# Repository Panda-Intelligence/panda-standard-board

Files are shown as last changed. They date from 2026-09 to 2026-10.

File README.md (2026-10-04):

# Panda Standard Board

Open hardware design sources and engineering documentation for the **Panda Standard Board**, maintained by Panda Intelligence.

## Active Split-C1 prototype and mainland IC continuation

The active continuation is the populated **Core-C1 96 x 68 mm / 4-layer** plus
**Display-C1 45 x 36 mm / 2-layer** design already split and routed on main.
Start with [Split-C1 handoff](hardware/thin18-compact/SPLIT-C1-HANDOFF.md) and the
[PG/PSEL functional migration](hardware/thin18-compact/SPLIT-C1-POWER-INTEGRITY.md).
Do not replace it with Thin7/portrait-R2 experimental CAD merely because an
experiment has a newer timestamp. Thin7 remains a separate, incomplete 7-mm
mechanical target and is not claimed by the Split-C1 bench prototype.

Generate checked prototype data explicitly:

```sh
python3 hardware/thin18-compact/release_split_c1.py --target split-c1
```

Bare-board CAM/DFM, accepted PCBA supply and physical EVT are separate gates.
The new supervisor is a mainland part, but its exact assembly code/receipt is
not yet confirmed. No production qualification or actual purchase is implied.

## Historical published Thin18 baseline

The earlier published integrated-board engineering baseline was:

- **Board:** Thin18 domestic EVT
- **PCB checkpoint:** `routing142`
- **PCB SHA-256:** `ccc19c5402f633638ed72e7c94a92375684037a1f9c04f63072dc58f86c16071`
- **KiCad validation:** 0 DRC violations, 0 unconnected items, 0 schematic-parity errors; ERC 0
- **Status:** engineering / EVT — **not a manufacturing release**

The baseline includes the current right-side microSD access geometry. Manufacturing, assembly, SI/PI, RF, thermal, tolerance-stack and physical EVT qualification remain separate release gates.

## Repository layout

```text
hardware/
  thin18/
    routing142/        Current KiCad engineering baseline and machine-readable verification evidence
docs/
  design/              Electrical architecture, interfaces, power tree, constraints and design rules
  verification/        ERC/layout/fabrication-readiness engineering reviews
  mechanical/          Board/mechanical interface review notes
LICENSES/
```

## Opening the active two-board design

The design was validated with **KiCad 10.0.5**. Open the complete project under:

```text
hardware/thin18-compact/core-c1-96x68-split/eda/core/PANDA-STD-CORE-EVT/PANDA-THIN16/
hardware/thin18-compact/display-c1-45x36-production-bom/
```

Project-local symbol and footprint libraries are included where the design depends on them.

## Product visualization

Explore the [interactive Thin18 routing142 assembly model](hardware/thin18/routing142/visualization/Panda-thin18-routing142-exploded.html) or watch the [exploded-view video on YouTube](https://youtu.be/T_Nb8tvqas8).

The model is an engineering visualization for design communication. Mechanical fit and manufacturing readiness require separate validation.

## Verification boundary

A clean KiCad DRC/ERC result means the design database is internally consistent. It does **not** establish production qualification, regulatory compliance, component derating, RF performance, thermal margin, assembly yield or mechanical fit of real production parts.

Use tagged manufacturing releases, when available, for fabrication rather than assuming the newest engineering checkpoint is production-ready.

## Licensing

Hardware design sources: **CERN-OHL-S-2.0**.

Documentation: **CC BY-SA 4.0**, unless otherwise noted.

Third-party component models, symbols, footprints, manufacturer names and trademarks retain their respective rights and licensing terms.

## Split-C1 executable control follow-up

[Portable bench-control core](firmware/split_c1/README.md) implements tested
XL9535/SGM41513/SGM37601 sequencing and a read-only QMI8658A identity probe.
Host tests and native pin/address binding checks run in the explicit Split-C1
export pipeline. This is not product-firmware integration or physical EVT.
The [hardware-finish ECO](hardware/thin18-compact/SPLIT-C1-HARDWARE-FINISH.md) adds default-off charge authorization and a native GPIO2 shutdown path.
Read the updated control binding before using any older firmware. Physical EVT and accepted assembly supply remain separate gates.

## Current fabrication entry

The combined review package contains a generated `START-HERE.md`; use its
separate Core/Display Gerber paths and source hashes. The
[fabrication handoff](hardware/thin18-compact/JLC-PROTOTYPE-HANDOFF.md) now matches
the native four-layer35um Core copper construction and ENIG/green-mask selection.
C301 now has checked1.9mm round PTHs instead of short slots; the actual stackup
and assembly process still need CAM acceptance.
Native DRC/DFM success is not automatic fabrication/PCBA order approval.

## Split-C1 SMT process selection

The native [assembly-process auditor](hardware/thin18-compact/audit_split_c1_assembly_process.py)
and its tests now run before fabrication export. Core contains13 drilled vias
intersecting SMT copper lands; its order must explicitly include epoxy filling
and copper capping for the generated list. This is distinct from soldermask
tenting/plugging and must not fill component lead holes or slots. The generated
prototype package includes ASSEMBLY-PROCESS.md and per-board VIA-IN-PAD.csv,
bound to the saved PCB and checked against Excellon drill hits. Small WLCSP and
connector lands retain ENIG and need assembler stencil/process confirmation.
No source copper is changed by this audit; supplier acceptance is still required.

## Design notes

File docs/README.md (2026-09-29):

# Documentation index

## Design

- `schematic-spec.md` — board-level electrical design specification
- `power-tree.md` — power architecture and domain behavior
- `interfaces-and-connectors.md` — external and internal interfaces
- `gpio-budget.md` / `i2c-address-map.md` — digital-resource allocation
- `layout-constraints.md` — PCB layout constraints
- `key-calculations.md` / `power-datasheet-calculations.md` — engineering calculations
- `test-points.md` — EVT/debug access strategy
- `symbol-footprint-rules.md` / `symbol-footprint-checklist.md` — EDA library rules

## Verification

Engineering reviews and machine-check boundaries. These documents do not constitute manufacturing release.

## Mechanical

Board-to-enclosure and connector-access review notes.

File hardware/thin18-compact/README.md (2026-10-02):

# Thin18 Compact EVT

## Current product requirement — Thin7 (2026-10-02)

The user requires about **7 mm whole-device thickness**. The previous 21 mm
side-pack study is superseded. See [Thin7 redesign](thin7/THIN7-REDESIGN.md)
and the dimensioned contract. The two routed Split-C1 boards below remain
electrical references; they do **not** satisfy the new mechanical requirement.
Thin7 contains two empty mechanical outline templates, not routed PCBs.
`release_split_c1.py` now rejects the incompatible native CAD before creating
new factory packages. Core relayout, high-part ECOs and battery qualification
are still required.

## Current native electrical reference — Split-C1 (2026-10-02)

The current PCB authorities are core-c1-96x68-split and
display-c1-45x36-production-bom. The Core is 96 x 68 mm / four copper layers;
Display is 45 x 36 mm / two layers. Both boards are 0.8 mm thick and pass
native KiCad DRC/open/parity/ERC = 0/0/0/0.

Run `python3 hardware/thin18-compact/release_split_c1.py` to generate local
production/core-c1-96x68 and production/display-c1-45x36 packages, with
production/split-c1-release.json as their combined hash-checked record.
Generated packages are ignored; the committed authorities are native CAD,
required libraries, replay scripts, purchasing evidence and audit summaries. Every populated BOM ref has Manufacturer and exact MPN.
Current all-domestic audit:155/155 populated system-BOM refs,0 foreign/unknown.
Core has116 SMT placements plus hand-solder C301 and offboard TH301;Display37.
Last foreign refs now use WAVE SD3078/C916255,KAMCAP SE-5R5-D105VYH3C/C2894294
and JSM NX3008NBK,215-JSM/C53113911. Symbols,primary/derived lands and copper
are replayed from guarded source ECOs. R303/R304 are removed.

Exact SMT library coverage:Core110/116,Display37/37. Six Core refs
(U902,U905,U402-U405) still require exact JLC ID/consignment acceptance.
C301 exact current H3C catalog/drawing verified;quantity unverified. D202 observation0;no reserved/accepted supply.
audit_split_c1_domestic.py --require-complete passes identity coverage;
PCBA supply/order readiness remains false.

See SPLIT-C1-DOMESTICIZATION.md and JLC-PROTOTYPE-HANDOFF.md for current
decisions. RTC >=24h isolated backup is a pending prototype validation,
with a2uA total-node engineering target and measured start>=3.15V/end>=2.3V.
Firmware port is required;Q04-Q14 remainNOT_RUN because no board exists.
The historical two-board side-pack study was112x75x21mm (20.5mm budget)
and is rejected for the Thin7 product. Thin7 targets112x75x7.0mm with a
62x51x3.1mm complete-pack maximum requirement. Exact pack/supplier dimensions
and the new PCB layout are not qualified; no physical fit is claimed.
X4 Pro1100mAh/5.95mm remains a reference. Manufacturing release remains false.
Older C0/C2/C4D notes below are historical and do not override Split-C1.

Thin18 Compact is an architecture fork of the validated `thin18/routing142` baseline.

## Goal

Reduce the main PCB below the JLC 100 × 100 mm coupon boundary while making the product materially shorter, without changing the electrical feature set.

C0 target:

- PCB: **70 × 64 mm** placement-feasibility candidate
- hard coupon boundary: every PCB side < 100 mm
- layers: 4
- thickness: 0.8 mm
- finish target: ENIG
- production solder mask target: green
- display architecture: raw 4.26-inch SSD1677 panel through 24-pin / 0.5-mm FPC
- display candidate family: Good Display GDEY0426T82; front-light/touch derivatives require separate stack-up and pin/FPC qualification
- screen, battery and PCB are separate mechanical objects; the PCB no longer follows the panel length

## C0 fold strategy

The routing142 placement already has two dense functional regions:

- y < 31 mm: power, battery/gauge/RTC, audio, microSD, switches
- y > 100 mm: USB-C, ESP32, display power/FPC, protection

Only five footprints occupy the 30–100 mm middle band, two of which are mounting holes. C0 folds the upper region down by 64 mm, keeps the lower region, relocates mounting holes, reduces the board outline to 70 × 64 mm, and intentionally removes all legacy tracks/vias/zones.

This candidate is **placement-only and NOT routed**. routing142 remains the authority for the old form factor.

## Gates before routing

1. no footprint/edge impossibility after connector-specific edge allowances;
2. no unintended footprint overlap;
3. schematic population and pin/net parity unchanged;
4. ERC remains zero;
5. battery/display/enclosure Z-stack is frozen;
6. exact display FPC pinout and front-light/touch variant are frozen;
7. USB-C, microSD, side switches, display FPC and antenna cable exits are mechanically frozen.

Do not fabricate the C0 board.
精确供料跟进：SPLIT-C1-SUPPLY-REQUEST.md、split-c1-supply-plan.json。verify_split_c1_supply.py核对本次8个位号的精确身份、实际回执／数量和C301独立后装路线；不把公开库存或采购准备当作完整PCBA接收。

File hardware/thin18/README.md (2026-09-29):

# Thin18

`routing142` is the currently published engineering baseline.

It is a complete isolated KiCad project snapshot used for reproducible review. Its authority PCB hash is:

`ccc19c5402f633638ed72e7c94a92375684037a1f9c04f63072dc58f86c16071`

The snapshot is **not** a manufacturing release. Do not infer physical qualification from DRC/ERC results.

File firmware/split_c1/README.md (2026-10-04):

# Split-C1 portable bench-control core

This is executable C++17 control logic for the already split Core-C1/Display-C1
board. It is **not** a complete Panda OS board driver or a flashed/tested ESP32
firmware image. The actual ESP-IDF bus adapter, product integration, scheduler,
USB permission events and physical qualification remain open. No current,
voltage, timing or leakage measurement has been performed by the host tests.

## Implemented behavior

`BoardControl::begin()` first drives native GPIO2 LOW, then quiesces the XL9535 outputs, keeping P14 and P15 input-only, then
checks the SGM41513 part-ID class at **7-bit address 0x1A**. It disables charge and
OTG, sets nominal IINDPM100mA, sets ICHG0, enables the40s charger watchdog and charge
safety timer, selects6.5V input OVP, and disables high-voltage current-pulse control.
It preserves unrelated register bits. A historical watchdog flag is retained in
diagnostics during explicit startup; new watchdog/fault events cause a latched
fault. No API enables battery charging, OTG, RTC charging or higher USB voltage.

The GPIO masks are derived and checked against the actual schematic and PCB:
Port0 directions `D0`, Port1 directions `3F`; quiescent latches `00` and `00`. P05 is active-high CHG_REQUEST and stays LOW. P15 is unused; HWEN is no longer an expander output.
Output latches are verified before enabling their output directions. U906's
push-pull PG output drives P14, never the MCU reset input. Switching SD/touch/EPD/
audio rails on is deliberately outside this initial control core; they stay off.

Frontlight startup is staged: HWEN1/PWM0, an engineering10ms settling interval,
then program/readback DC mode, current,18V OVP/internal compensation/2.7V UVLO and
1MHz/PFM. PWM goes high last, after all readbacks and another PG/GPIO check.
Accepted nominal shared current is6.0..14.5mA in0.1mA steps (integer60..145), or0
to turn off. This is NOT independent warm/cool control, hardware PWM dimming,
continuous dimming below6mA or a measured guarantee that each LED stays below15mA.
No nonvolatile MTP access is made. Source changes revoke a previous light request.

`poll()` monitors GPIO latches/directions/polarity, PG, charger policy, historical
and current fault reads, input-detection events, and active frontlight registers. A reset, readback
mismatch, lost PG, missed service deadline or bus failure latches an error and
attempts shutdown. A caller must explicitly restart with `begin()`; no automatic
relighting or watchdog-reset continuation is performed. A new input-detection
flag revokes a prior500mA permission even if the reset current code is unchanged.

The QMI8658A sanity probe reads WHO_AM_I0x05 at **0x6A**, because U503 SA0 is high.
It performs no reset or CTRL9 write and does not disable the internal pull-up on
reserved pin10. It does not implement sampling, FIFO, motion interrupts or
calibration. WHO_AM_I is a QST family sanity check, not a provenance certificate.

## Integration contract

Implement `RegisterBus` using bounded single-register I2C transfers,7-bit
addresses, clock-stretch/error handling and a monotonic millisecond counter.
Use the native pins **SCL GPIO14 / SDA GPIO15** and a shared bus no faster than
100kHz because the existing SD3078 contract requires that rate at3.3V. The bus
adapter must enforce the requested10ms per-transfer timeout. Every control call
and every other device's transaction must be serialized by the board owner.
There must be no second writer to these XL9535/charger/frontlight registers.

Call `poll()` at least once per1000ms, faster for the required fault response.
The10ms settle,100ms startup deadline and1000ms service deadline are conservative
engineering choices, not manufacturer timing guarantees. Calls detect elapsed
time including transfer execution. Unsigned subtraction handles clock wrap;
service must not be absent for an entire32-bit timer period. Tests run with
injected wrap, slow callbacks and expired deadlines.

Example integration structure (adapter/scheduler still needs implementation):

```cpp
panda::split_c1::BoardControl control(bus);
auto result = control.begin();
// Only an independently qualified USB/source event may grant500mA:
if (result == panda::split_c1::Result::Ok && source_has_500ma_permission) {
    result = control.set_source(panda::split_c1::SourceAllowance::Qualified500mA);
}
// set_frontlight(145) returns Pending; subsequent scheduled poll() completes it.
// On any error inspect diagnostics; do NOT automatically re-run begin().
```

Suspend/detach requests put the charger input in HIZ after deasserting the light.
That may cut system power on a batteryless board. Software100/500mA settings and
HIZ are not proof of USB enumeration, inrush, suspend-current or reset compliance.
The pre-AON PSEL divider remains a nominal reset selection, not a hard current cap.

## Hardware-finish compatibility and boundaries

Implement the two additional RegisterBus callbacks with **native GPIO2 only**:
`set_hardware_permit(bool)` and `read_hardware_permit(bool&)`. They must never
call I2C. Set the LOW output latch before enabling output direction; disable
GPIO hold and unintended pulls. Readback samples the MCU pad before R931, not
the downstream TP19 analog voltage. Older adapters intentionally cannot compile
without implementing the direct path.

The hardware now pulls nCE to pre-AON REGN, with two series MOS permissions.
P05 request and direct permit both defaultLOW; the bench controller never enables
P05. This fixes the old default-low nCE topology. Actual startup/ramp, temperature,
partial-power and charging behavior still need prototype measurement.

On I2C loss, native GPIO2 is driven LOW before attempted bus cleanup, so the
inhibit does not depend on a responsive expander. The host model now demonstrates
that path and separately tests simultaneous GPIO+I2C failure as UNKNOWN. A stuck
HIGH GPIO is not reported as confirmed shutdown. Diagnostics distinguish direct
inhibit readback from shutdown-register confirmation. None are current measurements.

A CPU frozen with GPIO2 retainedHIGH is not independently detected by this design:
use TP19 FORCE-LOW access or power removal. There is no external autonomous
watchdog. See ../../hardware/thin18-compact/SPLIT-C1-HARDWARE-FINISH.md.

## Reproduce tests and native binding checks

```sh
python3 hardware/thin18-compact/test_split_c1_control.py
python3 hardware/thin18-compact/verify_split_c1_control.py
python3 hardware/thin18-compact/release_split_c1.py --target split-c1
```

The runner compiles with warnings-as-errors and AddressSanitizer/UBSan, executes
mock transactions (no physical device), and emits a source-hash-bound report.
The checker exports a fresh native netlist, checks actual PCB pads, derives GPIO
masks, checks exact MPNs and rejects wrong-address/direction/strap variants.
`verify_split_c1_control.py --require-target-integration` intentionally exits2:
passing a host test does not complete product firmware integration.

## Primary references

SGMICRO SGM41513 family, April2025 Rev.C.1: printed pp5,23,30,32,37-46.
https://www.sg-micro.com/rect/assets/58a4fe4d-da1d-49a3-b312-5664211d9016/SGM41513_SGM41513A_SGM41513D.pdf

SGMICRO SGM37601, June2026 Rev.A.2: printed pp27-30; see product page for the
current original PDF. Exact populated variant is SGM37601YTRL20G/TR.
https://www.sg-micro.com/product/SGM37601

XINLUDA XL9535/XL9555 Rev2.3: printed pp12-14,19. Original manufacturer document;
mirror used where the manufacturer's PDF endpoint was unavailable.
https://xinluda.com/en/content/viewpdf/aid-578.html
https://wiki.lilygo.cc/datasheet/XL9535.pdf

QST QMI8658A, document13-52-25 RevA: pp11,29,83. Manufacturer document mirror.
https://files.waveshare.com/upload/5/5f/QMI8658A_Datasheet_Rev_A.pdf

See `SPLIT-C1-RTC-FIRMWARE.md` for the separate SD3078 bus/retention contract.

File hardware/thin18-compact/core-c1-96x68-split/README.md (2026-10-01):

# Core-C1 split main board

96 × 68 mm, four copper layers. Native DRC/open/parity/ERC: 0/0/0/0.
J601 is the bottom-side DF40 socket at (61,62) mm, rotation 0°.
The display adapter is removed from this PCB; Display-C1 is a separate candidate.
Active production data is ../production/core-c1-96x68/.
The inherited C4D reports are historical provenance; verification/ and the split
release record contain the current checks. j601-routing.json is search history;
core-c1-routing-closure.json freezes the final, cleaned copper.
manufacturing_release=false; physical EVT and enclosure/battery Z-stack remain open.

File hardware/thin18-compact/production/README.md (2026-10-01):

# Generated Split-C1 fabrication packages

Run `python3 hardware/thin18-compact/release_split_c1.py` from a full-history clone with KiCad 10.0.5 installed.
Outputs are generated locally under core-c1-96x68/, display-c1-45x36/ and split-c1-release.json.
Native CAD, replay inputs, purchasing evidence and validation summaries are versioned; Gerbers, ZIPs, netlists and copied per-package reports are generated and ignored.
Each generated manufacturing package includes BOM/CPL, source hashes, engineering evidence and SHA256SUMS. manufacturing_release remains false until physical qualification is complete.

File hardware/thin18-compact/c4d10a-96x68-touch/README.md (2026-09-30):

# Thin18 Compact C4D-10A — exact touch FPC

J803 uses the exact FH34SRJ-6S-0.5SH(50) / C224194 six-pin footprint. U601 P16/P17 are allocated to TOUCH_INT/TOUCH_RST and two mainland Fenghua pull-ups are added.

Fresh checks: ERC=0, DRC=0, parity=0, open=409 (expected because final routing has not started).

Front-light CAD remains gated and is not included in this stage. Physical qualification remains open.

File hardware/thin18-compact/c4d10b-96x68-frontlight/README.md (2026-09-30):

# Thin18 Compact C4D-10B — mainland dual-string front light

SGM37601YTRL20G/TR drives the FT01C warm/cool strings through exact J804 FPC mapping. The design uses boot-low EN/PWM, 14.5mA nominal current, 18V OVP and 1MHz switching.

Fresh checks: ERC=0, DRC=0, parity=0, open=436 (expected because final routing has not started).

Physical current, thermal, EMI, acoustic and mechanical qualification remain open. Not a manufacturing release.

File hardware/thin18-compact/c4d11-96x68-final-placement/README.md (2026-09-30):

# Thin18 Compact C4D-11 — final placement checkpoint

All 189 footprints are locked on the 96 × 68 mm compact board. No reference, pose, net or footprint geometry changed from C4D-10B.

Fresh checks: ERC=0, DRC=0, parity=0, open=436. The checkpoint is intentionally unrouted and is the input to controlled DSN/SES routing.

Physical battery/FPC/enclosure qualification remains open. Not a manufacturing release.

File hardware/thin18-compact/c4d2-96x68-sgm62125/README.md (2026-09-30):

# Thin18 Compact C4D-2 — SGM62125 AON buck-boost

U902 replaces the populated TPS63802 stage. Legacy U401/R401/R402/R403 remain only as off-board/DNP schematic history. L401 and C401/C402/C403 are reused pending magnetic/DC-bias qualification. Native checks are recorded in c4d2-report.json. Not a manufacturing release.

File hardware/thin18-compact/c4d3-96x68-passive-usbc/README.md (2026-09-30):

# Thin18 Compact C4D-3 — passive USB-C sink

The legacy Type-C controller/LDO/comparator/buffer status chain is removed from the product netlist and PCB. R206/R207 become 5.1k Rd from CC1/CC2 to GND. USB D+/D-, VBUS, ESD and tuning remain intact. Charging status comes from SGM41513. U601 P16/P17 and ESP32 IO2 are explicitly no-connected in this D3 candidate; C4D4 will reclaim P16/P17 for the touch connector. Not a manufacturing release.

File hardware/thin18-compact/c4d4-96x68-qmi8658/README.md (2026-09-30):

# Thin18 Compact C4D-4 — QMI8658A

U503 identity is corrected from LSM6DSO32XTR to QST QMI8658A / C3021082. The existing LGA-14 pin/net contract already matches QMI8658A; no topology change is introduced. Firmware and physical IMU qualification remain open.

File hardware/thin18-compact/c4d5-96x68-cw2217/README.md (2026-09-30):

# Thin18 Compact C4D-5 — CW2217BAAD fuel gauge

BQ27427 is retired from the assembled compact candidate. CW2217BAAD / C5203993 is added with a mainland FOJAN 10mΩ 1W high-side shunt and dedicated VDD/VCELL filters. Native ERC/DRC/parity are clean; board remains intentionally unrouted. Physical gauge accuracy and profile qualification remain open.

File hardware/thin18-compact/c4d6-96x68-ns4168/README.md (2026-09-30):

# Thin18 Compact C4D-6 — NS4168 audio

MAX98357A and its SD/GAIN configuration network are retired. NS4168 / C910588 is added as the mainland I2S mono Class-D amplifier. Fresh native ERC/DRC/parity are clean; board remains intentionally unrouted. Audio/thermal/EMI qualification remains open.

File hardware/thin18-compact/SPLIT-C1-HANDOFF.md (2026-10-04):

# Split-C1 current hardware handoff

## Authoritative continuation

Worktree: `/Users/isaac/workspace/AI/panda-standard-board-main-ic`.
Authoritative branch: `main`. Hardware closure is merged through PR #16
(`ebacff2`), and C301 drilling/fabrication closure through PR #17 (`d77a33c`).
Start new work from current remote main, not an old unmerged experiment.
The user wants the already routed two-board main-branch design finished for
prototype fabrication. Do NOT restart Thin7/portrait-R2 or expand unrelated
firmware. Other worktrees and the original packaging/ directory are untouched.

Native authorities under `hardware/thin18-compact/`:

```
core-c1-96x68-split/eda/core/PANDA-STD-CORE-EVT/PANDA-THIN16/
display-c1-45x36-production-bom/
```

Core96x68mm/4 layers, Display45x36mm/2 layers, both0.8mm. Keep the main-branch
ESP32-S3-WROOM-1U-N16R8 and HCTL60-pin interconnect. Split-C1 does not claim the
separate uncompleted7mm enclosure target.

## Hardware-finish checkpoint

Read `SPLIT-C1-HARDWARE-FINISH.md` and `split-c1-hardware-finish.json`.
The two known static hardware issues are now implemented in schematic and PCB:
REGN-derived default-OFF nCE plus two series MOS permissions, and a native
GPIO2/R931 frontlight/charge inhibit that does not pass through I2C. TP19 is a
manual FORCE-LOW access point. New exact parts Q907/Q908/R930-R933 reuse reviewed
mainland identities and catalog codes. No existing component position, board
outline, rule or Display native design is changed.

PG/PSEL changes from `afd63c6` remain intact. Hardware finish builds on the
`3f350ed` baseline. The isolated candidate and fresh immutable-history rebuild
passed native DRC/open/parity/ERC0/0/0/0 with identical canonical CAD before
adoption. The source-hash checked adoption record and frozen copper delta are
`split-c1-hardware-finish-adoption.json` and `split-c1-hardware-finish-layout.json`.
Use the current generated full validation below as the source of truth.

Expected population:162 mainland system refs (Core125,Display37), with
Core123SMT plus C301 manual/TH301 offboard and Display37SMT.17 board-level
IC/module positions remain; Q907/Q908 are additional discrete MOSFETs.
Seven unmapped/unaccepted SMT refs remain:U402-U405,U902,U905,U906. New finish
parts do not add unresolved SKUs. No quote, order or assembly receipt is fabricated.

## Reproduce the prototype package

```
python3 hardware/thin18-compact/release_split_c1.py --target split-c1
python3 hardware/thin18-compact/verify_split_c1_supply.py --negative-controls
```

The pipeline checks current/rebuilt native CAD, both electrical ECO contracts,
original-maker MOS/supervisor lands,21 invalid hardware-contract cases,60-pin
mapping, host-controller compatibility, exact BOM/CPL, mechanical XY, native
rules, separate PTH/NPTH drills and ZIP CRC/hash evidence. The generated output:
`production/Panda-Split-C1-JLC-Prototype.zip`.
Read `production/jlc-prototype-orderpack/prototype-status.json` for actual
bare-board DFM versus supply status. Stale ZIPs from before hardware finish must
not be submitted. Generated outputs and transient trials stay ignored.

## Important compatibility and physical boundaries

P05 is now active-high CHG_REQUEST (defaultLOW), not old active-low BQ_CE.
P15 is NC/input, P14 remains PG/input, P16 remains PWM. GPIO2 is the independent
permit and must initialize LOW with hold disabled. The portable controller
received only the necessary binding/polarity update and direct GPIO callbacks;
old adapters intentionally cannot compile without implementing those callbacks.
No ESP firmware was flashed or claimed physically qualified.

GPIO2 LOW directly removes frontlight EN and charger permission. This does not
make the circuit an autonomous external watchdog. CPU/GPIO stuckHIGH still
requires TP19 clamped to GND or power removed. A simultaneous failure of I2C and
the native GPIO path must remain UNKNOWN in software, not a fabricated OFF.

Before battery charging, prototype tests must measure REGN/nCE startup,
source-change/reset/Hi-Z states, hot/cold margins, limits and NTC behavior. USB,
SI/PI/RF, thermal/magnetics, RTC retention, actual panel/battery/enclosure and
assembly/supplier acceptance remain physical qualification, not native CAD
connectivity. `manufacturing_release=false`; do not confuse this with the ability
to produce checked bare-board prototype Gerber/drill data.

## Main merge and fabrication entry audit

PR #16 merged the three hardware/control checkpoints into main at `ebacff2`.
The manufacturing entry is now generated from per-board manifests. See
`JLC-PROTOTYPE-HANDOFF.md` and `split-c1-fabrication-contract.json`; do not
reuse old manually maintained counts or the old inner0.5oz order text.
Core native copper construction is nominal35um on all four copper layers.
The exporter corrects only Gerber-job/file metadata (revision, nominal size,
finish/color and unsupported impedance declaration). It leaves native CAD,
drawing/aperture commands and drill coordinates unchanged and verifies them.

C301's obsolete short slots are now replaced with1.9mm round plated holes and
2.3mm lands at the same20mm pitch. All existing tracks/vias and other footprints
remain unchanged. See SPLIT-C1-CAP-DRILL.md and its independent verifier; native
current and immutable-baseline replay must remain0/0/0/0. Actual CAM/assembly
acceptance remains distinct from the completed geometry correction. Reports now distinguish native_rule_dfm_passed
from cam_accepted/automatic_fabrication_order_ready. No approval is invented.

`production/jlc-prototype-orderpack/START-HERE.md` is generated, not copied
from historical prose. `verify_split_c1_fabrication.py` rechecks layer functions,
plated/nonplated drills, per-board source identities and every package checksum.
The power verification hashes the semantic netlist rather than its changing
export timestamp; power-pin/variant validation has not been relaxed.

## SMT via-process closure — 2026-10-04

PR #17 was pushed, freshly validated and merged by explicit user request. This
process follow-up starts from the merged main, without native PCB/schematic,
footprint, layer, rule or firmware edits.

Fresh native shape screening finds269 Core through vias,13 of whose drill circles
intersect exposed SMT copper lands (including near-edge intersections); Display
has36 vias and0 such intersections. Core **requires Epoxy Filled & Capped** for
the listed sites, not mere soldermask tenting/plugging. C301 lead holes, USB slots,
component PTH and NPTH are not via-fill targets. Full via treatment may cover
Core's269-via inventory only after CAM agrees the scope.

The new native auditor compares actual filled copper polygons to drill circles,
not bounding boxes or the annular copper diameter. It rejects unsupported pad
voids/blind vias, records nominal geometry and the1um polygon tolerance, and
separately lists0.22/0.23mm WLCSP and small rectangular SMT lands for ENIG/stencil
review. It does not certify solder paste apertures, fabricated tolerances or yield.

`audit_split_c1_assembly_process.py` plus31 synthetic tests are required by the
existing release command. `split-c1-assembly-process.json` records source hashes,
via UUIDs and the measured list. The generated packet includes
`ASSEMBLY-PROCESS.md`, `assembly-process.json` and per-board `VIA-IN-PAD.csv`.
The final fabrication verifier matches the entire via inventory against actual
PTH Excellon hits and checks the copied maps and requirements. Do not silently
select ordinary open vias for Core when submitting the Gerbers.

All162 exact mainland identities and the seven supplier-acceptance gaps remain
unchanged. Actual fill/cap quote, CAM acceptance, stencil approval, assembly and
physical EVT are not closed by generating this record.

SMT-pad identifiers in process reports use canonical copper-shape hashes, not
KiCad runtime-generated UUIDs for legacy pads without stored IDs. Consecutive
fresh native loads must produce byte-identical process reports. No pad or via
is edited to normalize the report. Via UUIDs remain the stored native IDs.

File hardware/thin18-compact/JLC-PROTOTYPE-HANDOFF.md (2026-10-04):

> **2026-10-04 SMT 過孔工藝補充：Core 有13顆孔與SMT銅焊盤相交，須明確指定
> Epoxy Filled & Capped，至少覆蓋本包逐板VIA-IN-PAD.csv。一般蓋油／塞油不得替代；
> C301引腳孔、USB槽及其他元件PTH／NPTH不能填堵。詳見自動生成的ASSEMBLY-PROCESS.md。
> 這是製程要求，不是已取得CAM／貼片接收。

# Split-C1 工程打樣交接

目前主線是已完成拆板的 Core-C1＋Display-C1。Thin7／portrait-R2 是另一個未完成的機構方案，不能替代本次台架原型的來源。

## 唯一製造入口

在完整 Git 歷史的工作目錄執行：

```sh
python3 hardware/thin18-compact/release_split_c1.py --target split-c1
```

產出 `production/Panda-Split-C1-JLC-Prototype.zip`。總包內的 **START-HERE.md** 由這次已核對的 PCB、BOM、Gerber 與製程契約自動生成；位號數、缺料位號、來源雜湊及分板檔名均以它為準。這份文件不再疊加已失效的歷史說明。

裸板分別上傳：

```text
Core-C1/Core-C1-Gerber-Drill.zip
Display-C1/Display-C1-Gerber-Drill.zip
```

不要把完整總包當成單板 Gerber，也不要加入舊整合板或 Thin7 空板框。

## 板廠參數

| 項目 | Core-C1 | Display-C1 |
|---|---|---|
| 名義成品尺寸 | 96 × 68 mm | 45 × 36 mm |
| 銅層順序 | F.Cu／In1.Cu／In2.Cu／B.Cu | F.Cu／B.Cu |
| 名義板厚 | 0.8 mm | 0.8 mm |
| 從上到下銅厚 | 35／35／35／35 µm | 35／35 µm |
| 表面／阻焊 | ENIG／綠油 | ENIG／綠油 |
| 板型 | 單板、銑外形 | 單板、銑外形 |

**Core 內銅約 1 oz，不是旧表中的 0.5 oz。** 此項保持原生 CAD 的銅厚，不能直接接受板廠預設較薄內銅。原廠公開能力列出內銅 0.5／1／2 oz，0.5 oz 是預設；實際層疊、0.8 mm 公差與訂單選項仍需 CAM 確認。

製造匯出會保留原始 KiCad job 作核對，再修正交付 `.gbrjob` 的來源版本、名義尺寸、ENIG 與綠油。原來無對應阻抗配方的 `ImpedanceControlled` 聲明不再出現在交付 job。這不是取消電氣／阻抗要求，也不是宣告阻抗測試通過；禁止擅自改線寬或堆疊。銅箔、阻焊圖形、外形與鑽孔座標均不因這項元資料處理而改變。

## 必須取得的 CAM 確認

Core C301 現在使用 **1.9 mm 鍍通圓孔／2.3 mm 圓焊盤**、20 mm 腳距，已消除原本短橢圓槽的加工例外。每個孔的位置、孔徑與極性都由原生 CAD 和鑽孔匯出核對；不改成 NPTH，不回用舊槽孔。公差計算與首板插入／手焊條件見 `SPLIT-C1-CAP-DRILL.md`。

Core 包含 0.20 mm 小孔；USB 外殼槽和 C301 圓孔在 PTH 檔。PTH、NPTH 兩份檔案都保留。Display 的 NPTH 檔可以是零孔，不應因此猜測檔案遺失。兩板不要縮放、整體鏡像或對調內層。

正式 PCBA 還需要封裝供料、WLCSP／細間距、過孔處理、鋼網、工藝邊及底面旋轉確認。沒有批准的組合拼板；單板 CPL 不能直接當作拼板 CPL。Assembly-Bottom.svg 是觀察圖，不是額外鏡像座標的指令。

## 裝配與後裝

`BOM_JLCPCB.csv` 只對應同板 `CPL_JLCPCB.csv` 的 SMT 位號。完整系統 BOM 另包含後裝 C301 與板外 TH301。TP19 是裸銅測試點，不是漏貼元件。

C301 精確料號是 KAMCAP SE-5R5-D105VYH3C／C2894294；正端接 pad1 RTC_VBACKUP，負端接 pad2 GND。獨立供料，PCBA 回板後手焊，不混入 SMT 回流；引腳修剪、毛刺及 1.5 mm 板間隙按硬體交接要求核對。TH301 固定於電池並接 J302；浮地 BTL 喇叭 J502 兩端不可接地。

Core J601 與 Display J1 使用同廠配套 HCTL 60-pin 連接器。插接方向、pin1、35/36 電源及底面旋轉按生成圖確認；不混用旧 Hirose 件。Q907／Q908／Display Q1 的 JSM MOS 是 **1G／2D／3S**，不可套用別家同外形的腳序。

七個既有 SMT 位號 U402–U405、U902、U905、U906 仍需精確映射或客供接收。參見生成包的 sourcing、consignment 與 supply-plan 記錄。公開庫存、已有 C 碼或全國產身份都不代表料已預留／被裝配廠接收；不得不貼或相似料號替代。

## 首板上電與放行邊界

先按 `SPLIT-C1-HARDWARE-FINISH.md` 接地 TP19，撤銷前光／充電許可，再做限流上電、電源與極性檢查。P05 已是主動高 CHG_REQUEST，P15 不再控制前光，GPIO2 為直接硬體許可；舊韌體不相容。

零原生 DRC／未連接／一致性／ERC，以及不可變基線重建一致，是設計資料檢查；不是 CAM、貼片供料或實板驗證。USB／充電／NTC／溫升／RF／面板／RTC 以及電池機構仍按首板計畫測試。沒有外部自動看門狗、沒有宣稱已通過實板測試。

`ready_for_cam_review=true`；`cam_accepted=false`、`automatic_fabrication_order_ready=false`、`assembly_order_ready=false`、`manufacturing_release=false` 直到各自條件取得證據。生成入口會清楚顯示這些不同狀態。

## 參考與可追溯性

製程能力原廠來源（2026-10-04 核對）：https://jlcpcb.com/capabilities/pcb-capabilities 。Gerber job 用於傳遞製造特性：https://www.ucamco.com/en/gerber 。

實際契約為 `split-c1-fabrication-contract.json`；各板 `fabrication.json`／`FABRICATION.md` 包含來源與槽孔／圖層核對。`SHA256SUMS` 覆蓋總包，最後的 `verify_split_c1_fabrication.py` 重新比對分板與總包。生成檔案留在 production，不把大型 ZIP 混進 CAD 原始碼。

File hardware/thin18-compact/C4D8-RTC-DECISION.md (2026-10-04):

> Current manufacturing ECO: C301 keeps the exact H3C part and20mm pitch but now
> uses1.9mm round PTHs/2.3mm lands. Older slot dimensions below are superseded by
> SPLIT-C1-CAP-DRILL.md and the fresh native/manufacturing checks.

# Split-C1 国产 RTC 与 24 小时备援设计
2026-10-02。当前只有 Core-C1、Display-C1 两板设计，没有真实样板。U302、C301 已实施国产原型 ECO；24 小时断开 USB／主电池后仍保持有效时间的要求不变。整机阅读续航是另一项指标。

| 位号 | 当前精确选择 | 设计改变 |
|---|---|---|
| U302 | WAVE SD3078 / C916255 | 8脚208mil宽体SOP；引脚／符号／旁路／PCB走线全部重做 |
| C301 | KAMCAP SE-5R5-D105VYH3C / C2894294 | 1F、5.5V、水平通孔可充电超级电容；明确20mm现行改型，SMT之后手工焊接 |
| R303、R304 | 已移除 | 撤销未使用EVI和备援短接支路；不存在10k备援负载 |

[SD3078原厂Rev4.4](https://www.whwave.com.cn/filedownload/3045413)，SHA256 a11cb8cfb0cca2e2f44d137f7d1cff6a0ba4d2e7c7211c9058fa967b95c9231c。厂家为深圳市兴威帆电子技术有限公司。原厂1SCL、2F32K、3VDD、4NC、5VBAT、6GND、7INT、8SDA。F32K/NC不连接，INT保持共享开漏EXP_INT。VDD2.7..5.5V、VBAT2.3..3.6V；3.3V总线使用100kHz、7位地址0x32。备援0.8µA只是25°C典型值，未发布最大值；MSL3。原厂最大安装高1.9mm。焊盘2.0×0.7mm、1.27mm脚距、两行中心距7.3mm为依据尺寸推导的工程焊盘，不是厂家推荐焊盘。

[电容原厂2020年6月规格](https://atta.szlcsc.com/upload/public/pdf/source/20210914/37A5D1176C23A52D8BA2A343DB47BCB6.pdf)，SHA256 494434d2d504d277f3fe46b967d16e752efe29c1a6e4976cda5cfd0a65c74c40。KAMCAP为锦州凯美能源有限公司。现行精确H3C/C2894294已明确选入CAD；旧H/C118887及VYV3C立式不代用。容量0/+30%，1F按4.4→2.75V放电测量，不构成本设计3.15→2.3V容量保证。p4尺寸ΦD18.7±0.5、L5.3±0.5、整体H6.0±0.5mm，包络直径19.2／高6.5mm；脚距20±0.5mm，扁脚宽1.0±0.1、厚0.2±0.05mm。工程焊盘2.4×2.0mm／镀通槽1.8×1.4mm，20mm间距；扁脚宽沿槽短轴，脚厚及脚距偏差沿长轴，公差余量仍需实物检验。图纸有正负符号、未编PCB脚号：负极标记端接pad2 GND，另一正端接PCB“+”／pad1。

C301在(59.4,43.5)，U302在(73,27.5)。C302保留100nF VDD旁路，移到RTC附近。旧EVI/备援铜和悬空线撤销，I²C避开新电容孔；冻结铜图及源哈希见split-c1-rtc-layout.json。当前／基线重建的DRC、未连接、原理图一致性与ERC必须全部0。没有放宽铜间距或孔间距规则。

电容在SMT完成后独立后装，不回流。原厂260°C／≤5秒的p7条件以1.6mm PCB为依据；Core为0.8mm，必须使用经验证的手焊温度／时间／支撑，不把原条件宣称为本板合格工艺。本体离PCB暂留0.2mm，Core背面引脚剪到≤0.5mm并查毛刺、绝缘及1.5mm板间隙。前侧最大6.5mm整体包络使厚度预算达到20.5mm，壳体空间框取112×75×21mm；未冻结可制造外壳。

本节点是可充电超级电容，固件每次主电上电必须按原厂写保护顺序设置18H=0x82（充电允许、2kΩ）；禁止装一次性原电池。原型预充暂按6小时，但断电测试前必须实测VBAT≥3.15V，不能仅按时间推定充满。原厂内部3.3V充电电路没有给出本设计条件的最小终端电压或电容漏电上限，因此该起点是验收条件，尚非保证。

t = C有效 × (V起点−V终点) / I总。目标总节点电流≤2µA，含RTC、自放电、污染及其他漏电；终点2.3V。H3C虽为0/+30%容量，仍保留0.8低电压容量工程折减，因为原厂测量窗口不覆盖RTC窗口；再乘0.7老化预算得室温0.56F／66.11h，−25°C乘0.5得0.28F／33.06h。4µA冷角仅16.53h不能满足24h。这些系数、2µA和估算均非实测或寿命保证；起点、电流、低压容量或批准条件不满足须改图。电容−25..70°C，不能借RTC范围扩大系统范围。

驱动迁移契约见SPLIT-C1-RTC-FIRMWARE.md。仓库没有可集成的产品固件项目，文档不代表驱动已移植或测试。Q14仍须在样板后验证≥24h有效时间、起终电压、节点电流、RTCF/OSF/BLF及批准常温／冷／热／寿命条件；主电池、USB、调试器及信号不得反向供电。Q04–Q14全部NOT_RUN。

C916255公开观察4674件未预留；[H3C/C2894294精确目录](https://item.szlcsc.com/3128601.html)已核对厂家／MPN／盒装，未取得可核实的当前库存数量。公开JLC响应返回其他型号，已排除，不能推定立创库存为0。实际批次／数量／后装接收仍待闭环；六个SMT映射及PCBA接收仍未完成。

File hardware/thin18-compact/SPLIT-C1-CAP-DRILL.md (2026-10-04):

# C301 round plated-hole manufacturing ECO

## Reason and exact change

The previous C301 1.8x1.4mm plated oval slots had a length/width ratio below the
fabricator's published2:1 guidance. Merely obtaining KiCad0DRC did not resolve
that manufacturing issue. Enlarged-slot trials interfered with existing inner
routing and were not adopted.

The accepted geometry instead uses **two1.9mm nominal finished round PTHs with
2.3mm round copper lands**, preserving C301's position(59.4,43.5),20mm pin pitch,
positive pad1RTC_VBACKUP and negative pad2GND. The nominal annular ring is0.20mm.
The exact KAMCAP SE-5R5-D105VYH3C/C2894294 remains unchanged. These are reviewed
engineering lands, not a claim that the manufacturer recommends this PCB pattern.

All track/via objects and every other footprint remain unchanged. The body
courtyard,cap polarity mark,board outlines,layer stack and design rules stay.
Only C301 embedded/library lands,drills,description and refilled copper zones
change. `build_core_c1_split.py` applies `_split_c1_cap_drill_eco.py` after the
prior electrical ECOs,so immutable-baseline replay remains reproducible.

## Insertion-envelope screen

KAMCAP2020.6 specification p4 gives pitch20+/-0.5mm,lead width1.0+/-0.1mm and
thickness0.20+/-0.05mm. The JLCPCB capability page gives through-hole lower
size tolerance-0.08mm and hole-position tolerance+/-0.075mm. Using these as
explicit fabrication assumptions,and centering the capacitor between the two
actual hole centers:

- Lead circumscribed radius: hypot(1.1/2,0.25/2).
- Conservative per-lead center offset: hypot(0.5/2+0.075,0.075).
- Minimum assumed finished-hole radius: (1.9-0.08)/2=0.91mm.
- Calculated radial margin is positive; `verify_split_c1_cap_drill.py` records
  the exact result and rejects an undersized nominal hole or reduced annular ring.

This screen is not an insertion test or solder-joint qualification. Actual lot
geometry,finished-hole/plating tolerance,lead coplanarity,solder fill and body
support must be checked at first assembly. The part is still manually installed
after SMT; trim and insulate rear leads as specified by the existing handoff.
No external force or permanent lead bending is assumed by the calculation.

## Export and verification

The native checker verifies circular shape,1.9mm drill,2.3mm land,20mm pitch,
pose,MPN,polarity and rejects obsolete slot geometry. The exported Excellon audit
requires1.9mm ROUND PTH hits at(49.4,43.5) and(69.4,43.5),not G85 slots.
Remaining Core USB slots are retained. Current and reconstructed native boards
must still pass DRC/open/parity/ERC0/0/0/0 before package generation.

## Primary references

KAMCAP exact model specification2020.6,p4 dimensioned drawing and tolerances:
https://atta.szlcsc.com/upload/public/pdf/source/20210914/37A5D1176C23A52D8BA2A343DB47BCB6.pdf

Fabricator capability,checked2026-10-04:plated-slot2:1 guidance,hole-size and
position tolerances,and multilayer1oz annular-ring recommendation0.20mm:
https://jlcpcb.com/capabilities/pcb-capabilities

No CAM acceptance,actual supply,physical EVT or manufacturing release is implied.

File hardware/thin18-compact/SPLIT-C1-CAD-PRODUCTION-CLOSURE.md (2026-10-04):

> **Current hardware-finish checkpoint (2026-10-04):** use the freshly regenerated
> Split-C1 package, not an older ZIP. Default-off charger authorization and direct
> GPIO2 shutdown are implemented. Population is now **162 mainland system refs**
> (Core125/123SMT + C301/TH301; Display37/37SMT). New Q907/Q908/R930-R933 reuse
> reviewed exact catalog identities; the same7 older SMT supply gaps remain.
> Read [hardware finish](SPLIT-C1-HARDWARE-FINISH.md) for TP19 FORCE-LOW access and
> incompatible old firmware. Earlier156-ref and missing-hardware-gate descriptions
> below are historical; real source-bound generated audits override old counts.

# Split-C1 CAD and Manufacturing-Data Closure

> Current Split-C1 power-integrity ECO: the saved main-derived board now adds
> U906 SGM809B-TXN3LG/TR, reuses R201/R204 for REGN-derived PSEL and moves C204
> to supervisor bypass. Expected current BOM: 156 mainland refs (Core119,
> Display37), Core117 SMT + 2 manual/offboard, Display37 SMT. Seven SMT refs
> remain unmapped (U902,U905,U402-U405,U906). Older observations below retain
> their dates; use [the current power contract](SPLIT-C1-POWER-INTEGRITY.md),
> regenerated audits and the handoff for the current source. No actual stock,
> assembly acceptance or physical EVT result is asserted.

Date: 2026-10-01
Baseline: 60de713, branch hw/thin18-compact-evt.
Final architecture: Core-C1 + Display-C1. C4D-12..20 intermediate snapshots remain in Git history.

| Board | Nominal dimensions | Copper layers | DRC | Open | Parity | ERC | BOM refs | SMT CPL refs |
|---|---|---:|---:|---:|---:|---:|---:|---:|
| Core-C1 | 96 × 68 mm | 4 | 0 | 0 | 0 | 0 | 118 | 117 |
| Display-C1 | 45 × 36 mm | 2 | 0 | 0 | 0 | 0 | 37 | 37 |

Fresh native KiCad 10.0.5 checks include all severities and schematic parity.
No routing-rule reductions, new DRC exclusions, or signal no-connect substitutions were used.
All populated BOM entries have Manufacturer and exact MPN. BOM/CPL refs reconcile.

## Native authorities and generated artifacts

- Core candidate: core-c1-96x68-split/
- Display candidate: display-c1-45x36-production-bom/
- Generated Core package: production/core-c1-96x68/
- Generated Display package: production/display-c1-45x36/
- Generated combined record: production/split-c1-release.json
- Interface contract: split-c1-interface.json
- Reviewed copper replay: core-c1-routing-closure.json

Both packages contain generic BOM/CPL, Gerbers, separate PTH/NPTH drills,
CRC-checked Gerber ZIP, JLC BOM/CPL, assembly-sourcing CSV, native check reports,
production manifest, board release-candidate record and SHA256SUMS.
Blank LCSC IDs remain explicit MPN/consigned-part sourcing tasks:
Core has6 SMT refs requiring exact mapping/consignment,plus2 manual items
(C301 on-board hand-solder and TH301 offboard);Display has0 missing IDs.
Current155-ref domestic identity audit is complete;actual PCBA supply/acceptance
is not. See SPLIT-C1-PROCUREMENT-QUESTIONS.md and split-c1-smt-consignment.json.

## Electrical and mechanical interface

Core J601 is HCTL HC-PBB40C-60DS-0.4V-1.5-02, B.Cu, 0°, center (61,62) mm.
Display J1 is HCTL HC-PBB40C-60DP-0.4V-02, B.Cu, 0°, center (23,4) mm.
The socket orientation was corrected from the exploratory 180° placement.

All 60 pins are verified against both PCB pads and schematic netlists:
6 signals, 2 EPD logic supply pins, 23 GND pins, and 29 explicit reserved NC pins.
All adapter refs C801-C813, D801-D803, U801-U803, R801-R814, J802, L801,
Q801 and TP801-TP806 are absent from the Core PCB.

With opposite B.Cu mounting faces, the Display-to-Core transform is:
x_core = x_display + 38; y_core = 66 - y_display; z_core = -1.5 - z_display.
The display board projects to x=38..83, y=30..66 mm inside the Core outline.
All pin columns and odd/even rows align under this transform.
Socket and plug solder-land row centers differ by 0.185 mm by design;
solder lands on separate boards are not contact-position datums.
Hirose specifies this receptacle/plug mating family and 1.5-mm mated board gap.

Authoritative connector sources:
- https://www.hirose.com/en/product/p/CL0684-4004-6-58
- https://www.hirose.com/en/product/p/CL0684-4003-3-51
- https://www.hirose.com/en/product/series/DF40

## Rebuild and export

Run this from the repository root using Python 3.10+ and KiCad 10.0.5:

```sh
python3 hardware/thin18-compact/release_split_c1.py --target split-c1
```

The command rebuilds both candidates into temporary directories, compares native
CAD and procurement properties, runs the 60-pin interface and mechanical audit,
exports both boards, checks BOM/CPL, validates ZIPs and freezes SHA256SUMS.
It also binds physical qualification to both current PCB identities.
Only native source/config/library files, scripts, purchasing evidence and concise
audit summaries are committed. Gerbers, ZIPs, XML netlists and duplicated package
reports remain generated outputs; they are covered by the local package hashes.

KiCad is discovered on PATH with the macOS application fallback. Set KICAD_CLI
and KICAD_PYTHON for other installations; KICAD_PYTHON must import wx and pcbnew.
The immutable replay source is Git commit
60de7135de31d4e49fd8351565e4e34d60a4af96. Use a full-history clone. If the source
commit is absent after a shallow or squash-only checkout, retrieve the original
PR history first:

```sh
git fetch origin refs/pull/7/head
```

The helper selects native CAD/library inputs from that commit and excludes old
verification reports, route-search outputs and intermediate snapshots.
Existing candidates are preserved by default. Builders refuse to overwrite them.
Use a fresh --output directory to reproduce either candidate.
Core builds replay the reviewed copper closure and require native 0/0/0/0.
A fresh Core replay and fresh Display rebuild both passed 0/0/0/0;
the replayed Core copper digest matches the frozen routing.

export_production.py supports separate PCB/schematic paths and detects the
actual copper-layer count. It blocks exports on CAD failures, incomplete
Manufacturer/MPN, dimension mismatch, missing drill files, or ZIP corruption.
For individual steps, run validate_split_c1.py, then audit_split_c1_mechanical.py,
export_production.py and export_jlc.py for each board, then freeze_split_c1_release.py
to verify all hashes and write both board records and the combined record.
The geometry-search tools are optional engineering tools; the frozen closure
rebuild requires only the standard Python library and installed KiCad.

## Gates deliberately still open

manufacturing_release=false.

The actual enclosure/component Z-stack and physical connector mating are not
verified. The existing rear-battery envelope overlaps the display XY projection;
the full battery rectangle intersects the mating connector region and must
sit outside the interboard gap. A parameterized rear-layer proposal and native
XY audit are now recorded in SPLIT-C1-MECHANICAL-SOURCING.md. Battery dimensions,
swelling, supports and service clearance remain unverified. J201 midmount body,
shell stakes and solder require a Z-clearance check at the Display edge.
Panel/FPC insertion, retention and actual fit remain physical gates.

USB-C compliance, USB2 SI, charging/NTC, ship mode, deep sleep, front-light current
accuracy, OVP/open-string behavior, capacitor DC bias, hot diode leakage, magnetics
temperature/EMI/acoustics, RF, thermal and soak require real boards and instruments.
CAD-clean manufacturing data does not mark these physical tests as passed.

Foreign parts blocked by electrical or mating contracts remain retained as
specified in the handoff. Further localization belongs in a qualified sourcing ECO.

## PR artifact policy

The PR previously contained 1,199 files and 825,769 added lines, including ten
C4D-12..20 candidate trees (two C4D-14 trees), copied historical reports and
three generated production packages. These trees and generated copies have
been removed from the current tree without rewriting Git history. The current
Core and Display native CAD and their required libraries remain reviewable.
No KiCad native design, custom rule or required source library is discarded.
The historical C4D-20 manifest with machine-specific absolute paths is archived;
the current exporter rejects candidates outside the checkout before writing
outputs and records repository-relative artifact paths.

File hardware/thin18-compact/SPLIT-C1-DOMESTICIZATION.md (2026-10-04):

> **Current hardware-finish checkpoint (2026-10-04):** use the freshly regenerated
> Split-C1 package, not an older ZIP. Default-off charger authorization and direct
> GPIO2 shutdown are implemented. Population is now **162 mainland system refs**
> (Core125/123SMT + C301/TH301; Display37/37SMT). New Q907/Q908/R930-R933 reuse
> reviewed exact catalog identities; the same7 older SMT supply gaps remain.
> Read [hardware finish](SPLIT-C1-HARDWARE-FINISH.md) for TP19 FORCE-LOW access and
> incompatible old firmware. Earlier156-ref and missing-hardware-gate descriptions
> below are historical; real source-bound generated audits override old counts.

# Split-C1 全量国产化设计记录

> Current Split-C1 power-integrity ECO: the saved main-derived board now adds
> U906 SGM809B-TXN3LG/TR, reuses R201/R204 for REGN-derived PSEL and moves C204
> to supervisor bypass. Expected current BOM: 156 mainland refs (Core119,
> Display37), Core117 SMT + 2 manual/offboard, Display37 SMT. Seven SMT refs
> remain unmapped (U902,U905,U402-U405,U906). Older observations below retain
> their dates; use [the current power contract](SPLIT-C1-POWER-INTEGRITY.md),
> regenerated audits and the handoff for the current source. No actual stock,
> assembly acceptance or physical EVT result is asserted.

2026-10-02。当前只有Core-C1／Display-C1两块PCB设计，没有实物样板。所有已装配BOM位号使用中国大陆厂家身份；这项身份审计与电气、固件、实际供料及EVT分别验证。

**155个已装配系统位号全部为大陆厂家，0进口、0未知。** Core118个（116SMT、板上手焊C301、板外TH301），Display37SMT。R303、R304已移除；DNP不计入。当前实施94个位号、39组受控替换，另有C516本地输出旁路。完整身份／原厂来源和ECO见split-c1-domestic-policy.json、split-c1-domestic-eco.json、split-c1-domestic-audit.json。

## 已实施国产ECO
| 板 | 位号 | 当前厂家／精确MPN | 精确C码 |
|---|---|---|---|
| Core-C1 | R201 | FH (Fenghua Advanced) / RS-03K5601FT | C99891 |
| Core-C1 | R204 | FH (Fenghua Advanced) / RS-03K1201FT | C118396 |
| Core-C1 | R510, R511, R512, R513, R523, R524, R525, R526, R527, R528, R600 | FH (Fenghua Advanced) / RC-02K1002FT | C140215 |
| Core-C1 | R501, R502, R507, R604, R605, R606, R607, R608, R609, R610, R611, R612 | FH (Fenghua Advanced) / RC-02K1003FT | C140219 |
| Core-C1 | R508, R509, R514, R515, R516 | FH (Fenghua Advanced) / RS-05000FT | C132364 |
| Core-C1 | R517, R518, R519, R520, R521, R522 | FH (Fenghua Advanced) / RS-03000FT | C136582 |
| Core-C1 | R529, R530 | FH (Fenghua Advanced) / RC-02K22R0FT | C324769 |
| Core-C1 | R613, R614 | FH (Fenghua Advanced) / RC-02K2201FT | C140192 |
| Core-C1 | R615 | FH (Fenghua Advanced) / RS-03K5231FT | C140082 |
| Core-C1 | R616 | FH (Fenghua Advanced) / RS-03K3012FT | C321843 |
| Display-C1 | C4, C5, C6, C7, C8, C9 | FH (Fenghua Advanced) / 0805B475K250NT | C37818 |
| Display-C1 | C10 | FH (Fenghua Advanced) / 0805B105K250NT | C89190 |
| Display-C1 | C11, C12, C13 | FH (Fenghua Advanced) / 0603B104K250NT | C694249 |
| Display-C1 | R1, R2, R3, R4, R5 | FH (Fenghua Advanced) / RC-02K22R0FT | C324769 |
| Display-C1 | R6 | FH (Fenghua Advanced) / RC-02K1000FT | C140217 |
| Display-C1 | R7, R8, R9, R10, R11, R12 | FH (Fenghua Advanced) / RC-02K1003FT | C140219 |
| Display-C1 | R13 | FH (Fenghua Advanced) / RS-03L2R20FT | C322118 |
| Display-C1 | R14 | FH (Fenghua Advanced) / RC-02K1002FT | C140215 |
| Core-C1 | U402, U403, U404, U405 | SGMICRO / SGM2578SDYG/TR | 未确认 |
| Display-C1 | D1, D2, D3 | JSCJ / MBR0530 | C77336 |
| Core-C1 | J601 | HCTL / HC-PBB40C-60DS-0.4V-1.5-02 | C19089250 |
| Display-C1 | J1 | HCTL / HC-PBB40C-60DP-0.4V-02 | C19089235 |
| Core-C1 | TH301 | Nanjing Shiheng Elec / MF52D-103F3435-100 | C394023 |
| Core-C1 | J302 | HCTL / HC-1.0-3PWT | C2845362 |
| Core-C1 | J502 | HCTL / HC-1.0-2PWT | C2845361 |
| Core-C1 | L401 | Sunlord / MWSA0402S-R47MT | C6331050 |
| Core-C1 | L402 | Sunlord / MWSA0402S-1R0MT | C408332 |
| Display-C1 | L1 | Sunlord / SWPA3012S470MT | C83420 |
| Core-C1 | J803, J804 | XKB Connection / X05A10H06G | C528032 |
| Core-C1 | J201 | MUP / U20405-01 | C20624794 |
| Core-C1 | SW201, SW202 | XKB Connection / TS-1186E-B-B | C2885153 |
| Core-C1 | D202 | SGMICRO / SGM05HU1ALXUGY2G/TR | C55274065 |
| Display-C1 | J2 | XKB Connection / X05A10L24G | C2880917 |
| Core-C1 | D201 | LRC / LRC8804FDT1G | C2856698 |
| Core-C1 | J301 | HCTL / HC-HY-2AWT | C2845705 |
| Core-C1 | J501 | XUNPU / TF-122-CCP9 | C41347844 |
| Display-C1 | Q1 | JSMSEMI / NX3008NBK,215-JSM | C53113911 |
| Core-C1 | U302 | WAVE / SD3078 | C916255 |
| Core-C1 | C301 | KAMCAP / SE-5R5-D105VYH3C | C2894294 |

## 与原器件存在差异的资格项

- U402–U405：选用 SGM2578SDYG/TR，主动高电平、QOD、2A；独立 WLCSP 封装采用原厂 0.5mm 球距、0.22mm 圆焊盘、最大 0.93mm 本体和 0.493mm 高度，符号引脚 A1=OUT、A2=IN、B1=GND、B2=ON。Jan.2026 Rev.A.2 第9页明确 ON 高/低均有 RCB，但首页仍有“when disabled”概述冲突；装配前需原厂确认该具体 SD 版本的 enabled-state RCB，首板测开启/关闭反灌、爬升及外设时序。典型参数不能代替最坏值资格。
- 增加 C516：FH 0603B105K250NT / C59302，1uF、25V、X7R、±10%、0603，直接接 U403 的 3V3_TOUCH_SW 输出和 GND。底面中心(37.9,15.9)位于 Display 投影之外；供电接现有输出过孔，地回流新增 0.4/0.2mm 过孔(36.25,19.225)。已有 SD 和音频输出电容保留；Display 输出负载电容位于匹配子板，线缆/断开子板工况必须测。
- 0Ω电阻：FH 原厂跨接电阻规范 I12.0 对 F 等级 0603/0805 的额定电流分别为 3A/4A（70°C），最大阻值10mΩ；2A时上界40mW。高温降额、充放电峰值及焊接温升仍测，不能按旧厂家的0Ω电阻阻值等级推断。
- Display R13：风华 RS-03L2R20FT 为2.2Ω±1%、100mW，TCR250ppm/°C高于旧料100ppm/°C。60°C温差的附加变化约1.5%/33mΩ；需重核 RESE 电流限制最坏角。
- Display C4–C9：4.7uF/25V/0805 的 X5R 改为 X7R，厂家最大高度1.45mm；C11–C13 最大高度0.9mm。有效直流偏压容量、EPD纹波/刷新、热循环及装配高度待验证。
- Display D1–D3：JSCJ MBR0530 的原厂推荐焊盘0.94×0.91mm、中心距3.3mm，pin1为阴极；独立封装已应用。0.5A时 VF 最大0.55V，旧 onsemi 为0.43V；最大反漏也不同。EPD升压效率、纹波、调节范围及温升待测。
- J601/J1：整对更换 HCTL DS1.5/DP，60针0.4mm间距、名义1.5mm配合高。逐一核对原厂图中 DS 0.2×0.7mm、行中心±1.54mm；DP 0.23×0.66mm、行中心±1.355mm及四支撑焊盘。当前几何相符，保留网线和60针映射，移除不适用的 Hirose 3D 模型。额定0.3A/触点、最大接触电阻90mΩ、30次插拔；两件均须用准确HCTL型号，不混用Hirose。实际插接、pin1及接触/支撑资格未通过。
- TH301：时恒 MF52D-103F3435-100 / C394023，R25=10kΩ±1%、B25/85=3435K±1%；完成品−20..105°C、100mm AWG30导线、环氧头最大4mm、静止空气 τ≤7s、δ≥2mW/°C。旧 Semitec 为600mm AWG26线、3±0.5mm头。新R-T表给0°C=27.513kΩ、45°C=4.923kΩ；同R25/B不代表全曲线相同。保持温控保护，J302接线、绝缘、包体间隙、热贴合及低/高温充电阈值按新曲线验证。TH301仅板外手工件，不进入机器CPL。
- J302/J502：HCTL HC-1.0 PWT 原厂第18页，信号焊盘0.7×1.75mm、支撑1.0×2.55mm，行中心相距3.70mm；独立封装已应用。J302 的 NTC 支路过孔和地线已受控调整，温控不旁路。两件按3.2mm保守高度预算，需匹配 HC-1.0-3Y/2Y 壳和端子；旧 JST 线束不沿用。J502 为浮地 BTL 喇叭输出，两端均不得接地；2.5W/4Ω算例为0.791Arms/1.118Apeak，1A连接器额定值仍需核对连续音频温升条件。
- J803/J804：XKB X05A10H06G 原厂 A2（2026-01-15，ECN-P-2026011502）第2页，6针双触点、0.5mm间距、0.3mm FPC、0.5A/50V。信号焊盘0.3×0.8mm、支撑0.4×0.8mm，支撑中心x=±2.3mm，两行相距2.5mm；原厂钢网建议0.25×0.65mm、厚0.1mm须另与装配厂确认，不能将普通焊盘大小当成已批准钢网。原厂pin1在左，PCB整件旋转180°并向−Y移动2.5mm，保持全部原信号焊盘世界坐标与网名；入口改向−Y。H804孔移至(3,33)，保留1.6mm孔径和原3.2mm直径安装包络；SDA绕开J804支撑焊盘。闭合高最大1.1mm、开启锁扣名义1.55mm；FT01C排线折弯、安装柱、锁扣工具空间与实际A2供料版本未冻结，不能据CAD检查宣布插接合格。
- L401：Sunlord MWSA0402S-R47MT / C6331050，0.47uH±20%，DCR14mΩ最大；2025-05-29原厂表的 Isat Max/Typ 为7.6/9.5A，Irms Max/Typ 为6.65/7.5A。保留原表标题，不当作保证下限；饱和与温升判据需确认。原厂焊盘1.5×2.5mm、中心距3.7mm、本体最大4.75×4.45×2.0mm已应用。SGM62125算例（Vin1.9V、Vout3.3V、2A输出、效率80%、2MHz、Lmin0.376uH）得到5.23A峰值及1.2倍6.28A筛选目标；效率/频率是假设，不能代替低温、限流及热最坏角验证。
- L402：本轮明确从 B01 改为 MWSA0402S-1R0MT/C408332。1uH±20%、DCR27mΩ最大、Isat Max/Typ 5.6/7A、Irms Max/Typ 5.4/6A；保留原表标题，不推定保证下限。原厂焊盘与 B01 相同。5.5V、D=0.5、Lmin0.8uH、1.38MHz、3A平均算例为3.623A峰值/3.022Arms；历史13.5V算例含20%峰值筛选为5.435A，13.5V不是允许的USB输入。反向升压在首板 bring-up 中必须保持关闭，固件尚未实现该约束；OCP/饱和/热及既有0.2mm铜图仍未验证。完整算例和限制见 split-c1-candidate-review.json。
- Display L1：Sunlord SWPA3012S470MT，47uH±20%、DCR1.885Ω最大，原厂 Isat Max/Typ 0.27/0.35A、Irms Max/Typ 0.35/0.40A（表头不是保证下限）。原厂焊盘0.8×2.7mm、中心距2.3mm、高度最大1.2mm；较旧料增高0.2mm，已登记机械输入。EPD升压峰值、RESE最坏角、纹波、效率及热测试仍需资格确认；精确C码C83420已确认；实际供料/装配接收未确认。
- Display U1–U3 的 MPN/铜图未更换，本来已是中微爱芯 AIP74LVC2G17GC363.TR；将错误的 TI SN74AUP2G17 数据手册链接改为原厂 B032EN/A5。LVC 的静态/关断泄漏和输入非轨电压额外耗电应按原厂最坏值预算，不能引用 AUP 低功耗规格。

- J201：MUP U20405-01/C20624794，原厂Rev4无定位柱顶装16针。0.4mm间距、0.25×0.80mm独立焊盘、y=-6.55mm行；壳脚铜盘1.2×2.0/2.1mm、槽0.6×1.4/1.5mm。完整重接USB/CC/VBUS/GND，保留16针逻辑；删除中沉槽、旧GCT模型及三条J201历史例外，恢复直板边。两板0.2mm板边标准DFM为零。5A为VBUS触点总额定，0.2mm板上支路仍需3A载流审查；新增数据过孔需USB全速验证。官方安装高3.26mm与图3.20mm不同，暂按3.46mm保守预算，尚无5.95mm整机证明。原厂1200/盘、24mm带宽/12mm步距、192mm头尾；实际供料与装配接收待确认。

- SW201/SW202：XKB TS-1186E-B-B/C2885153，A1（2025-06-06）无定位柱侧按160gf、行程0.20mm、50mA/12VDC。板上高度为侧视图1.50±0.10mm；目录H3.55是顶视图含按钮方向深度，不能当作Z高度。原厂两焊盘0.6×1.6mm、内距4.3mm/外距5.5mm、中心x=±2.45mm，pin1左/pin2右；整件原PCB位置与−90°旋转保持。原四焊盘铜线移除，按键/地线重新接通，C504仅移0.25mm以留Courtyard。无定位柱变体不钻孔。外壳按钮开口、作用力、超行程、寿命和实际供料仍待确认。

- D202：聖邦微 SGM05HU1ALXUGY2G/TR，原廠August2024 Rev.A；5.5V單向保護，pin1陰極接VBUS、pin2陽極接GND。採用原廠0.25×0.50mm焊盤、0.65mm中心距與独立K/A符號，移除TI模型；原走線端點仍在新焊盤內。現有USB2/5V sink/no PD基線保持，不開放9/12V輸入。漏電最大1uA@5V高於舊料100nA；100pF典型/130pF最大僅適用VBUS。12.1V最大鉗位@43A8/20us與SGM41513關閉轉換器時22V绝对最大值不能替代整板ESD、分壓支路與運行中充電器瞬態驗證。資料p5通用bidirectional文字與p1單向圖衝突，按p1明確極性實施。精確C碼C55274065已確認，公開庫存0；供料接收未確認，原C48260已撤销。

以上均为工程候选资格，不是制造或 EVT 放行。受控新引脚、焊盘和 C516 已纳入当前/重建 CAD 检查；原有 DRC 规则与例外未放宽。

## 最后3个进口位号已完成设计替换
| 板／位号 | 国产精确选择 | 已完成 |
|---|---|---|
| Core U302 | WAVE SD3078 / C916255 | 1SCL/2F32K/3VDD/4NC/5VBAT/6GND/7INT/8SDA新符号、208milSOP8工程焊盘及重布线 |
| Core C301 | KAMCAP SE-5R5-D105VYH3C / C2894294 | 1F水平通孔；现行20mm封装明确改型，整体最大高6.5mm，独立SMT后手焊 |
| Display Q1 | JSMSEMI NX3008NBK,215-JSM / C53113911 | 1G/2D/3S、原厂0.8×0.6mm焊盘、源漏网络及局部重布线 |

U302/C301详见C4D8-RTC-DECISION.md与SPLIT-C1-RTC-FIRMWARE.md。原型要求RTC断电有效时间≥24h；总节点≤2µA、实测起点≥3.15V、终点≥2.3V是待验证工程目标。条件估算室温66.11h／−25°C老化角33.06h，不是保证值；RTC最大电流／电容漏电缺少限值。一次性电池不允许装到充电节点。驱动未集成，实板Q04–Q14全部NOT_RUN。

Q1原厂V1.0 p1功能图明确1G/2D/3S，p5提供推荐焊盘；实际样件极性／GDR／RESE／效率／温升在样板后验证。30V，Rds最大0.6Ω@2.5V/200mA、Qg最大0.87nC@4.5V/15V/1A，仅构成原型选型筛选；测试条件不同不能直接用参考MOS的Qg数值证明动态合格。

## 供料仍有6个SMT映射缺口
Core精确C码110/116，Display37/37。U902、U905、U402–U405共6个SMT仍无确认的精确C码／客供接收；逐位号CAD封装和网表已整理为split-c1-smt-consignment.json。不能用相似型号补码、不能不贴，未检索到不代表停产。

SD3078公开4674／Q1公开2306未预留；C301现行H3C/C2894294目录身份已确认，库存数量未核实；D202/C55274065库存观察0。全部物料实际库存、批次／MSL、头尾／损耗及PCBA接收仍待闭环；没有报价、采购、预留、供方消息或订单。assembly_request_ready／assembly_order_ready=false。

裸板Gerber／钻孔可以作为当前两板工程审核资料。DFM、DRC与全国产身份通过不代表整机或PCBA下单条件全部满足。电池完整最大输入54×36×5.5mm、外壳112×75×21mm仍是工程预算；未选完整国产电池包／冻结外壳。

## 复现
python3 hardware/thin18-compact/release_split_c1.py --target split-c1
python3 hardware/thin18-compact/audit_split_c1_domestic.py --require-complete

第二条现在应通过155/155身份审计，但不会批准实际供料或EVT。当前与不可变基线重建的两板DRC/open/parity/ERC必须全0；60针逻辑／插接变换不变；焊盘和负向控制拒绝错误引脚、槽孔或SKU。生产文件绑定源哈希及ZIP CRC；生成ZIP、PDF、PNG、生产CSV和临时脚本不提交git。

本次供料跟进见SPLIT-C1-SUPPLY-REQUEST.md：SGM2578SD授权世强精确库存3940未预留；六个SMT缺码／客供回执仍未关闭。C301不寄JLCPCB客供仓，独立供料后装；官网H3C脚距20mm不能直接代替已设计旧H型19±0.5mm。

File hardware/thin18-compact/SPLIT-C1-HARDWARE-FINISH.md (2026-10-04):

# Split-C1 hardware finish — prototype source

This is the user's selected routed Split-C1, NOT Thin7/portrait-R2. Core remains
96 x 68 mm / four copper layers; Display remains 45 x 36 mm / two layers; both
are 0.8 mm. The ESP32-S3-WROOM-1U-N16R8 and HCTL 60-pin mating pair are unchanged.

## Electrical corrections

The former direct XL9535-to-charger BQ_CE connection is replaced by a default-off
hardware authorization circuit. R607 still pulls the expander request low; its
net is now CHG_REQUEST. R932 adds a 10k pulldown alongside the original100k.

```
SGM41513_REGN -- R930100k -- CHG_nCE -- Q907.D
                                       Q907.S -- Q908.D
CHG_REQUEST --------------------------- Q907.G   Q908.S -- GND
FL_HWEN ---------------------------------------- Q908.G
```

Q907/Q908 are the exact existing JSM NX3008NBK,215-JSM/C53113911: pin1=G,
pin2=D,pin3=S. They switch only the low-current nCE logic node, NOT the battery
or system power path. The pullup uses the charger's REGN supply, available
before downstream AON startup. No5V node is connected to an ESP/XL GPIO.

| Expander P05 request | Direct permit | nCE sink authorized | Frontlight EN |
|---|---|---|---|
| Low or high impedance | Low or high impedance | No | Low |
| Low | High | No | High |
| High | Low | No | Low |
| High | High | Yes | High |

An authorized sink is not by itself charging: charge configuration, battery,
NTC, source and other charger conditions still apply. Likewise EN high does not
permit LED operation until PWM and verified frontlight registers are correct.

GPIO2/module pad38 now drives HW_ARM_GPIO through R9311.2k to FL_HWEN. This
bypasses I2C and the expander. R93310k parallels the existing R601100k pulldown.
XL9535 P15/pad18 is explicitly unused/input; P16 still controls PWM. No octal
PSRAM or strapping pin is repurposed. Pulling native GPIO2 low disables driver
EN and the second charger-authorizing MOS even when I2C is unresponsive.

TP19, B.Cu at(58,17)mm, is copper-only FORCE-LOW test access, excluded from
BOM/CPL. Ground it to inhibit frontlight and charging; do not inject voltage.
R931 limits opposing GPIO current to approximately3.03mA at3.6V with its1%
low-resistance corner. The pad can be used by the bring-up fixture before any
unqualified application firmware is run.

## Parts and placement

Six additional populated parts:Q907,Q908,R930,R931,R932,R933. All use exact
already-reviewed mainland manufacturer/MPN/catalog identities. No new unmapped
SKU is introduced. Expected system population is162 refs (Core125,Display37),
including CoreC301/TH301 manual-or-offboard. Core123SMT;Display37SMT. The17
board-level IC/module refs remain unchanged; the two new devices are discrete
MOSFETs. Seven older SMT positions still require exact supply/assembly acceptance:
U402-U405,U902,U905,U906. A catalog code is not a reservation or supplier receipt.

Only existing U501/U601/U901 pin connections and R601/R607 descriptions change;
existing component positions are untouched. All Display native files and Core
outline, layers and design rules remain unchanged. New copper is restricted to
the reviewed enable/REGN/ground paths; the former dead charger escape is removed.
The exact route delta and new poses are frozen in split-c1-hardware-finish-layout.json.

## Validation and fabrication

Run from repository root:

```
python3 hardware/thin18-compact/release_split_c1.py --target split-c1
```

The command verifies current AND reconstructed native CAD, the independent
pin/variant/land checks,60-pin interconnect, BOM/CPL identities, mechanical XY
screen and both bare-board DFM checks. Use its current generated source-bound
reports, not a hidden routing trial or an old ZIP. The output is
production/Panda-Split-C1-JLC-Prototype.zip, with individual Core/Display Gerber
and separate plated/non-plated drill files, assembly views and BOM/CPL.

## Explicit physical and firmware boundaries

This closes the two identified static hardware defects: autonomous default-low
nCE wiring and an exclusively-I2C frontlight shutdown path. It is not a claim of
physical electrical qualification. Test REGN/nCE during batteryless and battery
startup, GPIO low/high/Hi-Z, partial-power, reset and bus-loss before qualified
battery charging. Datasheet leakage/threshold calculations are screening values
at stated conditions, not universal temperature/ramp guarantees. In particular,
JSM gate leakage is specified up to10uA, which is why the stronger10k pulldowns
were added rather than relying solely on100k. Verify enable HIGH/LOW margins
and physical current at the actual AON/temperature corners.

The direct GPIO is NOT an autonomous watchdog. CPU/GPIO retained-high failure
still needs TP19 grounded or power removed. The prototype includes that manual
shutdown route; it does not silently claim self-detection of arbitrary CPU faults.

Old firmware is incompatible with this board: P05 is now active-high request,
not active-low nCE; P15 must stay input; native GPIO2 defaults LOW. The minimal
host-controller binding was updated to require direct GPIO callbacks and to
keep CHG_REQUEST LOW. No target firmware was flashed or physically qualified.

Physical USB/current/charging/NTC, magnetics/thermal, RTC retention, panel/RF,
battery/enclosure and real supplier/assembly acceptance remain prototype tests.
manufacturing_release=false and assembly_order_ready=false are intentionally
retained. Bare-board CAM review does not require pretending these tests ran.

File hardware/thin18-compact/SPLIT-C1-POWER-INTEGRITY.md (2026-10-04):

# Split-C1 — PG / PSEL functional migration

## Scope and acceptance boundary

ECO `SPLIT-C1-POWER-INTEGRITY-01` continues the **main-branch Split-C1** at
`6906a246b1658386278c13912e77bfe833c1d8ea`. Core remains 96 x 68 mm / 4 layers;
Display remains 45 x 36 mm / 2 layers. Both remain 0.8 mm. The connector pair,
60-pin mapping, board outlines, layer stack and design-rule configuration are
unchanged. Thin7 and portrait-R2 are not the source of this PCB.

The original populated BOM had 155 mainland-manufacturer refs, but that identity
result did not establish a complete electrical migration. This ECO adds one
mainland IC and fixes two circuit-level omissions. The resulting expected BOM
is **156 refs: Core119 / Display37**; there are **17 populated board-level IC
refs: Core14 / Display3**. Native checks and deterministic replay must pass again.
Manufacturing release, actual PCBA acceptance and physical EVT remain false.

## U906 restores a real supply-status source

The prior `PG_3V3_MAIN` connected only XL9535 U601.17 and TP16. The selected
SGM62125 regulator has no PG output. U906 is now **SGM809B-TXN3LG/TR**, monitoring
`3V3_AON`: pin1=GND, pin2=active-low push-pull nRESET/PG_3V3_MAIN, pin3=3V3_AON.
Its original-maker SOT-23 TX00031.001 lands are 0.76 x 0.76 mm, 1.90 mm paired
pitch and 2.29 mm opposing-row pitch. The new body is at (17,18.75), F.Cu.
No existing connector, host module, power IC or RF/USB component moved.

This is **informational power status**, not an MCU hard-reset circuit. The
3.08 V nominal threshold has a 2.966..3.181 V full-temperature range; it cannot
prove a reset before every MCU 3.0 V minimum. Recovery delay is 120..400 ms at
full temperature. Behavior below the supervisor's specified supply range, supply
ramps, noise rejection and board-level timing need physical verification.
Firmware must leave XL9535 P14 configured as an input; driving it creates
contention with the push-pull supervisor. Do not use charger nPG as 3.3 V PG.

Original-maker basis: SGM803B/SGM809B/SGM810B, October2024 Rev.A.2, pp2-4,8,10:
https://www.sg-micro.com/rect/assets/50d03578-1421-4ff6-a32f-020bee34d824/SGM803B_SGM809B_SGM810B.pdf

## PSEL no longer depends on downstream AON startup

U901 is the **non-A/non-D SGM41513YTQF24G/TR**. The original PSEL connection to
3V3_AON did not establish the high input level before batteryless source
detection. The manufacturer power-up sequence starts internal REGN before
source-type detection and then enables the converter.

The exact existing domestic resistors are reused:

```text
SGM41513_REGN -- R204 1.2k / 1% --+-- U901.2 PSEL
                                |
                              R201
                             5.6k / 1%
                                |
                               GND
```

R204 remains FH RS-03K1201FT / C118396; R201 remains FH RS-03K5601FT / C99891.
These are now explicit divider components, not an analog ILIM network. The
machine-readable pin and part contract is `split-c1-power-integrity.json`.
The old BQ_ILIM and BQ_ILIM_RC net names are absent.

Using the conservative 4.45..5.4 V REGN envelope, resistor 1% extremes and a
+/-1 uA leakage sensitivity, PSEL calculates to **3.650693..4.463635 V**, versus
VIH0.9 V and the 6 V absolute limit. Divider load is at most approximately
0.802 mA in this screen. The manufacturer's leakage table is measured at 1.8 V:
using +/-1 uA at the divider's higher voltage is an **assumption**, not an
additional guaranteed specification. Startup ramps, loading and all corners
must be measured; absolute maximum is not a substitute for qualification.

High PSEL selects a **nominal 500 mA reset input-current setting**. This is not
an independent hardware current ceiling: host register writes can override it.
Read back IINDPM after startup, watchdog/reset and source changes. Keep OTG
disabled and do not increase current without a qualified source/pack/copper
policy. USB enumeration, pre-enumeration and suspend compliance remain separate
open gates; a 500 mA setting alone does not prove USB compliance.

Original-maker basis: SGM41513/SGM41513A/SGM41513D, April2025 Rev.C.1, pp3,5,11,20-21:
https://www.sg-micro.com/rect/assets/58a4fe4d-da1d-49a3-b312-5664211d9016/SGM41513_SGM41513A_SGM41513D.pdf

## C204 and routing are controlled changes

C204 retains its exact FH0603B334K500NT/C188679, 330 nF/50 V X7R identity. It is
repurposed as the supervisor bypass, pin1=3V3_AON/pin2=GND, at (16.5,16),180deg.
It is no longer an obsolete charger RC component and is not a PSEL delay.

Only the two old AON-to-PSEL branch tracks and former BQ_ILIM_RC copper are
removed. Existing BQ_ILIM copper is renamed PSEL where reused. Seventeen new
segments and four vias complete the connections; new traces use F.Cu/B.Cu.
The rest of the pre-existing copper, including USB/RF/SD and the Display PCB,
is unchanged. Main-branch existing internal-layer signals are not reinterpreted
as a Thin7 ground-plane contract. `split-c1-power-integrity-adoption.json`
records source hashes and the exact adoption; layout replay is additive and
rejects an unexpected predecessor. No clearance or DRC exclusion is relaxed.

## Verification and next gates

Run from the repository root:

```sh
python3 hardware/thin18-compact/release_split_c1.py --target split-c1
python3 hardware/thin18-compact/verify_split_c1_supply.py --negative-controls
```

The native current and rebuilt boards must both pass DRC/open/parity/ERC
0/0/0/0. Separate semantic checks reject a downstream-AON PSEL connection,
reversed supervisor pins, wrong threshold/output/charger variants, missing
bypass, old ILIM nets or unauthorized PG loads. Twenty-two unit tests exercise
circuit and target-isolation cases; synthetic fixtures are never saved as
supplier receipts or measured EVT results.

**Seven SMT refs / four exact groups now need catalog mapping or accepted
consignment:** U902, U905, U402-U405 and new U906. U906's exact code, received
inventory, lot, packing and assembler acceptance are unknown; no lookalike code
is assigned. Procurement still requires the full system BOM, not only these
seven refs. The supplier receipt verifier also follows D202 and post-SMT C301.

Before a functional prototype is declared complete: verify PG recovery/falling
edges and P14 input-only behavior; test no-battery/empty-battery/normal-battery
cold starts with AON, REGN, PSEL and input-current capture; exercise USB/reset/
watchdog limits; integrate the actual charger/regulator/gauge/RTC/frontlight
firmware contracts. Existing physical, thermal, battery and enclosure gates
remain open. No board-level identity audit certifies the Flash/PSRAM die inside
the ESP module or controllers inside externally supplied screen/touch modules.

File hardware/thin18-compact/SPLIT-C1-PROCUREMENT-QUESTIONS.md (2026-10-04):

> **Current hardware-finish checkpoint (2026-10-04):** use the freshly regenerated
> Split-C1 package, not an older ZIP. Default-off charger authorization and direct
> GPIO2 shutdown are implemented. Population is now **162 mainland system refs**
> (Core125/123SMT + C301/TH301; Display37/37SMT). New Q907/Q908/R930-R933 reuse
> reviewed exact catalog identities; the same7 older SMT supply gaps remain.
> Read [hardware finish](SPLIT-C1-HARDWARE-FINISH.md) for TP19 FORCE-LOW access and
> incompatible old firmware. Earlier156-ref and missing-hardware-gate descriptions
> below are historical; real source-bound generated audits override old counts.

# Split-C1 精确供料待确认清单

> Current Split-C1 power-integrity ECO: the saved main-derived board now adds
> U906 SGM809B-TXN3LG/TR, reuses R201/R204 for REGN-derived PSEL and moves C204
> to supervisor bypass. Expected current BOM: 156 mainland refs (Core119,
> Display37), Core117 SMT + 2 manual/offboard, Display37 SMT. Seven SMT refs
> remain unmapped (U902,U905,U402-U405,U906). Older observations below retain
> their dates; use [the current power contract](SPLIT-C1-POWER-INTEGRITY.md),
> regenerated audits and the handoff for the current source. No actual stock,
> assembly acceptance or physical EVT result is asserted.

2026-10-02。一套=Core-C1+Display-C1两板，批量N未给定。此文件未发送给供方；没有回执、采购、预留或装配接收。

| 位号 | 数量/套 | 精确身份 | 仍缺什么 |
|---|---:|---|---|
| Core U902 | 1 | SGMICRO SGM62125AXG/TR，A版WLCSP-15 | 精确C码／客供接收、库存、批次／MSL和料带头尾；不得用非A版或别的封装 |
| Core U905 | 1 | SGMICRO SGM37601YTRL20G/TR，TQFN-20 | 精确20脚C码／客供接收、交期和包装；24脚型号不能代用 |
| Core U402–U405 | 4 | SGMICRO SGM2578SDYG/TR，WLCSP0.9×0.9 | 世强精确SD商品页显示3940颗、约3–4工作日、未预留；精确C码／嘉立创接收仍缺。请确认RevA.2 p9的ON高／低RCB与首页disabled概述冲突；AAD/C5151451仅关闭态RCB不能代用 |
| Core U302 | 1 | WAVE SD3078 / C916255 | 精确SOP8宽208mil版本，Rev4.4／批次、MSL3、料带及实际可用量；公开4674未预留 |
| Core C301 | 1 | KAMCAP SE-5R5-D105VYH3C / C2894294 | 精确现行20mm水平封装CAD已实施，盒装目录身份确认；当前库存数量无法核实，实际批次／数量及独立后装接收待确认，不寄SMT仓；需漏电上限／RTC低压容量、负极标记及0.8mm板手焊工艺 |
| Display Q1 | 1 | JSMSEMI NX3008NBK,215-JSM / C53113911 | 公开2306未预留；确认实际批次与1G/2D/3S，按已修改符号／焊盘装配；首板验证样件极性、GDR/RESE及温升 |
| Core D202 | 1 | SGMICRO SGM05HU1ALXUGY2G/TR / C55274065 | 精确身份已确认但公开库存0；可用库存／交期、7inch/8mm tape/2mm pitch及手料头尾；1阴极VBUS、2阳极GND |
| Core L402 | 1 | Sunlord MWSA0402S-1R0MT / C408332 | 显式MT改型，非B01别名；公开19754未预留，3000/reel，实际批次／损耗和装配接收 |
| Core J501 | 1 | XUNPU TF-122-CCP9 / C41347844 | 公开36未预留，1000/reel；RevA/实际批次及CD、定位柱；卡口／行程尺寸3D图 |

本次8个位号的精确渠道、MSL／料带和未发送申请资料见SPLIT-C1-SUPPLY-REQUEST.md及split-c1-supply-plan.json。六个无C码SMT位号的逐位号封装和引脚网络见split-c1-smt-consignment.json。N套需求U902=N、U905=N、SGM2578SD=4N，损耗／头尾另计。先让装配厂接收精确MPN/封装并分配C码，随后创建Parts Manager记录；不得给空白／未接受料号发货。收货后核对My Parts可用量并绑定准确6个位号。不能用目录相似名称补码，也不能默默不贴。

所有其他精确映射见split-c1-sourcing-evidence.json。目录身份验证与实际库存／订单接收分别记录；没有查询到不代表停产。全国产身份审计通过仍不代表SMT供料已齐。

RTC24h以完整节点≤2µA、预充实测≥3.15V、末端≥2.3V为原型预算目标；厂家RTC最大电流及电容漏电上限缺失。请求常温／批准冷／热／老化参数，不能把0.8µA典型值作为最坏值保证。JLCPCB公开客供条款排除超级电容；C301采用独立采购、PCBA回板后客户／独立后装工位手焊、实际正端装到PCB+、引脚剪到Core背面≤0.5mm；1F电容不经过回流。18H=82H启用本节点充电，禁止一次性电池。

主电池完整最大输入54×36×5.5mm、名义1100mAh／最小900mAh；电芯、PCM器件、HCTL HC-HY-2Y／HC-HY-T、AWG26线束均需精确大陆厂家身份和完整极性／最大图。连续1.5A／峰值3A三秒是采购筛选目标，既有0.2mm铜支路未完成该电流等级资格。独立时恒TH301不与未知包内NTC并联。

外壳112×75×21mm为两板空间预算，所需厚度20.5mm，不是冻结尺寸。主电池区Core[1,11,37,65]，Display投影[38,30,83,66]；H804不能穿入电池。C301最大直径19.2／整体高6.5mm需实体、引脚、FPC／工具、接口／喇叭／天线／支撑建模；见SPLIT-C1-PACK-INPUTS.md。

卡口TF-122-CCP9入口朝Core+X，原厂压入／锁定／弹出1.30／2.30／5.00mm，各±0.30mm；壳体须有凹入访问／取卡路径。全部实板EVT仍NOT_RUN。当前6个SMT映射、零库存供料、实际PCBA接收与壳体／整包冻结仍未完成。

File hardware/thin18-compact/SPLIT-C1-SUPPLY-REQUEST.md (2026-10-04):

> **Current hardware-finish checkpoint (2026-10-04):** use the freshly regenerated
> Split-C1 package, not an older ZIP. Default-off charger authorization and direct
> GPIO2 shutdown are implemented. Population is now **162 mainland system refs**
> (Core125/123SMT + C301/TH301; Display37/37SMT). New Q907/Q908/R930-R933 reuse
> reviewed exact catalog identities; the same7 older SMT supply gaps remain.
> Read [hardware finish](SPLIT-C1-HARDWARE-FINISH.md) for TP19 FORCE-LOW access and
> incompatible old firmware. Earlier156-ref and missing-hardware-gate descriptions
> below are historical; real source-bound generated audits override old counts.

# Split-C1 精确采购／客供申请资料

> Current Split-C1 power-integrity ECO: the saved main-derived board now adds
> U906 SGM809B-TXN3LG/TR, reuses R201/R204 for REGN-derived PSEL and moves C204
> to supervisor bypass. Expected current BOM: 156 mainland refs (Core119,
> Display37), Core117 SMT + 2 manual/offboard, Display37 SMT. Seven SMT refs
> remain unmapped (U902,U905,U402-U405,U906). Older observations below retain
> their dates; use [the current power contract](SPLIT-C1-POWER-INTEGRITY.md),
> regenerated audits and the handoff for the current source. No actual stock,
> assembly acceptance or physical EVT result is asserted.

2026-10-02。未发送、未申请、未采购、未预留、未发货。单套包括Core-C1+Display-C1；本次缺口在Core，批量N仍未指定。此文件可用于人工审核后填入供方／嘉立创表单；公开渠道不是接收回执。

| 位号 | 精确订货型号 | C码 | 数量／套 | 当前可核实渠道 |
|---|---|---|---:|---|
| U902 | SGMICRO SGM62125AXG/TR | 待分配 | 1 | 圣邦官网列Active和授权代理；公开JLC stock/buy查询均无精确结果，交期／实际供料待报价 |
| U905 | SGMICRO SGM37601YTRL20G/TR | 待分配 | 1 | 圣邦官网20脚型号Active；公开JLC stock/buy查询均无精确结果，交期／实际供料待报价 |
| U402–U405 | SGMICRO SGM2578SDYG/TR | 待分配 | 4 | [世强精确商品](https://www.sekorm.com/product/578179499.html)显示世强仓3940颗、品牌仓0、约3–4工作日；支持1颗起订，未预留 |
| D202 | SGMICRO SGM05HU1ALXUGY2G/TR | C55274065 | 1 | JLC精确buy目录库存0；预订／圣邦授权渠道交期和实际入库待确认 |
| C301 | KAMCAP SE-5R5-D105VYH3C | C2894294 | 1 | [现行精确目录](https://item.szlcsc.com/3128601.html)及原厂20mm图纸已核对并实施CAD改型；库存数量未能核实，独立供料／PCBA后装 |

授权代理身份以[圣邦官方名单](https://www.sg-micro.com/authorized-distributors)为依据。世强商品页当日快照已核对精确SD型号、0.9×0.9-4B-D和3000／卷；搜索摘要的4000不是当前商品页3940。公开查询和网页哈希记录在split-c1-jlc-catalog-observation.json、split-c1-supply-plan.json；未能查到不表示停产或整条渠道无货。世强公开搜索接口的正对照也没有结果，未把该接口的空结果用于库存结论。

| 位号 | 原厂包装／MSL | 料带宽W／穴距P1 | pin1料带象限 | 嘉立创仍需确认 |
|---|---|---|---|---|
| U902 | 3000／7英寸卷，MSL1 | 8／4mm | Q1 | WLCSP15／0.4mm pitch、实际切带／头尾、损耗、批次 |
| U905 | 4000／13英寸卷，MSL2 | 12／8mm | Q2 | TQFN3.5×3.5-20L+EP、实际封装、密封／干燥／开封期限和切带 |
| U402–U405 | 3000／7英寸卷，MSL1 | 8／4mm | Q1 | WLCSP0.9×0.9-4B-D／0.5mm pitch、0.22mm圆焊盘、切带／头尾／损耗 |
| D202 | 10000／7英寸卷，MSL1 | 8／2mm | Q1 | UTDFN1×0.6-2BL、精确料源池、实际入库量及极性 |

以上是原厂完整卷规格；原厂整卷数量不是打样采购MOQ，料带Q1／Q2不是PCB旋转角。逐位号封装及网络见split-c1-smt-consignment.json。U902 EN与ADDR接VSYS_RAW，启动3.4V／地址0x76，固件再设3.3V；不能照ADDR低的3.0V启动写法。U905只接LED1／LED2；不能拿24脚YTWY24G/TR补货。D202 pad1阴极VBUS、pad2阳极GND。

## IC客供接收资料
1. 先提交三个缺码的精确MPN／厂家／封装、原厂手册及CAD封装；要求嘉立创返回精确C码、工程接收编号、工艺／载板条件。未批准前不寄料；回执新C码必须同步原理图、PCB、BOM和采购登记，重新生成并校验。
2. D202可请求C55274065精确预订交期，或对同码明确接受授权渠道客供。不得把公开库存与客供／Global Sourcing库存相加；同料号使用接收规则允许的库存池。
3. 向供方确认带标记的精确料号、封装、批次／日期、原厂包装、MSL密封／开封状态、MOQ／小批量切带、交期。向装配厂确认每组N／N／4N／N的贴装需求以及独立损耗、最低上机量、料带头尾；不自行填固定损耗数。
4. U402–U405另请圣邦确认RevA.2 p9 ON高／低RCB与首页disabled概述的差异，保存明确型号与条件的文字回执。库存渠道不能关闭该工程疑点；AAD/C5151451不代用。
5. 到货后以实际仓库／My Parts可用数量、接收编号及lot为依据，按精确BOM绑定。订单截图／公开库存／报价不能充当实际入库或全单接收。

| 两板套数示例 | U902 | U905 | U402–U405合计 | D202 | 独立后装C301 |
|---:|---:|---:|---:|---:|---:|
| 1 | 1 | 1 | 4 | 1 | 1 |
| 5 | 5 | 5 | 20 | 5 | 5 |
| 10 | 10 | 10 | 40 | 10 | 10 |

此表仅贴装数示例，批量未选定；不含工厂损耗／最低上机量、头尾或后装备件。收货模板在split-c1-supply-plan.json的receipt_template；所有真实回执字段保持空。

## C301独立供料与后装
[JLCPCB2026-09-09客供条款第4项](https://jlcpcb.com/help/article/consignment-part-terms-conditions)排除超级电容。国内服务是否有例外未核实，默认不寄入SMT客供仓；交回SMT完成的PCBA后，由客户／独立后装工位焊接。C301仍在完整系统BOM中，未被删去，不进入SMT BOM/CPL。

当前已明确改为SE-5R5-D105VYH3C/C2894294，并按[2020年6月原厂p4尺寸图](https://atta.szlcsc.com/upload/public/pdf/source/20210914/37A5D1176C23A52D8BA2A343DB47BCB6.pdf)重建20mm封装。1F0/+30%、5.5V、20±0.5mm脚距、扁脚最大宽1.1／厚0.25mm、本体最大直径19.2／整体高6.5mm；负极标记对应PCB pad2 GND。旧H/C118887及VYV3C垂直型不可代用。采购仍需核对现行批次、尺寸一致性和实际数量，不能把目录C码当成有货或嘉立创接收。

独立接收须记录实物精确H3C标签／批次、可用数量、尺寸和负端标记；漏电上限、3.15→2.3V容量和寿命仍须原厂确认／首板测量。p7手焊260°C≤5秒以1.6mm板为依据，Core0.8mm的温度／时间／支撑需工艺验证，不回流；本体离板暂留0.2mm，负端pad2 GND、正端pad1+。后脚剪到Core背面下≤0.5mm并检查1.5mm板间隙。焊后≥24h RTC保持由Q14实测，当前NOT_RUN。

## 供料核对命令
在仓库根目录运行python3 hardware/thin18-compact/verify_split_c1_supply.py --sets 5，5只表示示例批量。加--require-requested-supply会在实际回执／精确C码缺失时退出1；不加则报告等待项，允许继续裸板原型打样准备。该核对只覆盖本次8个位号，不能代替其余供料、完整PCBA订单接收或实板EVT。

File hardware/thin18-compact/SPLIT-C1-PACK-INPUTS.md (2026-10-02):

# Thin7 active pack requirement (2026-10-02)

Current complete-pack maximum requirement is 62 x 51 x 3.1 mm, plus 0.5 mm swelling
space, 1100 mAh nominal target / 900 mAh minimum target. These are unqualified
design inputs; no exact pack is selected. See thin7/THIN7-REDESIGN.md.
The 5.5 mm pack / 21 mm case study below is historical and superseded.

# Split-C1 电池包与外壳采购输入（未发给供应商）

当前阶段只有两板 PCB 设计，没有实板；这是规格输入，不是已选定或获准采购的电池包。

| 项目 | 原型设计输入 |
| --- | --- |
| 电池包完整最大尺寸 | L54 × W36 × T5.5 mm，包含 PCM、包边、极耳和出线 |
| Core 坐标放置区 | x=1..37，y=11..65 mm；与 Display 投影 x=38..83 相隔 1 mm |
| 主电池容量 | 1100 mAh 名义目标，900 mAh 最小目标；续航需测，24h 要求仅指 RTC |
| 化学体系 | 1S 锂聚合物，3.7 V 名义 / 4.2 V 充电，带保护 |
| 保护后输出目标 | 连续 ≥1.5 A；峰值 ≥3 A / 3 s，须按批准温度与电压条件确认 |
| 原型充电上限 | 暂定 0.45 A；0..20°C 暂定 0.27 A；0..45°C 外禁止充电，最终以包厂和 TH301 曲线为准 |
| 电源线束 | 国产 HCTL HC-HY-2Y / HC-HY-T 配 J301 HC-HY-2AWT；AWG26，100..120 mm 初步路由 |
| 极性与 NTC | J301 pin1 BAT+ / pin2 GND；外置 TH301 接 J302，不并联未知包内 NTC |
| 国产身份 | 电芯、PCM 已装配器件、壳、端子均须精确厂家 / MPN；未选定 PCM 或整包 MPN |
| 外壳空间预算 | 112 × 75 × 21 mm；当前Z预算所需20.5mm，Core96×68×0.8／Display45×36×0.8，1.5mm板间隙 |

Z预算：Core B=0；电池顶面=-1.8mm，5.5mm整包及0.7mm膨胀预算使底面=-8.0mm，后壁0.8mm至-8.8mm。前侧Core0.8+C301原厂整体最大6.5+装配0.2+屏间隙0.5+屏厚2.2+前壁0.8=11.0mm，制造预算0.7mm，总厚20.5mm，空间框取21mm。现行C301 H3C最大直径19.2mm，20mm脚距，Core F后装手焊，背面脚≤0.5mm需实物检验；不得穿入Display或支撑。这是工程空间预算，尚非整机或可制造外壳。

这些数值是工程预算，尚非供应商最大尺寸签核。电池区下移至 y11..65，避开背面 J503 原生本体包络（y4.975..9.025）；实际插接天线线缆仍需建模。H804 位于电池 XY 内，不能放未经审查的穿入电池包安装柱；背面器件/紧固件必须在 1.5 mm 预算内。屏幕 FPC、锁扣工具、USB 和卡槽通道、天线、喇叭、支撑及热条件仍需完整 CAD 验证。现有 0.2 mm 电源支路及过孔不能因连接器额定 3 A 就宣称整条路径通过 3 A。

EEMB [LP503450-PCM-NTC-LD/ 原厂编制规格](https://macrogroup.ru/upload/iblock/80a/i2bksi77p3ephpa70n95kv0izxtrs2jg/LP503450.pdf)（2017-11-13）给出整包最大 52×34.5×5.3 mm，可用于尺寸筛选；但其 PCM 仅 1 A 连续 / 2 A 三秒，使用进口 JST-ADHR-03V-H 和 45±5 mm 导线，NTC 曲线及 PCM 器件身份不明，未选用。需更新供应商完整图纸及精确国产包身份，不能直接采购这个旧版本。

[OpenSCAD 空间模型](SPLIT-C1-ENCLOSURE-STUDY.scad)显示两 PCB、侧置电池、膨胀区、屏厚预算和外壳空间框；没有真实壳体开孔或已验证实体模型。参考 XTEINK X4 Pro 的 5.95 mm 厚度不适用于当前堆叠，未声称达到。当前 EVT 仍为 NOT_RUN。

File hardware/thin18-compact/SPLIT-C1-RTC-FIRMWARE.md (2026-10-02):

# SD3078 原型固件接口契约
2026-10-02。此文件是原理图迁移契约；本仓库没有产品固件工程，驱动集成／运行测试尚未执行。依据SD3078 Rev4.4；禁止继续使用RV3028寄存器或清零时间作为普通启动行为。

| 项目 | 要求 |
|---|---|
| 总线 | 7位0x32，3.3V时100kHz；共享总线不得以400kHz访问RTC |
| 时间 | 00H..06H BCD；写入全部7字节，不能独立改某一字节；小时bit7=1选24小时，读取屏蔽模式位 |
| 写保护 | 先读改写10H bit7 WRTC1=1，再0FH bit7/bit2 WRTC3/WRTC2=1；操作后先清0FH bit7/bit2，再清10H bit7 |
| 备援充电 | 每次主电上电，解锁后写18H=82H并读回；ENCH=1，Charge[1:0]=10选2kΩ。仅本版1F可充电电容；不允许原电池 |
| 备援耗电 | 保持BATIIC=0，FOBAT=0；禁止无需求的备援I²C、32k输出和频率／倒计时中断；F32K无连接 |
| 中断 | INT接共享EXP_INT，保持开漏；读出并处理各芯片的中断源，不能按单器件专用推挽线使用 |
| 初始状态 | 清标志前保存RTCF/OSF/BLF及时间快照，BCD/日期及时间有效性都检查；时间无效明确通知上层 |
| 警报 | 07H..0DH报警数据、0EH匹配允许，10H中断源选择；保留保护位并按原厂清中断语义操作 |
| 电源恢复 | 不因普通主电复位覆盖RTC时间；首次／停振才校时。重新设置充电并读回，失败记录错误 |
| 冷热／断电 | 不在VBAT模式读总线当作验证；恢复主电后读时间／标志并与独立时基比较 |

所有寄存器写入均需读回关键设置。状态位有特定清除语义，不能用随意的整字节常数覆盖0FH；用原厂掩码及本地驱动测试证明不会丢失状态／锁死写权限。共享INT如何唤醒整机需要结合断开主电后的电源架构验证；本版FOBAT=0仅保障走时，不承诺断电后RTC报警唤醒主系统。

首板Q14：受控预充并实测VBAT≥3.15V；移除USB／主电池／调试供电，排除SCL/SDA/INT反灌；记录温度、源状态、备援节点总电流≤2µA目标、时长≥24h和末端≥2.3V；恢复后有效时间连续、无新停振／电量告警。仪表负载与电压取样漏电纳入预算。批准常温／冷／热／寿命条件分别记录，不能用常温结果代替全部条件。全部结果目前NOT_RUN。

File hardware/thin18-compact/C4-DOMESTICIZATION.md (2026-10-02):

# Thin18 Compact — C4 comprehensive domesticization

Date: 2026-09-29 (historical C4 study)

Current authority: [SPLIT-C1-DOMESTICIZATION.md](SPLIT-C1-DOMESTICIZATION.md). The new requirement permits no retained foreign-component exception; 8 refs remain blocked. This C4 study does not override current Split-C1 CAD or its audited BOM.

Goal: replace every realistically replaceable foreign-origin component with a mainland-China manufacturer part, while reducing chip count where a domestic architecture is safer/cheaper than one-for-one substitution.

## Rules

1. Mainland manufacturer only counts as domestic. A foreign brand merely stocked by LCSC does not.
2. Safety-critical charger, battery path, USB, ESD and connectors never become production-approved from price/name similarity.
3. "SELECTED" means documentary electrical + package compatibility is sufficient to enter the engineering CAD candidate. Physical EVT remains separate.
4. Major subsystem replacements are redesigns, not "compatible substitutes".
5. routing142 remains reference-only. Compact C4 is allowed to change schematic, firmware and placement before final routing.

## C4 target architecture

### Keep domestic incumbents

- ESP32-S3-WROOM-1U-N16R8 — Espressif
- GDEQ0426T82-FT01C — Good Display
- FT6336U — FocalTech
- U206 74LVC1G17XC5G/TR — SGMICRO

### C4-PWR

Selected documentary baseline for schematic redesign:

- SGMICRO `SGM41513YTQF24G/TR` / LCSC C5153778
  - 1S synchronous switching charger;
  - NVDC system power path;
  - I2C address 0x1A;
  - exact non-D variant uses VAC/PSEL/nPG and does **not** expose D+/D-;
  - PSEL high provides a conservative 500mA default input-current policy;
  - TS/NTC + JEITA charging behavior;
  - battery-side typical current about 8.5 µA with BATFET enabled;
  - ship leakage about 2.5 µA.
- Cellwise `CW2215BAAC` / JLC C7502681
  - current-sensing fuel gauge;
  - approximately 5 µA active / 0.5 µA shutdown;
  - I2C, NTC and bidirectional current reporting.
- SGMICRO `SGM62125AXG/TR`
  - 4-switch buck-boost;
  - approximately 2.25 µA quiescent current;
  - I2C-programmable output;
  - ADDR=high starts at 3.4 V; compact firmware will lower the AON rail to 3.3 V after startup.

This combination targets removal of:

- BQ25628E;
- BQ27427;
- TPS63802.

Typical core power-management current comparison, before board-level leakage:

- incumbent trio: about 21.5 µA;
- C4 selected trio: about 15.75 µA.

The orderable generic AXP2101/C3036461 is no longer the C4 baseline because its publicly listed charger is linear (100 mA–1 A). It remains a research alternative only; compact thermal loss at high charge current is not acceptable to assume away.

The previously considered SGM62118 remains electrically valid, but SGM62125 is preferred because its typical quiescent current is much lower.

**Historical load-switch assessment superseded:** the disabled-state-only rejection
below the old C4 contract is no longer the current candidate. Split-C1 now uses
SGM2578SDYG/TR with the January 2026 Rev.A.2 datasheet p9 specifying RCB for ON
high/low, a 0.5mm-pitch footprint and local U403 output C516. The datasheet's
front-page wording still conflicts with p9; exact-version manufacturer confirmation,
reverse-current EVT, leakage/timing and supply acceptance remain mandatory.
This engineering change does not establish full-time RCB physical qualification.

### C4-USB

For the product baseline "USB2 device + 5V sink/charge only":

- remove TUSB320 attach/current-policy dependency;
- CC1 = 5.1k Rd to GND;
- CC2 = 5.1k Rd to GND;
- native ESP32-S3 USB D+/D-;
- domestic low-capacitance ESD;
- conservative charger input-current policy.

Target removal after compliance review:

- TUSB320LI
- TPS70933
- SN74AUP2G07 used only for CC-state translation
- TPS3700 VBUS-status chain where PMIC VBUS/IRQ can replace it

No PD/PPS negotiation is part of this baseline.

### C4-GPIO

**Selected engineering substitution:**

- TCA9535PWR → XINLUDA XL9535 / C561273

TSSOP-24 pin assignment is identical to the incumbent TCA9535 PW package. Register/default/interrupt semantics remain subject to firmware regression, but the substitution is eligible for same-net CAD application.

### C4-IMU

- LSM6DSO32XTR → QST QMI8658A / C3021082
- mainland 6-axis IMU, LGA-14, 1.71–3.6V, I2C/I3C/SPI
- requires footprint/pin remap and firmware driver port
- ±16g ceiling means any actual dependency on ±32g must be removed or the substitution rejected

### C4-RTC

Current domestic redesign candidate:

- RV-3028-C7 → GATEMODE BM8563EMA + domestic 32.768kHz crystal

Tradeoff accepted for study:
- much lower BOM/supply complexity;
- not an accuracy/current equivalent;
- firmware + crystal + backup-current qualification required.

SD3900 Rev2.4 is now documented as an integrated-crystal/backup-pin mainland redesign candidate, with higher backup current and different pin/register map. No equivalent is qualified; see C4D8-RTC-DECISION.md.

### C4-AUDIO

Preferred low-cost architecture:

- MAX98357A → Nsiway NS4168 / C910588
- direct I2S mono Class-D, 3–5.5V
- package changes TQFN16 → ESOP8

For a future microphone/voice SKU:
- Everest ES8311 / C962342 codec
- Nsiway NS4150B / C189961 analog Class-D PA

The voice architecture is not required for the base reader.

### C4-FRONTLIGHT

C4D-10B replaces the foreign LM36922H reference with a mainland engineering candidate:

- SGMICRO `SGM37601YTRL20G/TR`;
- TQFN-3.5×3.5-20L, official land pattern transcribed into the project library;
- I2C address `0x36` with A0 low;
- LED1/LED2 drive the FT01C warm/cool strings;
- U601 P15/P16 provide hardware enable and PWM;
- J804 uses the exact FH34SRJ-6S-0.5SH(50) / C224194 land pattern.

The reset defaults are unsafe for this panel if light is enabled immediately: SGM37601 resets to 20 mA and 36 V OVP, while the panel limit is 15 mA/string. C4D-10B therefore keeps `FL_HWEN` and `FL_PWM` low until firmware writes:

- `REG0x01 = 0x56` — 14.5 mA nominal;
- `REG0x02 = 0xA1` — internal compensation, 18 V OVP, 2.7 V UVLO;
- `REG0x03 = 0x2B` — PFM enabled, 1 MHz switching.

Selected support parts:

- Sunlord `SWPA252012S100MT` / C37428, 10 µH;
- CJ `B5819W SL` / C8598, 40 V / 1 A Schottky;
- Fenghua input/VIN/VDC/output capacitors and boot pull-downs.

The first-order low-input/high-output estimate gives about 0.301 A peak inductor current, with approximately 2.92× saturation and 2.06× rated-current margin.

Fresh C4D-10B native checks: ERC 0, DRC 0, schematic parity 0; 436 unconnected items remain because final compact routing has not started.

Production RFQ/stock confirmation, current accuracy, open-string behavior, DC-bias capacitance, thermal, EMI, acoustic noise, shutdown leakage and FPC mechanical qualification remain open. This is not manufacturing release.

### C4-LOGIC / EPD

Candidates:
- AIP74LVC2G17 / Wuxi I-core or lingxingic LVC2G17 for EPD Schmitt buffers after Ioff/threshold review
- mainland 2G07 candidate after open-drain + partial-power proof
- UMW AO3400A only if EPD switch-node VDS/overshoot permits 30V; otherwise choose higher-VDS mainland MOSFET
- Yangjie/CJ Schottky family
- Sunlord 47uH power inductor
- Fenghua 50V MLCC

### C4-MECHANICAL COMPONENTS

Do **not** force a domestic connector purely to reach a percentage target.

Still blocked on exact geometry evidence:
- J802 24-pin EPD FPC
- J803/J804 6-pin touch/front-light FPC
- USB-C mid-mount receptacle
- microSD socket
- DF58 battery connector
- JST SH connectors
- side switches

These remain foreign until an exact mainland drawing/mating/height/footprint-qualified replacement is found.

## Expected result

C4 aims to make the **active silicon and general passives overwhelmingly mainland-origin**. The remaining foreign content should be concentrated in mechanically constrained connectors/switches only where forcing a substitute would create higher reliability or tooling cost.

Physical qualification remains mandatory before manufacturing release.

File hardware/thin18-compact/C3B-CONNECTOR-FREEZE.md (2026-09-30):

> **Superseded front-light driver note:** the LM36922H content below is retained as C3 historical reference. C4D-10B now implements SGMICRO SGM37601YTRL20G/TR with the exact J804/support network.

# Thin18 Compact — C3B connector freeze

Date: 2026-09-29

Status: exact connector **candidate** freeze; not manufacturing release.

## Official FT01C tail functions

The latest Good Display GDEQ0426T82-FT01C drawing/specification is the authority for panel-side function order.

### Touch FPC

Panel-side six-pin order:

1. GND
2. VDD3.3V
3. RST
4. INT
5. SDA
6. SCL

Board net mapping:

1. GND
2. 3V3_TOUCH
3. TOUCH_RST
4. TOUCH_INT
5. I2C_SDA
6. I2C_SCL

### Front-light FPC

Panel-side six-pin order:

1. LED W-
2. LED W+
3. NC
4. NC
5. LED C-
6. LED C+

This remains the authoritative electrical ordering even where third-party boards number their connector pads differently due to flex orientation.

## J803 / J804 exact connector candidate

Candidate for both six-pin tails:

- Hirose `FH34SRJ-6S-0.5SH(50)`
- 6 positions
- 0.5 mm pitch
- back-flip ZIF
- top **and** bottom contacts
- supports 0.30 mm flex in the independent mechanical reference

A dual-contact connector reduces the risk of choosing the wrong contact-side variant while the exact flex-fold orientation is still being frozen.

This is not yet a production-approved connector. Before C3B schematic/PCB integration it still needs a direct manufacturer-land-pattern check and an overlay against the Good Display drawing.

## Driver electrical reference

C3 retains `LM36922HYFFR / LCSC C213572` as the dual-string I2C front-light electrical reference.

Required reference application parts from TI:

- L1: 10 µH class;
- CIN: >=2.2 µF effective;
- COUT: >=1 µF effective at the boost voltage;
- external Schottky between SW and VOUT;
- ASEL=GND -> I2C 0x36;
- PWM may be held at a defined static level when brightness is controlled exclusively over I2C;
- HWEN is controlled by `U601.P15 = FL_HWEN` so true hardware shutdown remains available.

Exact inductor/Schottky/capacitor MPNs remain a C3B sourcing task.

## Touch control policy

`U601.P15` is consumed by front-light HWEN.

For the baseline compact EVT:
- FT6336U reset is produced by controlled `3V3_TOUCH` sequencing plus a dedicated reset-conditioning network;
- touch events may be polled on I2C while awake;
- `TOUCH_INT` is carried to the connector and test access but is not a deep-sleep wake source.

If polling fails the power/latency target, add a small I2C GPIO expander in C3B rather than reusing ESP32-S3 N16R8 GPIO35/36/37, which are reserved by Octal PSRAM.

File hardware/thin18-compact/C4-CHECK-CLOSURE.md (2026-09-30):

# Thin18 Compact — C4 check closure

Date: 2026-09-29

## Scope closed

The following checks have been completed for the current compact domesticization study:

- all 203 native schematic references have an explicit domesticization disposition;
- all 97 unique passive groups / 137 passive references have been screened;
- exact mainland procurement metadata has been applied to 20 capacitor references;
- U601 has been changed in CAD from TCA9535PWR to XINLUDA XL9535 / C561273;
- mechanical/interconnect mainland drop-in screening is complete for USB-C, microSD, battery/JST/FPC connectors, side switches and external NTC;
- firmware dependency audit is complete for QMI8658, power/charger/gauge, USB-C simplification, audio, RTC and XL9535;
- C4 power architecture documentary review is complete;
- native KiCad DRC / schematic parity / ERC checks were rerun on the active C4C candidate;
- fail-closed negative controls were executed, not merely listed.

## Active CAD candidate

`c4c-96x68-domestic-passives`

Fresh native results:

- DRC violations: 0
- schematic parity: 0
- ERC violations: 0
- unconnected items: 447 — expected because compact routing has intentionally not started
- native references: 203
- pin/net tuples: 601

Topology is identical to C4A; the C4C delta is procurement metadata for selected same-footprint passives.

## Applied mainland selections

Already applied in CAD:

- U601: XINLUDA XL9535 / C561273
- 11 × 100 nF 0402: Fenghua 0402B104K250NT / C56392
- 9 × 1 µF 0603: Fenghua 0603B105K250NT / C59302
- existing domestic parts such as ESP32-S3-WROOM-1U-N16R8 and SGMICRO U206 remain retained

## Selected for C4 schematic redesign

Power baseline:

- charger / NVDC: SGMICRO SGM41513YTQF24G/TR / C5153778
- fuel gauge: Cellwise CW2215BAAC / JLC C7502681
- 3V3 AON buck-boost: SGMICRO SGM62125AXG/TR
- USB-C: passive 5.1 kΩ Rd sink, native ESP32-S3 USB, charger/PMIC VBUS status

Typical current of those three active power ICs is approximately 15.75 µA before board leakage, versus approximately 21.5 µA for the incumbent BQ25628 + BQ27427 + TPS63802 trio.

Other redesign candidates:

- QST QMI8658A / C3021082
- Nsiway NS4168 / C910588
- GATEMODE BM8563EMA / C269878
- mainland low-cap ESD candidate after exact clamp/capacitance/pin proof

## Explicitly rejected / blocked

- AXP2101 as the baseline charger: currently orderable generic part uses a linear charger; thermal loss at high compact-device charge current is not accepted.
- SGM2578S/SD as direct TPS22916 replacement: published reverse-current protection does not prove enabled-state full-time RCB.
- AIP74LVC2G17 direct value-only ECO: attempted CAD change caused parity/ERC failures; a correct domestic symbol must be created before reconsideration.
- forced mainland mechanical connector substitutions: no exact drop-in evidence was found.
- precision/pulse/current/DC-bias passives without exact evidence: remain blocked, not downgraded.

## Negative controls

Executed and passed:

1. selected schematic MPN mutation rejected;
2. missing reference status rejected;
3. physical PASS without raw measurements rejected;
4. unsafe load-switch selection rejected;
5. manufacturing release gate rejected.

## What is not complete

This document closes the **documentary and current-CAD checking phase**, not product release.

Still required:

- implement the C4 power/USB/IMU/audio redesign in schematic and PCB;
- C4D-10A/J803 touch and C4D-10B/J804 + SGM37601 front-light CAD are now integrated; physical FPC/current/thermal/EMI qualification remains required;
- reroute the 96 × 68 mm board to open = 0;
- generate final production BOM/CPL/Gerbers;
- build real EVT units;
- run charging/NTC/ship/deep-sleep/USB-C/RF/EMI/thermal/audio/display/touch/mechanical qualification.

Physical tests completed: **0**.

Manufacturing release: **false**.

## Post-closure implementation progress

After the original documentary closure, C4D-10A integrated the exact touch FPC and C4D-10B integrated the mainland SGM37601 dual-string front-light circuit. C4D-10B passes ERC/DRC/parity at 0/0/0 and includes a fail-closed firmware startup contract. The board is still intentionally unrouted and physical tests remain zero.

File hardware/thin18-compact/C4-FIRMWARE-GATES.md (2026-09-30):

# Thin18 Compact — C4 firmware migration gates

Date: 2026-09-29

This audit checks whether the proposed mainland hardware substitutions are blocked by existing Panda OS dependencies.

## QMI8658A

Repository findings:

- Panda OS already contains QMI8658 probe candidates qmi8658LowCandidate() / qmi8658HighCandidate() used by the s37uc board family.
- No Murphy-specific code was found that depends on LSM6DSO32X ±32 g, MLC, FSM, or sensor-hub features.
- Existing motion support is probe/axis oriented rather than tightly coupled to an LSM6DSO32X register implementation.

Conclusion: QMI8658A is firmware-feasible. A real QMI8658 device driver still needs initialization, sample read, FIFO/interrupt handling if used, orientation mapping and calibration tests. The ±16 g ceiling remains a product requirement gate, not a discovered firmware blocker.

## AXP2101

Panda OS currently exposes generic board-level fuel-gauge and charger types, but only BQ27220/BQ25896 are implemented in the existing type enum/driver path. No AXP2101 driver is present.

Required work:

- add AXP2101 PMIC type and driver;
- charger state/fault/USB presence mapping;
- battery voltage/current/SOC/e-gauge mapping;
- NTC and thermal fault handling;
- ship/power-off sequence;
- IRQ handling;
- safe startup defaults before firmware initialization.

Conclusion: firmware work is required but structurally contained. The existing Power/board abstraction does not force the old BQ25628/BQ27427 implementation.

## Passive USB-C sink

No product feature dependency was found that requires USB-PD or Type-C current-role negotiation.

For the C4 baseline, firmware may remove TUSB320 attach-state handling if the final product is fixed as USB2 device, 5 V sink only, no PD/PPS, and conservative charger input-current policy. USB insertion can instead be sourced from PMIC VBUS/IRQ state.

## Audio

Panda OS already models audio capabilities by board and supports I2S-based board implementations. The existing type enum does not name NS4168, but a direct-I2S amplifier does not require a codec control bus.

Required work:

- define the compact board playback path;
- set the NS4168-compatible I2S format/channel behavior;
- control the switched audio supply;
- add mute/pop sequencing tests.

Conclusion: NS4168 is firmware-feasible for a playback-only SKU. ES8311 + NS4150B remains a separate voice/capture SKU.

## RTC

Current generic RTC enum contains PCF8563. BM8563 is PCF8563-class but must not be assumed register-identical without testing.

Required work:

- confirm register compatibility;
- alarm/interrupt behavior;
- oscillator/load-cap assumptions;
- century/leap-year handling;
- backup-current and startup tests.

## XL9535

XL9535 retains the TCA9535-class 16-bit expander architecture.

Required regression:

- address;
- power-on input defaults;
- configuration/output/polarity/input register behavior;
- active-low open-drain INT semantics;
- brownout / partial-power behavior.

The C4A CAD candidate is topology-identical, so this is a firmware/device-behavior regression rather than a board-software architecture change.

## SGM37601 front light

C4D-10B requires a fail-closed startup sequence because SGM37601 reset defaults are 20 mA and 36 V OVP, above the FT01C 15 mA/string contract. Firmware must keep FL_HWEN/FL_PWM low, program 14.5 mA (`0x56`), 18 V OVP/internal compensation (`0xA1`) and 1 MHz/PFM (`0x2B`), then assert PWM. Shutdown must deassert PWM before HWEN. Address 0x36 has no documented conflict in the current compact I2C map.

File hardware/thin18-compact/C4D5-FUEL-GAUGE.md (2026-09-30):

# Thin18 Compact C4D-5 — domestic fuel gauge

Date: 2026-09-29

Implemented candidate: `c4d5-96x68-cw2217`

- Cellwise `CW2217BAAD`, JLC C5203993, DFN-12.
- Symbol/footprint were transcribed from the public JLC/EasyEDA model and checked against the Cellwise pin contract.
- U301 BQ27427 and R307 BIN pulldown are DNP/off-board in this compact candidate.
- R306 is upgraded to FOJAN `FRM121WFR010TM` / C7467248: 10mΩ, 1W, ±1%, ±50ppm/°C, 1206.
- CSP is on the system side (`BAT_PACKP`), CSN on the cell-connector side (`BAT_CONN_P`), so charge current is positive and discharge current negative.
- CW2217 VDD and VCELL use separate 100Ω filters; VCELL has a dedicated 1µF filter capacitor.
- TS reuses the existing external 10k / B3435 NTC path.

Fresh KiCad:
- ERC 0
- DRC 0
- schematic parity 0
- open 409 (expected: compact board is intentionally not fully routed)

The lower-Iq CW2215B remains a future optimization, not the current EVT baseline, because its public WLCSP ball map was not reproducibly available in this cycle.

Physical SOC/current accuracy, battery profile/FastCali data, NTC behavior and sleep current remain NOT_RUN.

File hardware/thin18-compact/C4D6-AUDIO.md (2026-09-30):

# Thin18 Compact — C4D-6 domestic audio

Date: 2026-09-29

C4D-6 replaces the assembled MAX98357A audio path with mainland Nsiway NS4168 / LCSC C910588.

Implemented:
- U904 NS4168 on ESOP-8 exposed-pad footprint;
- existing VSYS_AUDIO switched domain retained;
- existing I2S_BCLK / I2S_LRCLK / I2S_DIN retained;
- existing SPK_P / SPK_N and J502 speaker connector retained;
- old U502 and R503-R506 remain schematic DNP references only and are removed from PCB population.

Native checks:
- ERC 0
- DRC 0
- schematic parity 0
- open 399 (compact board still intentionally unrouted)

Firmware gate:
- NS4168 channel selection is controlled by CTRL=VSYS_AUDIO in this EVT candidate;
- firmware must ensure valid right-channel content, or duplicate mono content to both I2S channels.

Physical qualification remains open: output power, idle current, pop/click, polarity, thermal and EMI.

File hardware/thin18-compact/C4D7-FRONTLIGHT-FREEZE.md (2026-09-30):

# Thin18 Compact — C4D-7 front-light domestic freeze

Date: 2026-09-29

Status: engineering selection frozen; CAD integration remains gated.

## Selected mainland driver

SGMICRO `SGM37601YTRL20G/TR` is selected as the C4 domestic front-light driver.

Reasons:
- active production device;
- 2.8–24 V input;
- boost output up to 40 V;
- six current sinks, 6–25 mA/channel;
- I2C-controlled LED current / switching frequency / dimming;
- programmable OVP, default 36 V;
- TQFN-3.5×3.5-20L;
- internal compensation is enabled by default.

FT01C mapping target:
- LED1 -> warm string cathode (`FL_W_N`);
- LED2 -> cool string cathode (`FL_C_N`);
- LED3..LED6 disabled/unpopulated;
- W+ and C+ -> boost `FL_VOUT`;
- A0 = GND -> 7-bit address 0x36;
- EN -> `FL_HWEN` from U601 P15;
- PWM held in an enabled/static state; brightness/color baseline controlled by I2C.

## Required support network

Before CAD release, add as one controlled ECO:
- 10 µH mainland inductor;
- external Schottky diode with VR above programmed OVP;
- >=4.7 µF input bulk;
- >=1 µF VDC decoupling;
- >=4.7 µF high-voltage output capacitor with effective capacitance verified at operating voltage;
- optional input RC per low-VIN application guidance;
- internal compensation baseline; COMP remains unpopulated unless bench stability requires external RC.

## J804 gate

Panel connector remains Hirose `FH34SRJ-6S-0.5SH(50)` candidate:
- 6 positions;
- 0.5 mm pitch;
- 1.0 mm height;
- 0.30 mm FPC;
- top-and-bottom contacts.

No mainland connector has proven exact mating/land-pattern equivalence. J804 therefore remains a foreign mechanical retention item.

CAD integration is blocked until the official Hirose land pattern is imported rather than manually approximated.

## Qualification

Still required:
- current clamp <=15 mA/string;
- OVP programmed for the FT01C string voltage rather than leaving 36 V default;
- shutdown leakage;
- color/brightness control;
- inductor current/thermal;
- switch-node ringing/EMI;
- audible noise;
- front-light uniformity.

Manufacturing release: false.

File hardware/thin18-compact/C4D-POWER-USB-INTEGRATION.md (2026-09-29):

# Thin18 Compact — C4D power / USB integration

Date: 2026-09-29

Status: engineering integration input; not manufacturing release.

## Corrected charger choice

C4D uses the **non-D SGM41513YTQF24G/TR**.

Important variant distinction:

- SGM41513 pin 2 = PSEL and pin 3 = nPG;
- SGM41513A/D pin 2/3 = D+/D- and can perform BC1.2-style source detection.

The compact baseline deliberately chooses the non-D part so the charger does **not** attach to the USB D+/D- pair used by ESP32-S3 native USB.

For the first EVT baseline:
- PSEL is held high;
- autonomous input-current limit starts at 500 mA;
- firmware may program IINDPM after boot if a later source-capability policy is added;
- no claim is made that passive Type-C Rd detects 1.5 A or 3 A advertised source current.

This is slower than an aggressive 1.5/3 A charge policy but is deterministic and safe for the simplified USB-C architecture.
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

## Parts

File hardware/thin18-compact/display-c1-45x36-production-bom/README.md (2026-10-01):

# Display-C1 display board

45 × 36 mm, two copper layers. Native DRC/open/parity/ERC: 0/0/0/0.
U1-U3 use AIP74LVC2G17GC363.TR, Wuxi I-core, LCSC C3294722.
J1 remains DF40C-60DP-0.4V(51), bottom side at (23,4) mm, rotation 0°.
The exact connector, panel FPC, MOSFET and inductor contracts remain retained.
Active production data is ../production/display-c1-45x36/.
manufacturing_release=false; physical EVT and actual fit remain open.

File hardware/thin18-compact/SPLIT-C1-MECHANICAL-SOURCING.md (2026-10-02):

# Split-C1 current mechanical and sourcing state
2026-10-02. Core-C1 + Display-C1,PCB design only;no physical samples.
Current source documents supersede older integrated-board studies in Git history.

| Item | Current state |
|---|---|
| Boards |Core96×68×0.8mm/4layers;Display45×36×0.8mm/2layers|
| Mating |HCTL DS/DP60pin pair;1.5mm nominal gap,physical maximum/tolerance fit pending|
| Interface |xCore=xDisplay+38,yCore=66−yDisplay,zCore=−1.5−zDisplay;all60pins verified|
| Domestic identity |155 populated refs,155 mainland,0 foreign/unknown;separate supply/qualification gates|
| SMT mapping |Core110/116,Display37/37;six Core exact IDs/consignment acceptance missing|
| Manual assembly |Core C301 horizontal1F cap after SMT;offboard Shiheng TH301|
| Main pack |complete54×36×5.5mm maximum budget;1100mAh nominal/900mAh minimum targets;no selected exact mainland pack|
| Enclosure |112×75×21mm engineering box;calculated thickness20.5mm;not released CAD/fit|
| RTC |SD3078+KAMCAP rechargeable cap;>=24h isolated backup target,physical testsNOT_RUN|

The side pack sits below Core B in[1,11,37,65];Display projects[38,30,83,66].
It is1mm apart in XY and avoids the static J503 body;its mated antenna cable
still needs a solid volume. Backside parts/bosses budget1.5mm plus0.3mm insulation,
pack5.5mm plus0.7mm swelling and rear wall0.8mm give rearZ−8.8mm.
Core0.8+front max6.5+mount0.2+panel clearance0.5+panel2.2+front wall0.8
give frontZ11.0mm;reserve0.7mm gives20.5mm,rounded enclosure box21mm. These are explicit engineering
allowances,not supplier-signed pack/panel/mounted maxima.

C301 KAMCAP SE-5R5-D105VYH3C/C2894294 has max diameter19.2mm/overall H6.5mm on Core F,20mm nominal pitch.
It is horizontal THT,mounted0.2mm above PCB and hand-soldered after SMT;
rear lead protrusion must be<=0.5mm. Both plated pads overlap Display XY and
must clear the opposite board/connector/solder/retention solids. Native
copper/hole clearances are checked;they do not verify Z clearance.
H804 must not receive a boss/fastener that enters the main battery.
Model exact FPC bending/latch/tool,USB/microSD travel,antennas,speaker,
supports and battery harness before releasing a case.

J301 is HCTL HC-HY-2AWT,2mm pitch,5.2mm body/5.5mm preliminary max budget.
Pack housing HC-HY-2Y/HC-HY-T,AWG26,100..120mm preliminary harness;pin1 BAT+.
TH301 is independent10k/B3435K Shiheng100mm harness;no unknown pack NTC parallel.
The EEMB historical52×34.5×5.3mm protected pack only screens body size:
imported JST connector,45mm wires,1A continuous PCM and unspecified chip origin
prevent adopting that old assembly as an all-mainland selected pack.

Existing0.2mm main power branches/vias still need current/temperature redesign
or an approved lower-current contract. Connector3A/5A ratings do not qualify
the whole PCB current path. Charge/current/thermal and startup/RCB conditions
remain after physical samples;approved limits/firmware are still required.
This is distinct from native DRC/parity/electrical continuity checks.

Six SMT positions/three procurement groups,net maps,prohibited substitutions and
unaccepted JLC IDs are in split-c1-smt-consignment.json.
Actual stock,MSL/lot/tape attrition,double-sided carrier panel and assembler
acceptance are pending. C301/H3C/C2894294 catalog is exact but current stock quantity is unverified;D202/C55274065 observation0;
read-only catalog results do not reserve supply. No orders/messages shipped.
Current plans and primary source links:
- SPLIT-C1-DOMESTICIZATION.md / split-c1-domestic-eco.json
- C4D8-RTC-DECISION.md / SPLIT-C1-RTC-FIRMWARE.md
- SPLIT-C1-PACK-INPUTS.md / SPLIT-C1-ENCLOSURE-STUDY.scad
- SPLIT-C1-PROCUREMENT-QUESTIONS.md / split-c1-sourcing-evidence.json
- JLC-PROTOTYPE-HANDOFF.md / split-c1-mechanical-audit.json

XTEINK X4 Pro1100mAh/5.95mm is a reference. No matched measured runtime or
5.95mm Panda fit is claimed. Q04–Q14 remainNOT_RUN;no physical EVT is invented.

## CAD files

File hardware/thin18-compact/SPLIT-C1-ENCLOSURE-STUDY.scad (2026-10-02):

// Thin7 requirement supersedes the old21mm study.
include <thin7/THIN7-ENCLOSURE-STUDY.scad>

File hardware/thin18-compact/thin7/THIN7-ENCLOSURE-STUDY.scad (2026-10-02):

// Thin7 MECHANICAL PARTITION; empty PCB outlines, not fabrication inputs.
// Panel/pouch/connector/support tolerances and routing are not qualified.
module slab(r,z,h){translate([r[0],r[1],z])cube([r[2]-r[0],r[3]-r[1],h]);}
module rounded(w,h,r,z){translate([r,r,0])linear_extrude(height=z)offset(r=r)square([w-2*r,h-2*r]);}
color([.1,.12,.14])rounded(112,75,5,.55);
color([.1,.12,.14])translate([0,0,.55])difference(){rounded(112,75,5,5.75);translate([.65,.65,-.01])rounded(110.7,73.7,4.35,5.77);}
color([.1,.12,.14])translate([0,0,6.8])difference(){rounded(112,75,5,.2);translate([10.2,5.945,-.01])linear_extrude(height=.22)offset(r=1.1)square([91.6,54.48]);}
color([.1,.12,.14])translate([0,0,6.3])difference(){rounded(112,75,5,.5);translate([3.085,1.75,-.01])cube([105.83,62.87,.52]);}
color([.05,.4,.22])translate([0,0,0.7])linear_extrude(height=.8)polygon([[5, 57], [66, 57], [66, 42], [104, 42], [104, 72], [5, 72]]); // Core-Thin7 EMPTY TEMPLATE
color([.06,.23,.38])translate([0,0,0.7])linear_extrude(height=.8)polygon([[65.9, 4], [110.9, 4], [110.9, 40], [65.9, 40]]); // Display-Thin7 EMPTY TEMPLATE
color([.65,.66,.63])slab([3, 3, 65, 54],.7,3.1); // complete-pack MAX requirement; not selected SKU
color([1,.6,.1,.20])slab([3, 3, 65, 54],3.8,.5); // swelling space, must remain empty
color([.17,.17,.17,.35])slab([3.335, 2.0, 108.665, 64.37],4.6,2.2); // panel thickness budget
// Border frame covers the inactive panel area ABOVE6.8 only; underside pocket avoids solid overlap.
// Uniform outer thickness7.0mm; no scaled native PCB/module/component bodies.

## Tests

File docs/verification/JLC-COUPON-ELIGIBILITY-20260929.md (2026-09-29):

# 嘉立创优惠券适用性审计 — Thin18 routing142

日期：2026-09-29
对象：Thin18 `routing142`
性质：优惠条件工程审计，不代表嘉立创订单系统最终核券结果。

## 结论

当前 Thin18 **不满足“10×10 cm 以内”类 PCB 免费打样 / PCB+SMT 券的基本尺寸条件**。

主要阻塞：

- 当前 PCB 外形：**70.0 × 128.1 mm**
- 优惠基本条件：长、宽均需在 **100 × 100 mm** 范围内
- 因此 128.1 mm 一边超限 28.1 mm。

开源本身不会覆盖此尺寸限制。

## 条件逐项审计

| 条件 | 当前项目 | 结果 |
|---|---|---|
| 1–4 层 / 4 层允许 | 4 层，F/In1/In2/B | PASS |
| 板尺寸 ≤100×100 mm | 70.0×128.1 mm | **FAIL** |
| 长宽不得小于 10 mm | 70.0×128.1 mm | PASS |
| 5 PCS | 下单参数，不由 EDA 文件决定 | ORDER-TIME |
| 单片出货，不拼版 | routing142 是单板设计；必须下单选单片，不选择代拼 | PASS IF ORDERED AS SINGLE |
| 4 层仅绿油 | EDA 源文件不锁定生产阻焊颜色 | MUST SELECT GREEN |
| 常规工艺 | 4 层、0.8 mm、通孔、0.15 mm min trace、0.2 mm drill，现有制造审计可走常规工艺 | PASS WITH EXISTING OPEN DFM GATES |
| 嘉立创 EDA 专用券 | 当前源设计为 KiCad 10.0.5 | **FAIL FOR EDA-SPECIFIC COUPON** |
| 通用 1–4 层券 | 官方规则不限制设计软件 | SOFTWARE PASS, SIZE FAIL |
| PCB+SMT 券 | 必须在订单中选择 SMT | NOT READY: exact production BOM/SMT qualification is still open |
| 沉金券 | PCB stackup 声明 `copper_finish "Nickel, Gold"` | PASS ON PROCESS SELECTION |
| 沉金面积 <20% | 见下方保守面积审计 | PASS BY ENGINEERING UPPER BOUND |
| 开源文件当月未重复享惠 | 只能由嘉立创订单系统判断 | ORDER-SYSTEM CHECK |

## 沉金面积保守上界

整板矩形面积：

`70.0 × 128.1 = 8967 mm²`

20% 门槛：

`1793.4 mm²`

从 routing142 KiCad PCB 的 651 个焊盘读取阻焊开窗，并把圆形、椭圆、圆角矩形全部按更大的外接矩形计入，得到保守上界：

- F.Mask：`423.08 mm²`，约整板面积 **4.72%**
- B.Mask：`73.26 mm²`，约 **0.82%**
- 两面简单合计：`496.34 mm²`，约 **5.53%**

该算法有意高估常规焊盘面积，因此仍显著低于20%。最终受镀面积以嘉立创上传后的 Gerber/DFM 计算为准。

## 订单建议

如果使用当前 routing142：

1. 不要为了免费券而把 128.1 mm 主板强行压缩到 100 mm；这会变成产品架构/机构级改版。
2. 选择 **4 层 / 0.8 mm / 绿油 / 单片 5 PCS**。
3. 如使用沉金类优惠，选择 **ENIG**；上传后再次确认平台报告的沉金面积 <20%。
4. 不选择拼版/代拼，否则不满足“单片出货”的券规则。
5. 如果券是“嘉立创 EDA 专用券”，当前 KiCad 文件不要强行套用；应使用通用券，或另外建立受控的嘉立创 EDA 原生版本并重新做等价性验证。
6. 如果券是 PCB+SMT，必须选择 SMT；但当前生产 BOM / LCSC 料号 / SMT 装配资格仍未闭合，不应为了用券提前下 PCBA。
7. 开源文件若在下单页显示“拆单 / 已被其他客户享受优惠”等提示，则按当月规则不能再次享受该文件优惠；这个状态无法由 Git 仓库离线验证。

## 当前更合理的优惠路径

当前板型优先寻找：

- 不受 100×100 mm 限制的开源项目专项支持 / 活动资源；
- 普通付费裸板 + SMT / 元器件专项优惠；
- 后续产品若自然出现 ≤100×100 mm 的子板，再使用常规免费打样券。

不建议单纯为了节省一次 PCB 打样费用，把 70×128.1 mm 主板拆板或缩短。

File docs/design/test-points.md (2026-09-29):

# Panda 標準電子書板：測試點計畫

日期：2026-08-10（USB／IRQ 同步：2026-09-08，執行者：Codex）
狀態：WP2 已凍結測試需求類別（非顯示部分）；實際落板座標／治具可達性未凍結，轉接板高壓網路待 WP1
適用板號：`PANDA-STD-CORE-EVT`、`PANDA-STD-ADP-<精確面板料號>-EVT`

當前正式CAD為149封裝／1566段／311via，DRC 0/0/0、ERC 19；共同依據見
[USB2 S-9 A-stage](lib/review/USB2-S9-A-stage.md)。下文8月checkpoint座標均為**歷史、非目前布局座標**，
保留其推導而不改成新板位置；治具可達性、製造與台架資格仍未關閉。

---

## 1. 分區原則（凍結）

| 分區 | 位置 | 內容 | 探測方式 |
| --- | --- | --- | --- |
| **TP-LV-CORE** | 核心板 | 低壓電源、地、I²C、關鍵時序、中斷、電源鍵 | 彈簧針（pogo）治具 + 手動探針 |
| **TP-LV-ADP** | 轉接板低壓區 | 顯示低壓、I²C、EPD 邏輯時序、PWR_GOOD、觸控、前光控制 | 手動探針 |
| **TP-HV-ADP** | 轉接板**受控高壓區** | ±HV、VCOM、PMIC 高壓節點 | **僅手動探針，需受控程序** |

### 1.1 硬邊界

| 邊界 | 規則 |
| --- | --- |
| HV／VCOM 測試點**只**存在於轉接板受控區 | 核心板**無**任何高壓測試點 |
| HV 測試點**不得**與 LV pogo 治具區共用或相鄰 | pogo 治具接觸面上不得出現任何高壓網路 |
| HV 區與 LV pogo 區須有明確絲印與間距分隔 | 防止治具誤觸 |
| pogo 治具**不接觸**轉接板 | 治具只服務核心板底面 |

**理由**：pogo 治具是產線／返修可重複、可能由非工程人員操作的接觸面。任何高壓網路出現在該面上都是
人員與設備風險。`design.md` §3 已要求「高壓測試點只在適配板受控區域」，本文件把它落實為分區與間距規則。

---

## 2. TP-LV-CORE：核心板測試需求凍結；落板位置未凍結

### 2.1 電源與地（必備）

| 測試點 | 網路 | 類型 | 目的 |
| --- | --- | --- | --- |
| TP1 | `VBUS_USB` | 焊盤 | charger側VBUS觀測；與J201同網不等於connector端ESD/inrush瞬態測點，入口須在座端／治具量測，M0可達性未定 |
| TP2 | `VSYS_RAW` | 焊盤 | NVDC 輸出、buck/boost 交越觀測、音訊峰值反映 |
| TP3 | `3V3_AON` | 焊盤 | 主軌電壓、紋波、負載階躍 |
| TP4 | `BAT+` | 焊盤 | 電芯端電壓 |
| TP5 | `3V3_SD` | 焊盤 | 關斷／致能驗證 |
| TP6 | `3V3_TOUCH` | 焊盤 | 關斷／致能驗證；反灌檢查 |
| TP7 | `3V3_EPD_LOGIC` | 焊盤 | 關斷／致能驗證 |
| TP8 | `VSYS_AUDIO` | 焊盤 | 音訊域關斷驗證 |
| TP9 | `VSYS_FL_IN` | 焊盤 | 核心板送往 adapter 的 unswitched input 觀測；**不能**用來宣稱前光關斷 |
| TP10 | `EPD_HV_IN` | 焊盤 | 送轉接板的低壓輸入 |
| TP-GND ×**≥6** | `GND` | 焊盤，分散 | 見 §2.5 |

### 2.2 電流量測斷點（凍結為必備）

`design.md` §5 要求「可隔離電源域的測量斷點」。USB監控加入前的**歷史**計算包絡為36.45–40.45µA；
以精確舊基數35.445µA加本批3.8µA指定穩態假設及1–5µA超級電容估算，當前混合工程包絡為
**40.25–44.25µA**，不是整板max。IMU、load-switch、板漏、實際DC狀態及尚未實現的RTC後備仍待測，
未通過50µA門（[power-tree.md](power-tree.md) §5.1）；逐域電流量測是
**達標判定的必要條件**，不是選配。

| 斷點 | 位置 | 形式 | 目的 |
| --- | --- | --- | --- |
| MB1 | `BAT+` 串聯 | 0 Ω 0805 + 兩側焊盤 | 整板電流（深睡 µA 級判定） |
| MB2 | `3V3_AON` 出口串聯 | 0 Ω 0805 + 兩側焊盤 | 常供域合計；源側=`3V3_AON_SRC`，負載側=`3V3_AON` |
| MB3 | `3V3_SD` 串聯 | 0 Ω + 兩側焊盤 | SD 域 |
| MB4 | `3V3_TOUCH` 串聯 | 0 Ω + 兩側焊盤 | 觸控域（觸控喚醒資格必需） |
| MB5 | `3V3_EPD_LOGIC` 串聯 | 0 Ω + 兩側焊盤 | EPD 邏輯域 |
| MB6 | `VSYS_AUDIO` 串聯 | 0 Ω + 兩側焊盤 | 音訊域峰值 |
| MB7 | `EPD_HV_IN` 串聯 | 0 Ω + 兩側焊盤 | 送轉接板的總輸入 |

核心板**不設** `VSYS_FL_SW` 測量斷點：核心只傳 `VSYS_FL_IN`，adapter 擁有前光 load switch／driver、
`VSYS_FL_SW` 及 switched-rail test point。

**斷點規則**：
- 0 Ω 選 0805 或更大，便於換成分流電阻或接電流錶
- 兩側焊盤須可同時接兩支探針
- MB1 必須能承載最壞峰值電流（音訊 0.46 A **[算]** + MCU + SD，經 §3.2 boost 放大係數）
- 深睡量測時 MB1 可換為高精度分流電阻

⚠ MB6 所在的 `VSYS_AUDIO` 峰值約 0.46 A（**[算]**，見 power-tree.md §6.2），0 Ω 封裝須按此額定選，
不可與 µA 級域的斷點用同一規格。

2026-08-12 A-stage layout checkpoint：MB6 已以 `R508=0 Ω/0805` 置於 `(102.60,44.30)/180°`，两端
`VSYS_AUDIO_SW/VSYS_AUDIO` pads 均保持裸露可探；`TP8=TestPoint_Pad_D1.5mm` 位于 `(98.00,45.75)`，接
MB6 下游 `VSYS_AUDIO`。这只确认当前暂定板框内的可达性；M0 治具坐标、精确 0 Ω MPN、电流降额、探针净空
与不同身份 B-stage 仍未冻结。

2026-08-13 A-stage switched-rail checkpoint：MB3/MB5/MB4 分别以 `R514/R516/R515=0 Ω/0805` 置于
`(95.00,7.00)/(95.00,13.00)/(95.00,19.00)`；对应下游 TP5/TP7/TP6 位于
`(99.00,7.00)/(99.00,13.00)/(99.00,19.00)`。三组两端均保持可探测，输出在 M0 冻结 microSD/板间连接器前
止于 MB/TP。上述坐标只是当前暂定板框的工程候选；治具坐标、探针净空、0 Ω 精确 MPN 与额定仍未冻结。

2026-08-13 A-stage battery-measurement checkpoint：MB1 已以 `R306=0 Ω/0805` 置于
`(29.50,45.50)/F.Cu`，上游 `BAT_CONN_P` 接 `TP4=(26.00,45.50)/F.Cu`，下游 `BAT_PACKP` 接
U301.C3 `BAT`。R306 两端保持可探，0.80 mm 铜连接；J301/harness、治具坐标、最坏峰值额定与探针净空
仍待 M0/F0/B-stage，当前 TP4/MB1 不能冒充已冻结的电池连接器位置。

2026-08-13 A-stage MB2 checkpoint：`R509=0 Ω/0805` 置於 `(83.50,38.50)/90°/F.Cu`；pad 1
`(83.50,39.4125)=3V3_AON_SRC`，pad 2 `(83.50,37.5875)=3V3_AON`，兩側保持裸露可同時探測。源側由
TPS63802 local star 經 0.80 mm In2/F.Cu 主段接入，負載側以 0.80 mm F.Cu/In2.Cu 回接既有系統 trunk；
source/load copper node 集合無交集，拔除 R509 才真正隔離常供負載。`TP3=(85.80,35.00)/F.Cu` 位於 MB2
下游。R509 exact MPN、額定／分流替換壓降、探針淨空與治具坐標仍待 F0/M0/WP9/B-stage。

### 2.3 匯流排與訊號（需求類別凍結；落板／治具座標未凍結）

| 測試點 | 網路 | 目的 |
| --- | --- | --- |
| TP11 | `I2C_SCL` | 位址掃描、上升緣實測（上拉阻值定案依據） |
| TP12 | `I2C_SDA` | 同上 |
| TP13 | `EXP_INT` | RTC及核心／適配器TCA共享通知，不能提供獨立來源位 |
| TP14 | `EXP_INT`（SHARED_IRQ） | 與TP13同網；配合RTC／TCA寄存器判別RTC闹钟，不再接GPIO2 |
| TP15 | `KEY_POWER_MCU`／鄰近 `QON_BTN` 雙點 | 按鍵去抖、長按時序、雙刀隔離、AON=0 漏電與 ship-mode 退出驗證 |
| TP16 | `PG_3V3_MAIN` | TPS63802 PG 時序 |
| TP17 | `SDMMC_CLK` | SD 時序（**見 §2.4 約束**） |
| TP18 | `CHIP_PU`（`EN`） | 復位 RC 時序 |

**歷史（2026-08-13，已被後續IRQ合併覆蓋，非當前布局座標）**：`TP14=TestPoint_Pad_D1.5mm` 已置于 `(47.00,35.50)/F.Cu`，接
`RTC_INT`，并与 U302.2、R305.2、U501 pad38/GPIO2 同网。其当前几何已通过 DRC 与 netlist audit；M0 治具
坐标、探针净空、外壳可达性及不同身份 B-stage 仍未冻结。

2026-09-08 當前網路覆蓋：EXP_INT包含U302.2、U601.1、U501.4、TP13、TP14及R502；R305仍DNP，
R502=100k為唯一已裝核心上拉。RTC定時喚醒保留，TP14不是獨立RTC線，GPIO2/pad38已用於VBUS。
適配器TCA INT只可開漏加入、不得另加IRQ上拉；讀清全部源並確認線釋放後才可重入睡眠。

以下座標由2026-09-08正式PCB只讀取得，僅為當前工程落點，不是已批准的治具datum／探針可達性：

| 測試點 | 當前F.Cu中心（mm） | 當前網路 |
| --- | --- | --- |
| TP1 | (40.6,62.1) | VBUS_USB，charger側 |
| TP13 | (14.1,41.7) | EXP_INT，共享 |
| TP14 | (36.6,62.7) | EXP_INT，共享 |
| TP18 | (36.6,103.7) | CHIP_PU，復位RC |

**歷史（2026-08-13 observability checkpoint，非當前布局座標）**：`TP1=(47.60,39.50)` 接 charger-side `VBUS_USB`，
`TP2=(72.00,35.00)` 接 `VSYS_RAW`，`TP3=(85.80,35.00)` 接 MB2 下游 `3V3_AON`，
`TP16=(67.50,45.75)` 接 `PG_3V3_MAIN`，`TP18=(6.00,35.50)` 接 `CHIP_PU`；全部位於 F.Cu，且已通过
DRC/netlist/source audit。TP1 只是在 J201 尚未冻结时可用的 charger 输入观测点，不能冒充未来 connector-side
VBUS exact fixture point；TP18 的走线位于 U501 天线 keepout 下缘 Y=21 mm 之外。

`I2C_SCL`／`I2C_SDA` 測試點是 PRD 要求的「燃料計獨立總線測試點」與「RTC 總線測試點」的實現
（PRD §124、§125）。

### 2.4 ⚠ 高速訊號測試點的約束

以下訊號**不設**專用測試點焊盤：

| 訊號 | 理由 |
| --- | --- |
| `USB_D+`／`USB_D−` | 90 Ω differential、pair skew ≤0.5 mm；測試點會破壞阻抗連續性，改由 USB-C 座端或治具側量測 |
| `EPD_D0–D7`、`EPD_CKH`、`EPD_CKV` | 20 MHz 級並列匯流排；實際長度目標待 WP1 介面時序，不借用 SDMMC 的 ±50 mil 規則；加焊盤會引入 stub |
| `SDMMC_CMD`、`D0–D3` | 各自與 `CLK` 長度差 ≤50 mil（1.27 mm），50 Ω ±10% single-ended，不得跨層 |

**替代方案**：以邏輯分析儀夾具直接夾元件腳位或連接器腳位，不在走線上加焊盤。`SDMMC_CLK`（TP17）
單獨保留是因為它是時序基準且只有一條，可在靠近卡座處以短 stub 引出，但**該 stub 長度須在 WP7A 規則中
明確限制**（建議 ≤2 mm，具體值待 WP3 仿真）。

這是與「探測可達性」需求的直接權衡：**訊號完整性優先於探測便利性**，高速群改用夾具而非焊盤。

### 2.5 地測試點規則

| 規則 | 內容 |
| --- | --- |
| 數量 | ≥6，分散於板面 |
| 位置 | 每個訊號測試點群旁至少一個；每個電源測試點旁至少一個 |
| 高速量測 | `SDMMC_CLK`（TP17）旁必須有地焊盤，供短接地環量測 |
| 治具 | pogo 治具區內至少 2 個地點 |

地點不足會使高頻量測結果失真，屬常見量測誤差來源，故列為凍結規則。

2026-08-13 A-stage GND checkpoint：TPG1–TPG6 分別位於 `(5.00,56.00)`、`(42.00,56.50)`、
`(65.00,57.00)`、`(105.00,56.00)`、`(105.00,28.00)`、`(52.00,5.00)`，均為 F.Cu
`TestPoint_Pad_D1.5mm`。每點以 0.40 mm 短 stub 接一顆專屬 0.60/0.30 mm through-via，下沉 In1.Cu GND
plane；六點最小中心距 23.005 mm。這證明目前暫定板框內有分散觀測點，不代表底面 pogo 接觸面、fixture
pin map、外殼可達性或 M0 治具已批准；正式 pogo 區仍須按 §2.6 另行凍結。

### 2.6 pogo 治具區（與調試焊盤共用）

已凍結的六網調試／恢復焊盤（`UART0_TX`、`UART0_RX`、`EN`、`GPIO0`、`3V3`、`GND`）本身即為 pogo
治具區。本文件補充：

2026-08-13 A-stage 落点为 `J503=(40.00,26.50)/90°/B.Cu`，采用 TC2030-IDC-NL 六接点与 3 个
0.9906 mm NPTH 定位孔；针序 1–6=`CHIP_PU/3V3_AON/UART0_RX/GND/UART0_TX/GPIO0`。这是当前
110 × 60 mm 暂定板框内的受控候选，不冻结最终治具 datum、mating-face、探针行程或外壳开口。

| 約束 | 內容 |
| --- | --- |
| 位置 | 核心板**底面**，無外露連接器 |
| 隔離 | 須與天線、開關電源節點（`L1`／`L2`）、音訊、IMU、顯示 FPC 隔離 |
| **高壓** | 治具區內**禁止**任何高壓網路（本設計核心板本就無高壓） |
| 可否與 §2.1–2.3 測試點合併治具 | 可，但合併後治具接觸面仍須滿足上述隔離與無高壓規則 |
| 驗證 | 須完成治具下載／恢復驗證（WP9） |

---

## 3. TP-LV-ADP：轉接板低壓測試點（凍結規則，網路待 WP1）

| 測試點類別 | 網路 | 狀態 |
| --- | --- | --- |
| 地 | `GND` ≥4 個，分散 | 凍結規則 |
| 低壓電源 | `3V3_EPD_LOGIC`、`3V3_TOUCH`、`VSYS_FL_IN`、adapter-switched `VSYS_FL_SW`、`EPD_HV_IN` | 凍結；`VSYS_FL_SW` 測試點由 adapter 擁有 |
| 管理匯流排 | `I2C_SCL`、`I2C_SDA` | 凍結 |
| 中斷 | 轉接板擴充器 `INT`、`TOUCH_INT` | 凍結 |
| EPD PMIC 狀態 | `PWR_GOOD`、`PWRUP`、`WAKEUP`、PMIC `INT` | 凍結類別，具體網路名待 WP1 |
| 關鍵時序 | 顯示時序訊號中至少 `CKV`、`STV`、`LE`（低速側） | 凍結類別 |
| 觸控 | `TOUCH_RST` | 凍結 |
| 前光 | LM3630A 類 `HWEN`、`INTN` | 凍結類別 |

`design.md` §3 要求「兩側提供地、低壓、I²C、關鍵時序、PWR_GOOD/VCOM 測試點」。⚠ 其中 **VCOM 屬高壓類**，
歸入 §4，不在本節。

---

## 4. TP-HV-ADP：轉接板高壓測試點（受控區）

### 4.1 網路（凍結類別，具體值待 WP1）

| 測試點 | 網路類別 | 典型值（TPS65185 類，**[手]** SLVSAQ8G） |
| --- | --- | --- |
| HV1 | `VPOS` | +15 V，120 mA |
| HV2 | `VNEG` | −15 V，120 mA |
| HV3 | `VDDH`（閘極驅動正） | +22 V，15 mA |
| HV4 | `VEE`（閘極驅動負） | −20 V，15 mA |
| HV5 | `VCOM` | 面板／批次相依，**待 WP1** |
| HV6 | PMIC 升壓中間節點 | ±16 V |

實際電壓由 WP1 面板與 PMIC 決定；上表為 TPS65185 資料手冊值，僅作**受控區設計依據**，非凍結值。

### 4.2 受控區規則（凍結）

| # | 規則 |
| --- | --- |
| H1 | 全部 HV 測試點集中在轉接板**單一連續受控區**，不分散 |
| H2 | 受控區須有絲印邊框與高壓警示標記 |
| H3 | 受控區與任何 LV 測試點、連接器、pogo 接觸面之間須有明確間距（具體間距值待 WP0 層疊與板廠規則簽核後於 WP7B 凍結） |
| H4 | HV 測試點**只**允許手動探針，**禁止**設計成 pogo 治具接觸點 |
| H5 | 探測 HV 前必須確認 EPD 下電序已完成且電容已放電；放電路徑須存在且可驗證 |
| H6 | `VCOM` 測試點須可在不破壞面板連接的情況下量測（批次 VCOM 校驗需求） |
| H7 | 核心板側**不得**有任何 §4.1 網路的測試點或走線 |

### 4.3 為何 VCOM 必須可測

PRD 多處要求批次 VCOM 證據（面板批次間 VCOM 不同，需逐批確認）。HV5 是該證據的量測入口。
但 VCOM 屬高壓域，故歸入受控區而非 §3 的 LV 區——這是 `design.md` 原文「PWR_GOOD/VCOM 測試點」
在本文件被拆分到兩個分區的原因，須明確記錄以免後續誤解為降級。

---

## 5. 測試點與 WP9 台架的對應

| WP9 項目 | 依賴測試點 |
| --- | --- |
| 深睡整板電流（≤35 µA typ／50 µA 上限判定） | MB1（換分流電阻）+ 核心逐域 MB2–MB7 分解；前光 switched rail 在 adapter `VSYS_FL_SW` 測試點另驗 |
| I²C 位址掃描期望值（i2c-address-map.md §6） | TP11、TP12 |
| I²C 上拉阻值定案（上升緣實測） | TP11、TP12 + 鄰近地點 |
| buck/boost 交越瞬態 | TP2、TP3 + MB2 |
| 最壞負載階躍 | TP3、MB2、MB6 |
| 電源鍵長按硬體復位與 ship-mode 退出 | TP15、TP18、TP2 |
| RTC 闹钟喚醒 | TP13/TP14共享EXP_INT + RTC/TCA狀態讀回；同時中斷與持續低均須覆蓋 |
| 觸控深睡喚醒資格（若啟用） | MB4、TP13、TP6 |
| 治具下載／恢復 | pogo 六網 |
| EPD 上下電時序 | TP-LV-ADP `PWR_GOOD` 群 + TP-HV-ADP（受控） |
| 批次 VCOM | HV5（受控） |
| 音訊峰值電流與電池影響 | MB6、TP2、TP4 |
| USB拔除3ms／ROM與重新連接 | J201 VBUS、TP1及U206.4或R214.1(GPIO2)同步示波；不新增D±測試點，ROM另驗 |
| CC編碼／跨域／深睡 | R602/R603端口端與本地CC rail；四象限／半掉電以MB1/MB2分解電流 |
| 默認總源≤500mA | J201入口串聯量測全部負載與旁路，不能只測BQ輸入 |

---

## 6. 未凍結項目

| 項目 | 阻擋來源 | 解除條件 |
| --- | --- | --- |
| HV 受控區與 LV 區的具體間距值 | WP0 板廠層疊與規則未簽核 | WP0 完成 → WP7B |
| `SDMMC_CLK` 測試點 stub 長度上限 | 需 WP3 仿真 | WP3 |
| TP-HV-ADP 實際電壓值 | WP1 | WP1 |
| 轉接板 EPD PMIC 狀態網路名 | WP1 | WP1 |
| 測試點實際座標與絲印 | 已有部分 candidate 座標，但全板／治具座標未凍結 | WP7A／WP7B + M0 |
| pogo 治具機構設計 | 需核心板外形 | WP7A 後 |

---

## 7. 邊界聲明

本文件為測試點規劃，不是 PCB、不是治具圖，不構成任何認證聲明。§4.1 電壓值取自 TPS65185 資料手冊作為
受控區設計依據，**不是**本設計的凍結值。所有量測項目的通過與否須由 WP9 實測決定；本文件不宣稱任何
電流、時序或聲學指標已達標。

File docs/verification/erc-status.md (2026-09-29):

# 标准板 ERC 当前状态

日期：2026-09-09；执行者：Codex。

J501 merged 权威工程当前 ERC 为 **0 active report entries**，本轮显示/外置NTC/RTC真实电路关闭原16项。
独立候选复查及正式目录保存/重填的PCB DRC、未连接、schematic parity均0/0/0；这不代表实物资格或制造放行。
项目既有四类ignored checks（single_global_label、four_way_junction、simulation_model_issue、footprint_filter）未修改，
不把active ERC0说成所有规则类别均启用。完整本轮证据见[ERC16工程检查点](erc16-layout-status.md)。

## J502 前轮已修复（历史18→16）

J502.1→SPK_P/U502.9、J502.2→SPK_N/U502.10真实接通，两机械MP焊盘保持no-net。
仅消除SPK_P `65020112-0502-4502-8502-000000000112` 与SPK_N `65020114-0502-4502-8502-000000000114` 两条isolated_pin_label。
其余16条完整报告与旧源一致；没有新增NC/flag或忽略规则。详见[J502工程记录](lib/review/J502-GH-A-stage.md)。

## BQ_PG 前轮已修复（历史19→18）

U201.3 → U601.13/P10/R600.1 已真实接通，R600改10k/1%上拉至3V3_AON，保持原位置；原专用地via按批准删除。
唯一减少isolated_pin_label对象 `2a6b2b49-9f0a-4908-ac42-6b27f3dc0a07`，其余18条逐项不变。
三种实际副本负控分别拒绝断PG、错并PG_3V3_MAIN、恢复错误下拉；PG专属电气/固件/台架资格仍开放。
详见[BQ_PG/P10记录](lib/review/BQ_PG-P10-A-stage.md)。

## USB 前轮已修复（历史22→19）

真实J201接口、数据线与VBUS输入声明关闭U501.pad13/14未接及U201.pad18未驱动，剩余19条与正式基线原文一致。
GPIO2是改配而非额外关闭一个正式遗留；中间释放脚的第23条不计入净改善。八个当前原理图负控及J201内/外孔距负控通过。
细节见[USB2/S-9记录](lib/review/USB2-S9-A-stage.md)。

## Power/QON 前轮已修复

SW201双刀常开接点与R528真实上拉/走线关闭U501.39未接、U201.7未驱动、BQ_QON孤立标签三项；没有新增flag/NC/ignore。
两信号精确网络契约与三种断线/短接负控通过，见[开关记录](lib/review/EP21SD1ABE-A-stage.md)。

## 前轮已修复（历史28→25）

| 原报告 | 修复 | 证据与边界 |
| --- | --- | --- |
| U502.7 VDD power_pin_not_driven | `#FLG0103` 声明 VSYS_AUDIO 经 U405 和已安装 R508=0Ω/MB6 供电 | 真实网络和R508两侧网名保持；flag不代表常开或实测带载通过。 |
| J501.6 VSS power_pin_not_driven | `#FLG0104` 声明全板 GND 参考 | ERC按网报告，标记在J501不意味着J501局部断地；没有改变其标准库pin类型。 |
| U503.1 bidirectional↔power_out | 当前U503采用 `LSM6DSO32XTR_I2C_MODE1` | CS/SA0接Vdd_IO、SDx/SCx接GND；依据ST的Mode1引脚定义，pins1/2/3为input，其他类型保持，通用符号保留。 |

反向控制：移除audio声明后ERC26，仅恢复U502.7；移除GND声明后ERC26，仅恢复J501.6；恢复通用U503模型且保留
两声明后ERC28，新增U503.1/.2/.3三项pin_to_pin。恢复正向候选后ERC25，剩余25项与原报告原文一致。

## 原16项本轮闭合归属

| 功能／对象 | 原报告数 | 本轮真实实现／未验边界 |
| --- | ---: | --- |
| 显示接口：U501 IO16/17/18/21/38/39/40/41/42/47/48 | 11 pin_not_connected | 接J601真实低压显示接口，全部14显示网及电源/控制布线通过；面板、配对件与机械实物仍未验。 |
| GPIO45 | 1 pin_not_connected | 指定N16R8模块条件下接EPD_STH/J601.23；没有烧写或读回实物eFuse，启动资格仍开放。 |
| 电池温度：BQ_TS、BQ_TS_BIAS | 1 pin_not_driven + 2 isolated_pin_label | J302外置103JT-025-600AY NTC、R615=5.23k/R616=30.1k真实网络；配置读回、贴附与热响应未验。 |
| RTC_VBACKUP / U302.6 | 1 power_pin_not_driven | R304 DNP、C301=KW-5R5C684-R，依赖RV-3028内部trickle配置及预充；24h保持和漏电老化仍未验。 |

原报告分类合计：12 pin_not_connected、2 isolated_pin_label、1 power_pin_not_driven、1 pin_not_driven、0 pin_to_pin；本轮关闭后active合计0。
其中同一个未完成网络可能产生不同类别的报告；16是报告条目数，不是16个独立硬件故障。喇叭／线束／机械声学资格仍开放，不能由ERC减少推断通过。

## 当前源身份与复现

- SCH SHA-256：`b6e499f2a8917dc10115c5d25f54f65a86ac5f6a43d3d447a5a67dc88ba40fbc`。
- PCB SHA-256：`d96aef03000e560f7408079990fc9af17437914758e2f50310fa858d3e46a0d6`（Fix25，SD/USB/BQ/J502及旧铜保持，ERC16→0）。
- 项目symbol library SHA-256：`40412b7ff0d3518c8c520f12b428d5cbe551f387b8c7b6449ffe8fe44d9d591f`。
- KiCad10.0.5，在实际权威project目录执行 `kicad-cli sch erc --format json --severity-all --output <erc.json> <board>.kicad_sch`，
  并独立执行 `pcb drc --severity-all --schematic-parity --refill-zones --exit-code-violations`；ERC不能用进程exit0代替条目审计。
- 完整逐条UUID表和复现代码在Trellis任务 `09-07-panda-remaining-erc-layout`（此前Power/QON及模型修正记录保留） 的research/implementation-evidence/verification记录。

## 依据

- [KiCad10：power pins and power flags](https://docs.kicad.org/10.0/en/eeschema/eeschema.html#power-pins-and-power-flags)。
- [ST LSM6DSO32X，DS13607 Rev1，Table18](https://www.st.com/resource/en/datasheet/lsm6dso32x.pdf)。
- [Mode1 A-stage记录](lib/review/LSM6DSO32XTR-I2C-MODE1-A-stage.md)。
- [RTC无后备源记录](lib/review/RV-3028-C7-A-stage.md)。

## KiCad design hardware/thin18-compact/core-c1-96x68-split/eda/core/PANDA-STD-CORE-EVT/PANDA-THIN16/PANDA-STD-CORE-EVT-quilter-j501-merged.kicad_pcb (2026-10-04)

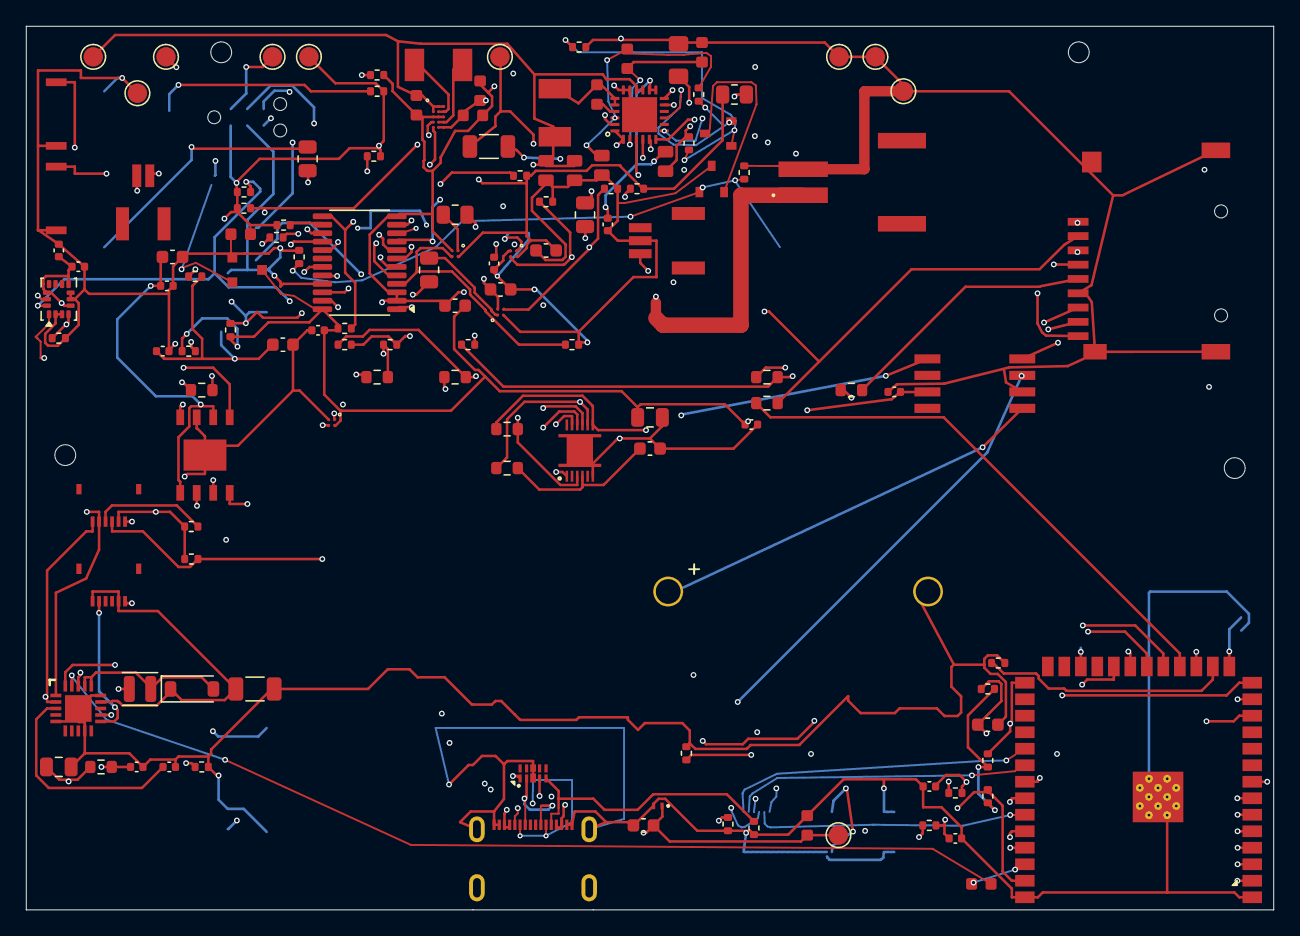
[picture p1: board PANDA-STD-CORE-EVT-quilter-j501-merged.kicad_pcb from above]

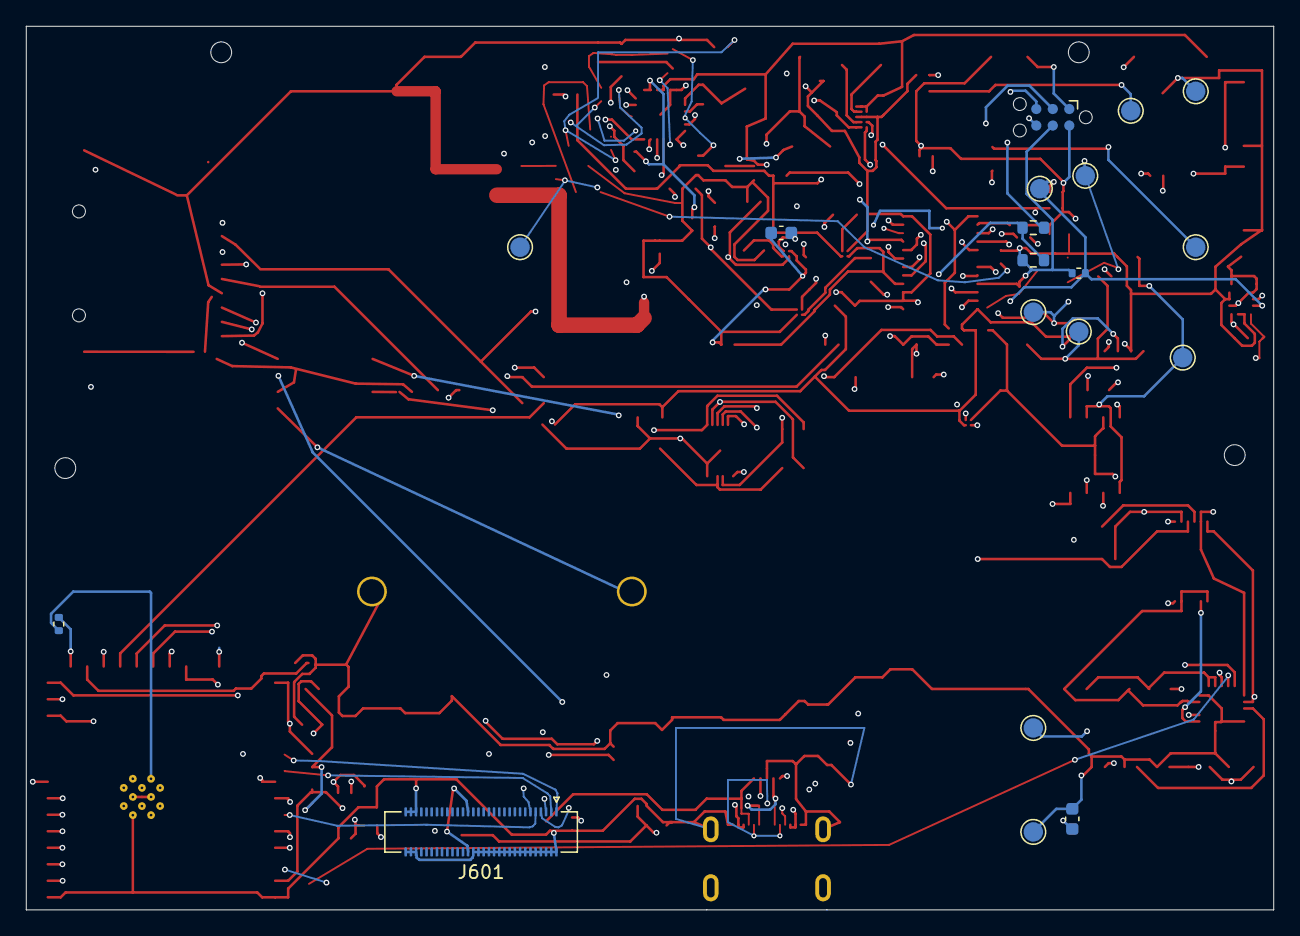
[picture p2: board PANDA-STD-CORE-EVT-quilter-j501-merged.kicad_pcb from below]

Board: 4 copper layers, 96.0 x 68.0 mm, 155 parts (19 on the bottom side), 93 nets.

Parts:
C201: 47n / CBOOT; C201_CBOOT_0603_SEED
C202: 1u / VBUS; C202_CVBUS_0603_ENVELOPE
C203: 10u / PMID; C203_CPMID_1206_ENVELOPE
C204: 330n / U906 bypass; C204_ILIM_RC_0603_SEED
C205: 4.7u / REGN; C205_CREGN_0805_ENVELOPE
C206: 10u / BAT; C206_CBAT_0805_ENVELOPE
C207: 22u / CSYS1; C207_CSYS_0805_ENVELOPE
C208: 22u / CSYS2; C208_CSYS_0805_ENVELOPE
C209: 1u; C_0603_1608Metric
C301: SE-5R5-D105VYH3C; KAMCAP_SE5R5_D105VYH3C
C302: 100n / RTC VDD; C_0402_1005Metric
C303: 1u / BQ BAT; C_0402_1005Metric
C304: 2.2u / BQ VDD; C_0402_1005Metric
C401: 22u / VIN; C_0603_POWER_SEED
C402, C403: 22u / VOUT; C_0603_POWER_SEED
C501: 22u / ESP32; C_0805_2012Metric
C502: 100n / ESP32; C_0402_1005Metric
C503: 100n / VDD_IO; C_0402_1005Metric
C504: 100n / VDD; C_0402_1005Metric
C505: 100n / AUDIO_VDD; C_0402_1005Metric
C506: 10u / AUDIO_VDD; C_0603_1608Metric
C507: 1u / U405 VIN; C_0603_1608Metric
C508: 1u / U402 VIN; C_0603_1608Metric
C509: 1u / U403 VIN; C_0603_1608Metric
C510: 1u / CHIP_PU; C_0603_1608Metric
C511: 1u / U404 VIN; C_0603_1608Metric
C512: 100n / SD VDD; C_0402_1005Metric
C513: 10u / SD VDD; C_0603_1608Metric
C514, C515: DNP / USB tuning; C_0402_1005Metric
C516: 1u / U403 VOUT; C_0603_1608Metric
C601: 100n / U601 VCC; C_0402_1005Metric
C903: 1u / CW2217 VCELL; C_0603_1608Metric
C920: 4.7uF 16V X7R / FL_CIN; C_0805_2012Metric
C921: 1uF 10V X7R / FL_VIN; C_0402_1005Metric
C922: 1uF 10V X7R / FL_VDC; C_0402_1005Metric
C923: 4.7uF 50V X7R / FL_COUT; C_1206_3216Metric
D201: LRC8804FDT1G; LRC8804F_DFN2510
D202: SGM05HU1ALXUGY2G/TR; SGM05HU1AL_UTDFN_1006_2BL
D905: B5819W SL / FL_RECT; D_SOD-123
H801, H802, H803, H804: M1.2 clearance / NPTH 1.6; MountingHole_M1.2_1.6mm
J201: U20405-01 USB2.0; MUP_U20405_01_R4
J301: HC-HY-2AWT; HCTL_HC_HY_2AWT
J302: HC-1.0-3PWT NTC; HCTL_HC10_3PWT
J501: TF-122-CCP9 / microSD; XUNPU_TF_122_CCP9
J502: HC-1.0-2PWT BTL; HCTL_HC10_2PWT
J503: TC2030-IDC-NL / DEBUG; Tag-Connect_TC2030-IDC-NL_2x03_P1.27mm_Vertical
J601: HC-PBB40C-60DS-0.4V-1.5-02; HCTL_PBB40C_60DS_04V_15
J803, J804: X05A10H06G; XKB_X05A10H06G_A2
L401: 0.47uH / SGM62125; Sunlord_MWSA0402_R47
L402: 1uH / SGM41513 buck; Sunlord_MWSA0402_1R0
L905: 10uH / FL_BOOST; L_Sunlord_SWPA252012S
Q907, Q908: NX3008NBK,215-JSM; JSM_NX3008NBK_SOT23
R201: 5.6k / PSEL low leg; R201_ILIM_0603_SEED
R204: 1.2k / REGN to PSEL; R204_ILIM_RC_0603_SEED
R206, R207: 5.1k ±5% / USB-C Rd; R_0402_1005Metric
R301: 1M / SCL PD DNP; R_0402_1005Metric
R302: 1M / SDA PD DNP; R_0402_1005Metric
R305: 100k / IRQ PU DNP; R_0402_1005Metric
R306: 10m / CW2217 SHUNT; R_1206_3216Metric
R501: 100k / IMU_INT1; R_0402_1005Metric
R502: 100k / EXP_INT_PU; R_0402_1005Metric
R507: 100k / AUDIO_EN_PD; R_0402_1005Metric
R508: 0R / MB6 AUDIO; R_0805_2012Metric
R509: 0R / MB2 3V3_AON; R_0805_2012Metric
R510: 10k / CHIP_PU; R_0402_1005Metric
R511: 10k / GPIO0; R_0402_1005Metric
R512: 10k / GPIO3; R_0402_1005Metric
R513: 10k / GPIO46; R_0402_1005Metric
R514: 0R / MB3 SD; R_0805_2012Metric
R515: 0R / MB4 TOUCH; R_0805_2012Metric
R516: 0R / MB5 EPD; R_0805_2012Metric
R517, R518, R519, R520, R521, R522: 0R / SD series; R_0603_1608Metric
R523, R524, R525, R526, R527: 10k / SD pull-up; R_0402_1005Metric
R528: 10k; R_0402_1005Metric
R529, R530: 22; R_0402_1005Metric
R600: 10k 1% / PG_PU; R_0402_1005Metric
R601: 100k / FL_HWEN_PD; R_0402_1005Metric
R604: 100k / SD_EN_PD; R_0402_1005Metric
R605: 100k / TOUCH_EN_PD; R_0402_1005Metric
R606: 100k / EPD_EN_PD; R_0402_1005Metric
R607: 100k / CHG_REQUEST_PD; R_0402_1005Metric
R608: 100k / FUEL_PU; R_0402_1005Metric
R609: 100k / BQ_INT_PU; R_0402_1005Metric
R610: 100k / BQ_STAT_PU; R_0402_1005Metric
R611: 100k / KEY_FN_PU; R_0402_1005Metric
R612: 100k / SD_CD_PU; R_0402_1005Metric
R613: 2.2k / I2C_SCL_PU A; R_0402_1005Metric
R614: 2.2k / I2C_SDA_PU A; R_0402_1005Metric
R615: 5.23k; R_0603_1608Metric
R616: 30.1k; R_0603_1608Metric
R903: 100R / CW2217 VDD; R_0603_1608Metric
R904: 100R / CW2217 VCELL; R_0603_1608Metric
R910: 10k / TOUCH_INT_PU; R_0402_1005Metric
R911: 10k / TOUCH_RST_PU; R_0402_1005Metric
R920: 10R 1% / FL_VIN_RC; R_0603_1608Metric
R922: 100k / FL_PWM_PD; R_0402_1005Metric
R930: 100k / nCE default OFF; R_0402_1005Metric
R931: 1.2k / hardware permit; R204_ILIM_RC_0603_SEED
R932, R933: 10k / gate default LOW; R_0402_1005Metric
SW201, SW202: TS-1186E-B-B; XKB_TS1186E_BB_A1
TP1: VBUS_USB; TestPoint_Pad_D1.5mm
TP2: VSYS_RAW; TestPoint_Pad_D1.5mm
TP3: 3V3_AON; TestPoint_Pad_D1.5mm
TP4: BAT+; TestPoint_Pad_D1.5mm
TP5: 3V3_SD; TestPoint_Pad_D1.5mm
TP6: 3V3_TOUCH; TestPoint_Pad_D1.5mm
TP7: 3V3_EPD_LOGIC; TestPoint_Pad_D1.5mm
TP8: VSYS_AUDIO; TestPoint_Pad_D1.5mm
TP11: I2C_SCL; TestPoint_Pad_D1.5mm
TP12: I2C_SDA; TestPoint_Pad_D1.5mm
TP13: EXP_INT; TestPoint_Pad_D1.5mm
TP14: EXP_INT / SHARED_IRQ; TestPoint_Pad_D1.5mm
TP16: PG_3V3_MAIN; TestPoint_Pad_D1.5mm
TP18: CHIP_PU; TestPoint_Pad_D1.5mm
TP19: HW_ARM / FORCE LOW; TestPoint_Pad_D1.5mm
TPG1, TPG2, TPG3, TPG4, TPG5, TPG6: GND; TestPoint_Pad_D1.5mm
U302: SD3078; WAVE_SD3078_SOP8_208mil
U402, U403, U404, U405: SGM2578SDYG/TR; SGM2578SD_WLCSP_09x09_P05
U501: ESP32-S3-WROOM-1U-N16R8; ESP32-S3-WROOM-1U
U503: QMI8658A; LGA-14_3x2.5mm_P0.5mm_LayoutBorder3x4y
U601: XL9535; TCA9535PWR_PW0024A
U901: SGM41513YTQF24G/TR; SGM41513_YTQF24_4x4_P0.5_EP2.7
U902: SGM62125AXG/TR; SGM62125_XG_WLCSP15_1.46x2.3_P0.4
U903: CW2217BAAD; CW2217BAAD_DFN12_L4.0_W2.5_P0.4_EP
U904: NS4168; NS4168_ESOP8_EP_L4.9_W3.9_P1.27
U905: SGM37601YTRL20G/TR; SGM37601_TQFN20_3P5x3P5_EP2P05
U906: SGM809B-TXN3LG/TR; SGM809B_SOT23_TX00031

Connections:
3V3_AON: C204.1, C302.1, C501.1, C502.1, C503.1, C504.1, C508.1, C509.1, C511.1, C601.1, J503.2, R305.1, R502.2, R509.2, R510.1, R511.1, R528.1, R600.2, R608.2, R609.2, R610.2, R611.2, R612.2, R613.2, R614.2, TP3.1, U302.3 (VDD), U402.A2, U403.A2, U404.A2, U501.2, U503.1, U503.5, U503.8, U503.12, U601.24, U906.3 (VCC)
3V3_AON_SRC: C402.1, C403.1, R509.1, U902.E2, U902.E3
3V3_EPD_LOGIC: J601.35, J601.36, R516.2, TP7.1
3V3_EPD_LOGIC_SW: R516.1, U404.A1
3V3_SD: C512.1, C513.1, J501.4, R514.2, R523.2, R524.2, R525.2, R526.2, R527.2, TP5.1
3V3_SD_SW: R514.1, U402.A1
3V3_TOUCH: J803.2, R515.2, R910.1, R911.1, TP6.1
3V3_TOUCH_SW: C516.1, R515.1, U403.A1
BAT_CONN_P: J301.1, R306.1, R904.1, TP4.1, U903.8
BAT_PACKP: C206.1, C303.1, R306.2, R903.1, U901.13, U901.14, U903.7
BQ_INT: R609.1, U601.10, U901.7
BQ_PG: R600.1, U601.13, U901.3
BQ_QON: SW202.1, U901.12
BQ_STAT: R610.1, U601.11, U901.4
BQ_TS: J302.1, R615.2, R616.1, U901.11, U903.9
CHG_REQUEST: Q907.1 (G), R607.1, R932.1, U601.9
CHG_RETURN: Q907.3 (S), Q908.2 (D)
CHG_nCE: Q907.2 (D), R930.1, U901.9
CHIP_PU: C510.1, J503.1, R510.2, TP18.1, U501.3
EN_3V3_EPD_LOGIC: R606.1, U404.B2, U601.6
EN_3V3_SD: R604.1, U402.B2, U601.4
EN_3V3_TOUCH: R605.1, U403.B2, U601.5
EN_VSYS_AUDIO: R507.1, U405.B2, U601.7
EPD_D0: J601.1, U501.31
EPD_D1: J601.3, U501.32
EPD_D2: J601.5, U501.33
EPD_D3: J601.7, U501.34
EPD_D4: J601.9, U501.35
EPD_D5: J601.11, U501.24
EPD_LE: R512.1, U501.15
EPD_OE: R513.1, U501.16
EXP_INT: R305.2, R502.1, TP13.1, TP14.1, U302.7 (INT), U501.4, U601.1
FL_C_N: J804.5, U905.11
FL_HWEN: Q908.1 (G), R601.1, R931.2, R933.1, TP19.1, U905.19
FL_PWM: R922.1, U601.19, U905.20
FL_SW: D905.2, L905.2, U905.16, U905.17
FL_VDC: C922.1, U905.3
FL_VIN: C921.1, R920.2, U905.18
FL_VOUT: C923.1, D905.1, J804.2, J804.6, U905.14
FL_W_N: J804.1, U905.12
FUEL_GPOUT: R608.1, U601.8, U903.1
FUEL_VCELL: C903.1, R904.2, U903.4
FUEL_VDD: C304.1, R903.2, U903.3
GND: C202.2, C203.2, C204.2, C205.2, C206.2, C207.2, C208.2, C209.2, C301.2 (-), C302.2, C303.2, C304.2, C401.2, C402.2, C403.2, C501.2, C502.2, C503.2, C504.2, C505.2, C506.2, C507.2, C508.2, C509.2, C510.2, C511.2, C512.2, C513.2, C514.2, C515.2, C516.2, C601.2, C903.2, C920.2, C921.2, C922.2, C923.2, D201.3, D201.8, D202.2, J201.A1, J201.A12, J201.B1, J201.B12, J201.SH, J301.2, J302.2, J501.6, J501.10, J501.SH, J503.4, J601.2, J601.4, J601.6, J601.8, J601.10, J601.12, J601.14, J601.16, J601.18, J601.20, J601.22, J601.24, J601.26, J601.28, J601.30, J601.32, J601.34, J601.55, J601.56, J601.57, J601.58, J601.59, J601.60, J803.1, Q908.3 (S), R201.2, R206.1, R207.1, R301.2, R302.2, R501.2, R507.2, R512.2, R513.2, R601.2, R604.2, R605.2, R606.2, R607.2, R616.2, R922.2, R932.2, R933.2, SW201.2, SW202.2, TPG1.1, TPG2.1, TPG3.1, TPG4.1, TPG5.1, TPG6.1, U302.6 (GND), U402.B1, U403.B1, U404.B1, U405.B1, U501.1, U501.40, U501.41, U503.2, U503.3, U503.6, U503.7, U601.2, U601.3, U601.12, U601.21, U901.17, U901.18, U901.25, U902.C1, U902.C2, U902.C3, U903.6, U903.13, U904.7, U904.9, U905.5, U905.9, U905.15, U905.21, U906.1 (GND)
GPIO0: J503.6, R511.2, U501.27
HW_ARM_GPIO: R931.1, U501.38
I2C_SCL: J803.6, R301.1, R613.1, TP11.1, U302.1 (SCL), U501.22, U503.13, U601.22, U901.5, U902.D1, U903.11, U905.2
I2C_SDA: J803.5, R302.1, R614.1, TP12.1, U302.8 (SDA), U501.8, U503.14, U601.23, U901.6, U902.E1, U903.10, U905.1
I2S_BCLK: U501.19, U904.3
I2S_DIN: U501.21, U904.4
I2S_LRCLK: U501.20, U904.2
IMU_INT1: R501.1, U503.4, U601.15
KEY_FN: R611.1, U601.14
KEY_POWER_MCU: R528.2, SW201.1, U501.39
PG_3V3_MAIN: TP16.1, U601.17, U906.2 (nRESET)
RTC_VBACKUP: C301.1 (+), U302.5 (VBAT)
SDMMC_CLK: R517.1, U501.5
SDMMC_CLK_CARD: J501.5, R517.2
SDMMC_CMD: R518.1, U501.6
SDMMC_CMD_CARD: J501.3, R518.2, R523.1
SDMMC_D0: R519.1, U501.7
SDMMC_D0_CARD: J501.7, R519.2, R524.1
SDMMC_D1: R520.1, U501.12
SDMMC_D1_CARD: J501.8, R520.2, R525.1
SDMMC_D2: R521.1, U501.17
SDMMC_D2_CARD: J501.1, R521.2, R526.1
SDMMC_D3: R522.1, U501.18
SDMMC_D3_CARD: J501.2, R522.2, R527.1
SD_CD: J501.9, R612.1, U601.16
SGM41513_BTST: C201.1, U901.21
SGM41513_PMID: C203.1, U901.23
SGM41513_PSEL: R201.1, R204.1, U901.2
SGM41513_REGN: C205.1, R204.2, R615.1, R930.2, U901.22
SGM41513_SW: C201.2, L402.1, U901.19, U901.20
SGM62125_SW1: L401.1, U902.B2, U902.B3
SGM62125_SW2: L401.2, U902.D2, U902.D3
SPK_N: J502.2, U904.5
SPK_P: J502.1, U904.8
TOUCH_INT: J803.4, R910.2
TOUCH_RST: J803.3, R911.2, U601.20
UART0_RX: J503.3, U501.36
UART0_TX: J503.5, U501.37
USB_CC1: D201.4, J201.A5, R206.2
USB_CC2: D201.5, J201.B5, R207.2
USB_DM: D201.2, J201.A7, J201.B7, R530.1
USB_DM_MCU: C515.1, R530.2, U501.13
USB_DP: D201.1, J201.A6, J201.B6, R529.1
USB_DP_MCU: C514.1, R529.2, U501.14
VBUS_USB: C202.1, C209.1, D202.1, J201.A4, J201.A9, J201.B4, J201.B9, TP1.1, U901.1, U901.24
VSYS_AUDIO: C505.1, C506.1, R508.2, TP8.1, U904.1, U904.6
VSYS_AUDIO_SW: R508.1, U405.A1
VSYS_FL_IN: C920.1, L905.1, R920.1
VSYS_RAW: C207.1, C208.1, C401.1, C507.1, L402.2, TP2.1, U405.A2, U901.15, U901.16, U902.A1, U902.A2, U902.A3, U902.B1

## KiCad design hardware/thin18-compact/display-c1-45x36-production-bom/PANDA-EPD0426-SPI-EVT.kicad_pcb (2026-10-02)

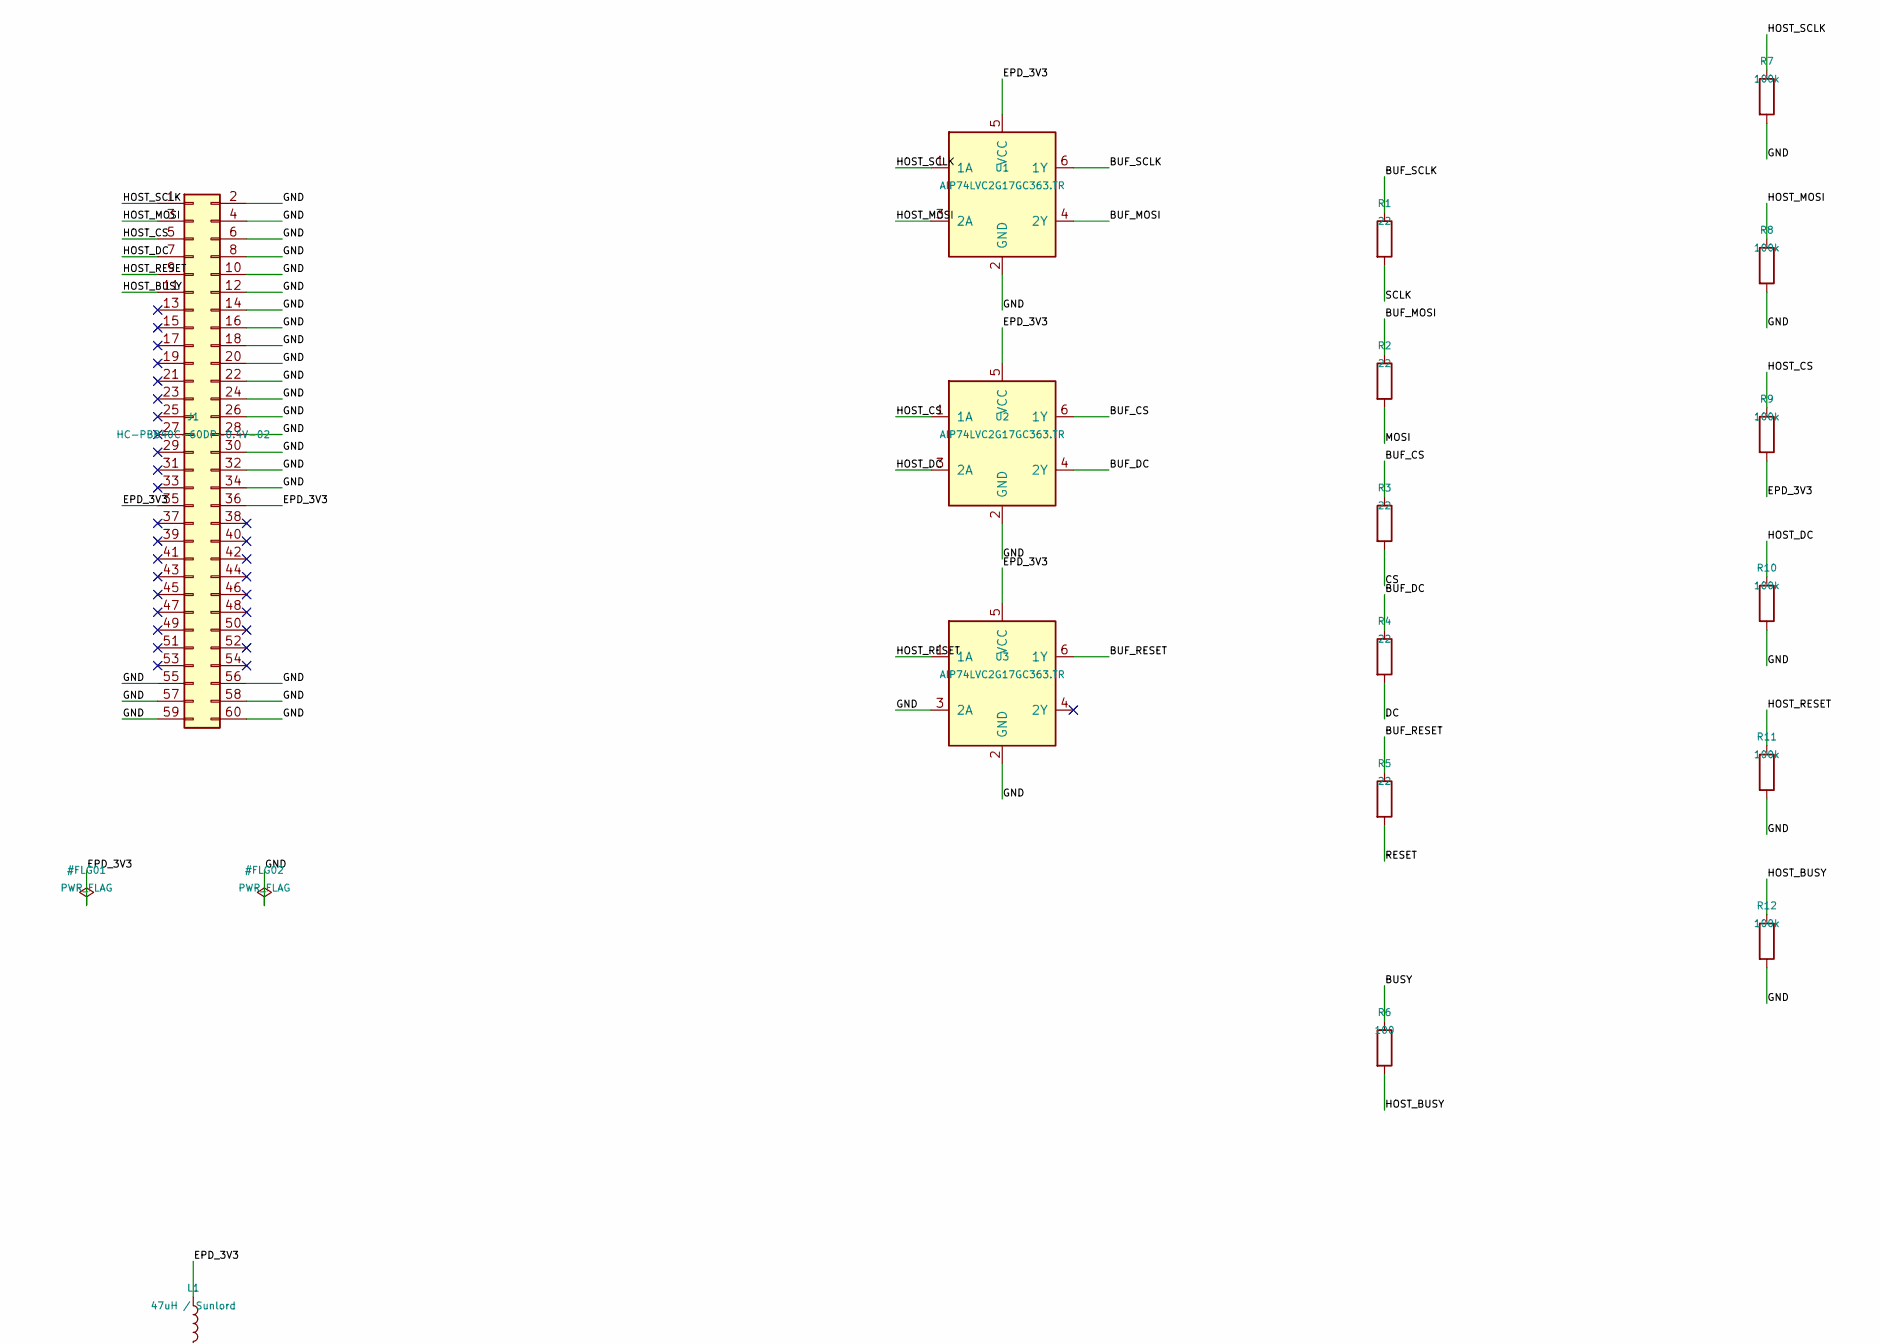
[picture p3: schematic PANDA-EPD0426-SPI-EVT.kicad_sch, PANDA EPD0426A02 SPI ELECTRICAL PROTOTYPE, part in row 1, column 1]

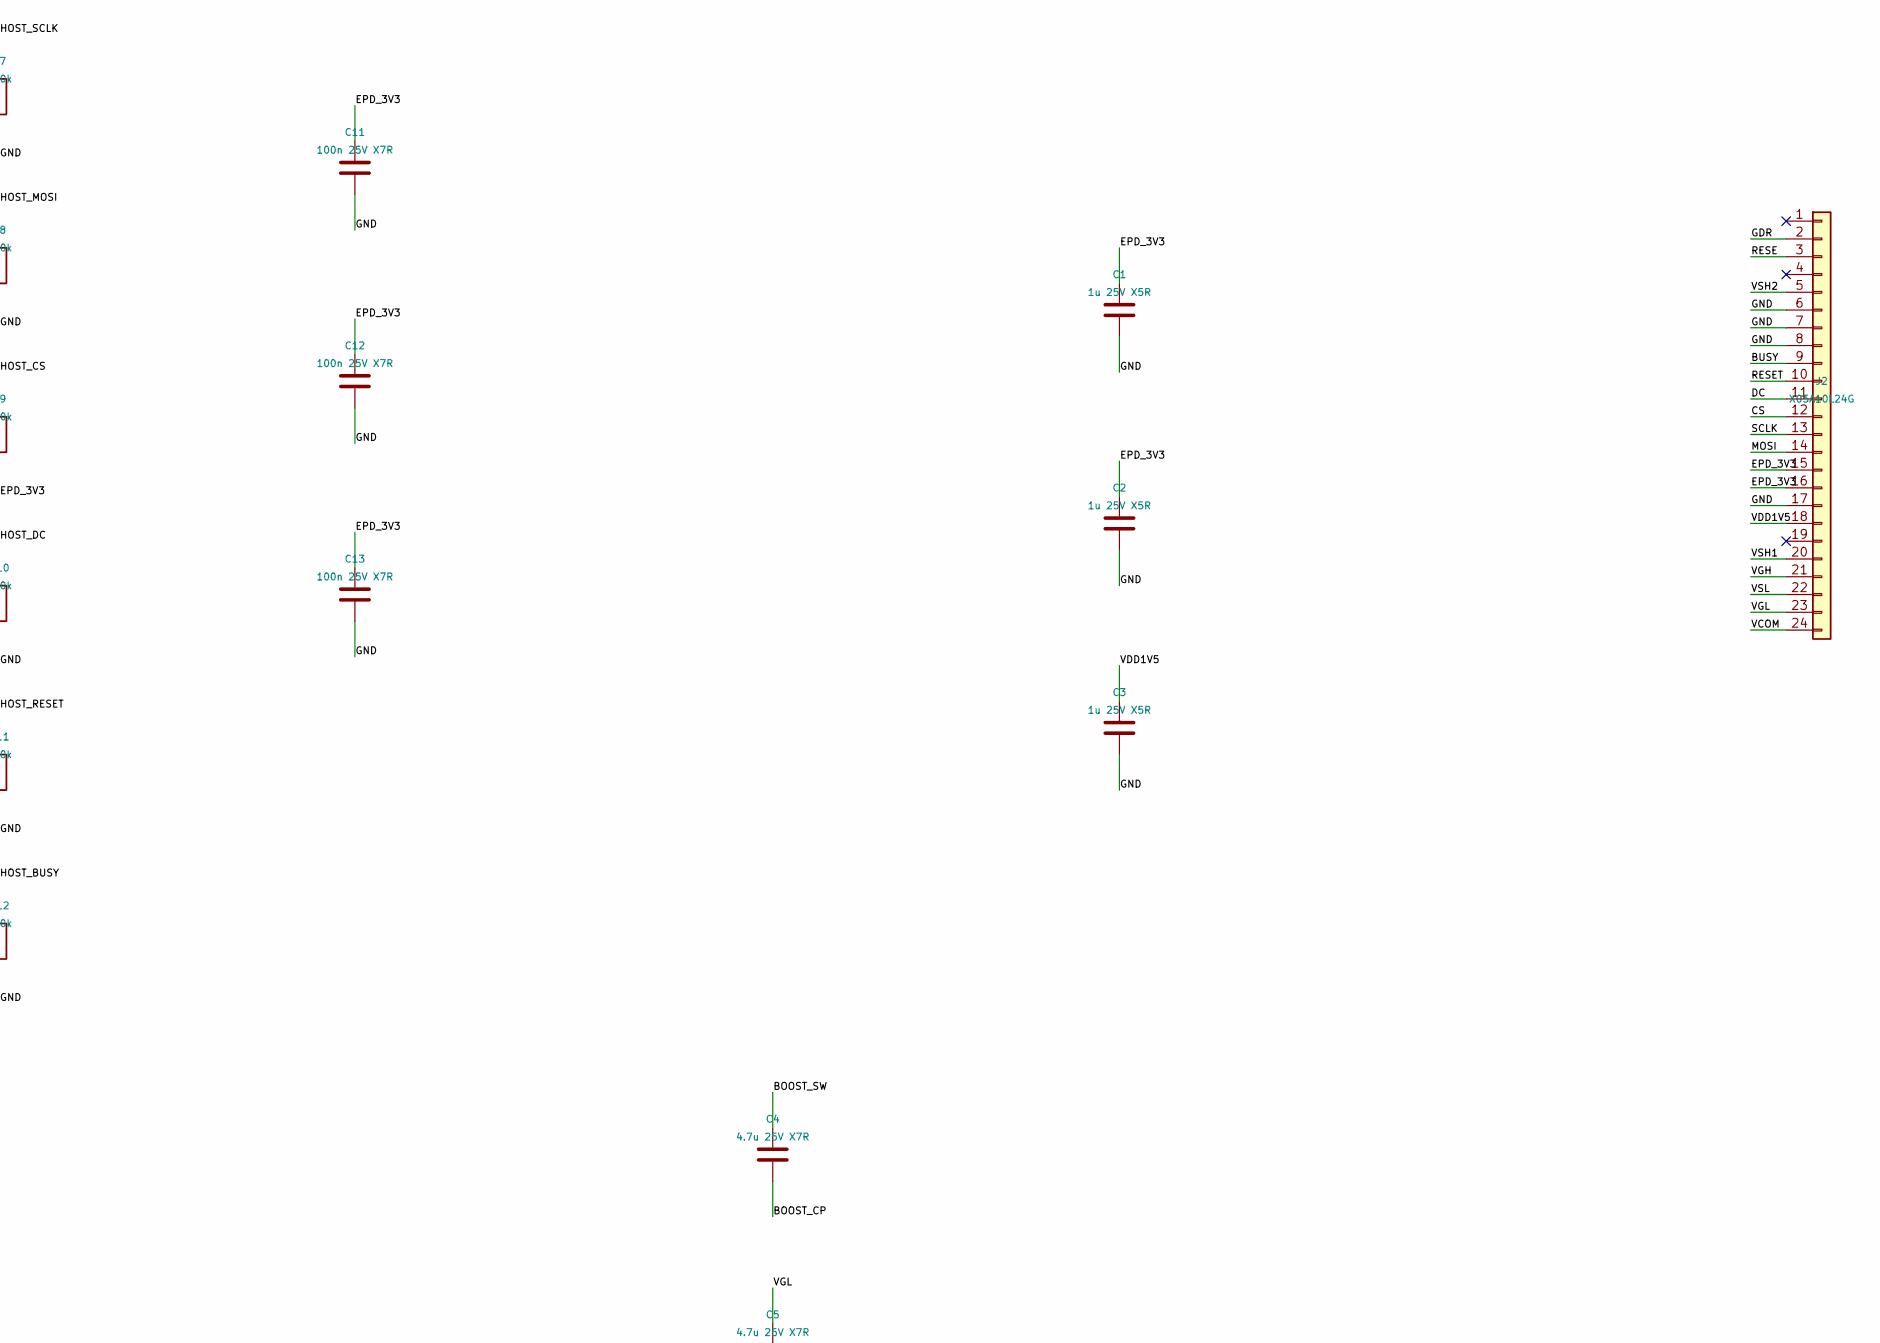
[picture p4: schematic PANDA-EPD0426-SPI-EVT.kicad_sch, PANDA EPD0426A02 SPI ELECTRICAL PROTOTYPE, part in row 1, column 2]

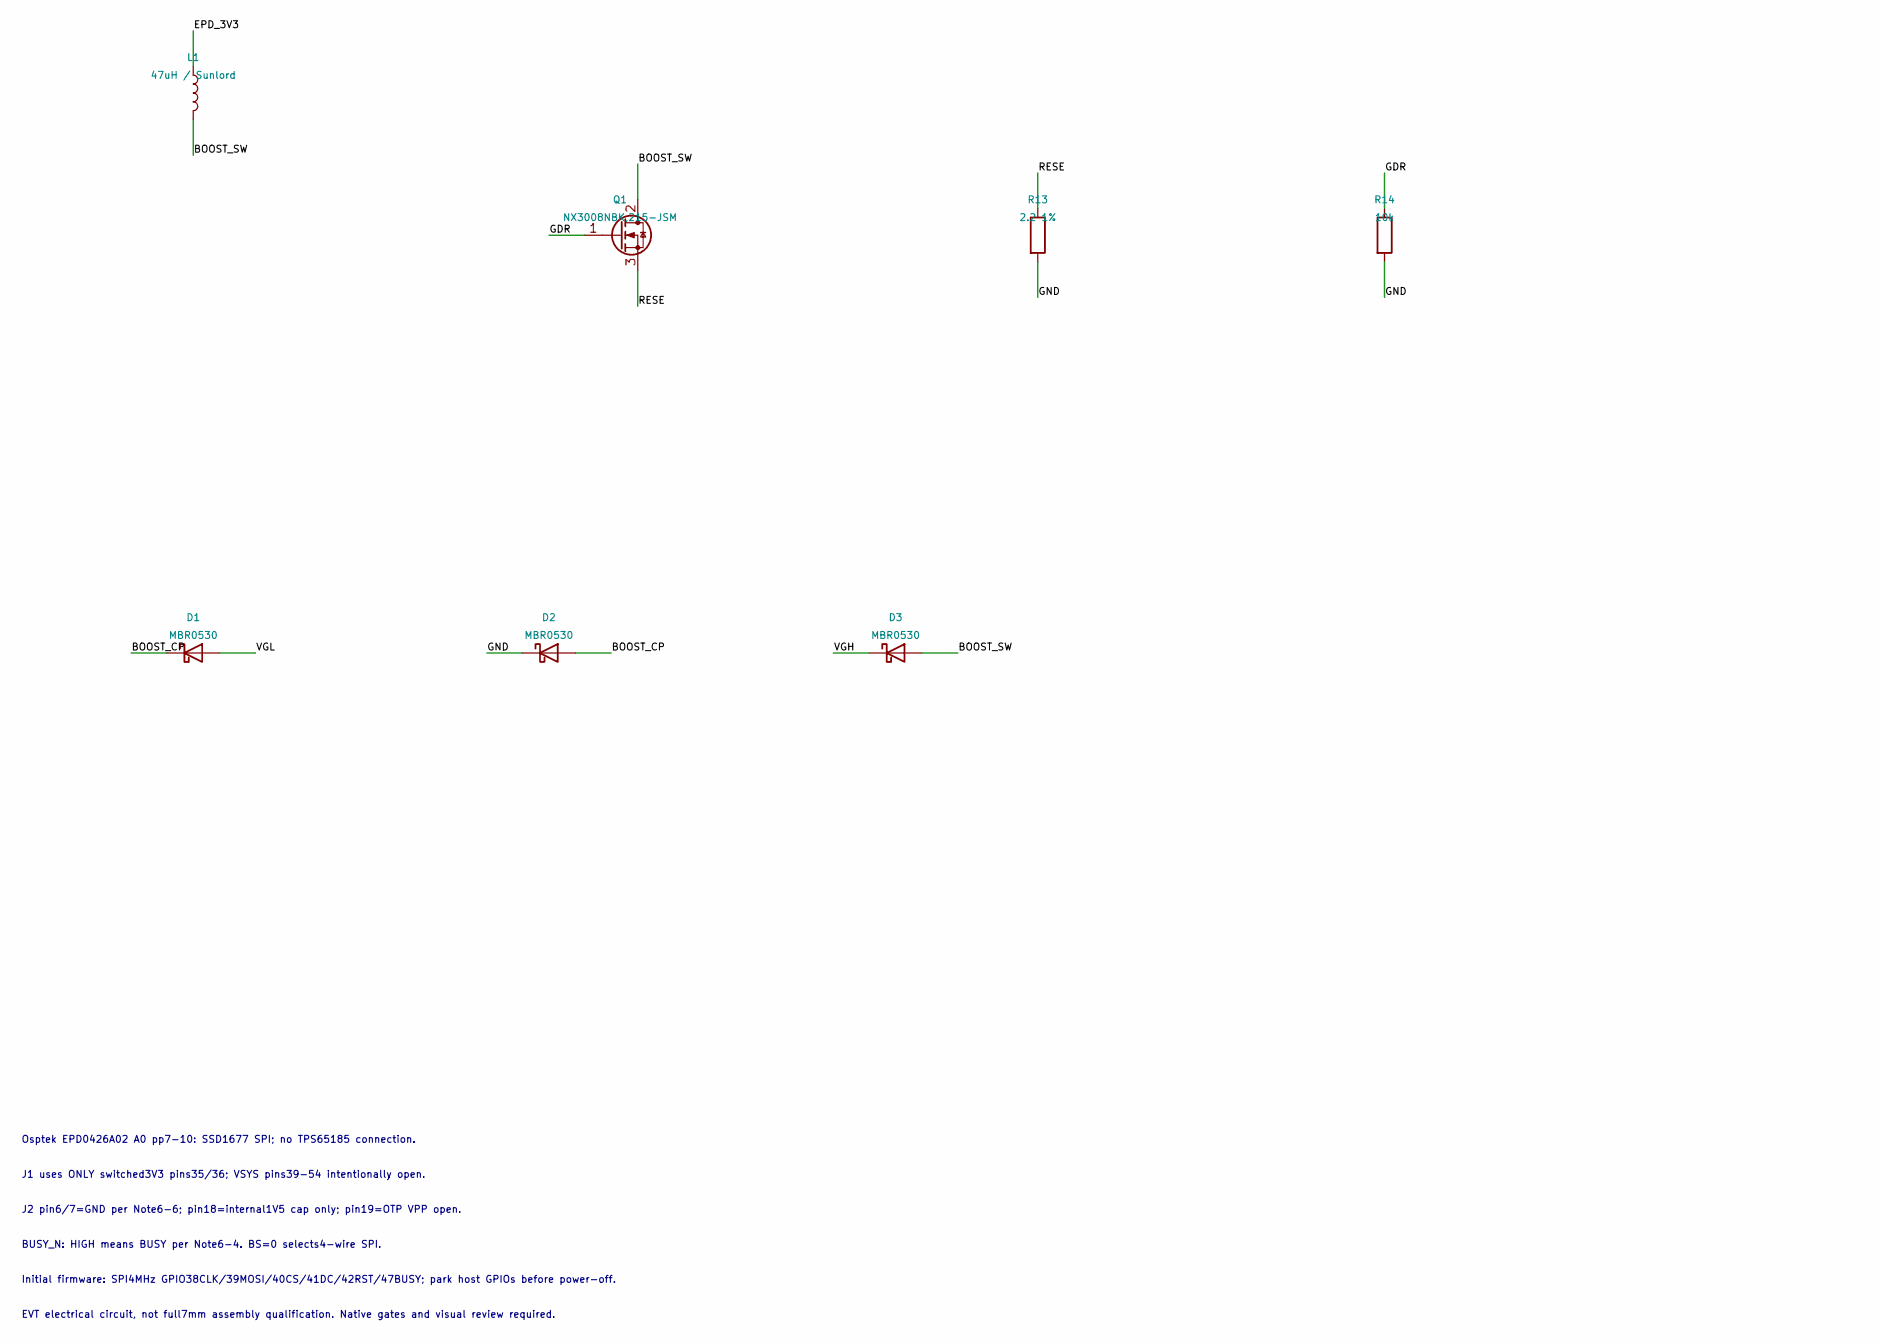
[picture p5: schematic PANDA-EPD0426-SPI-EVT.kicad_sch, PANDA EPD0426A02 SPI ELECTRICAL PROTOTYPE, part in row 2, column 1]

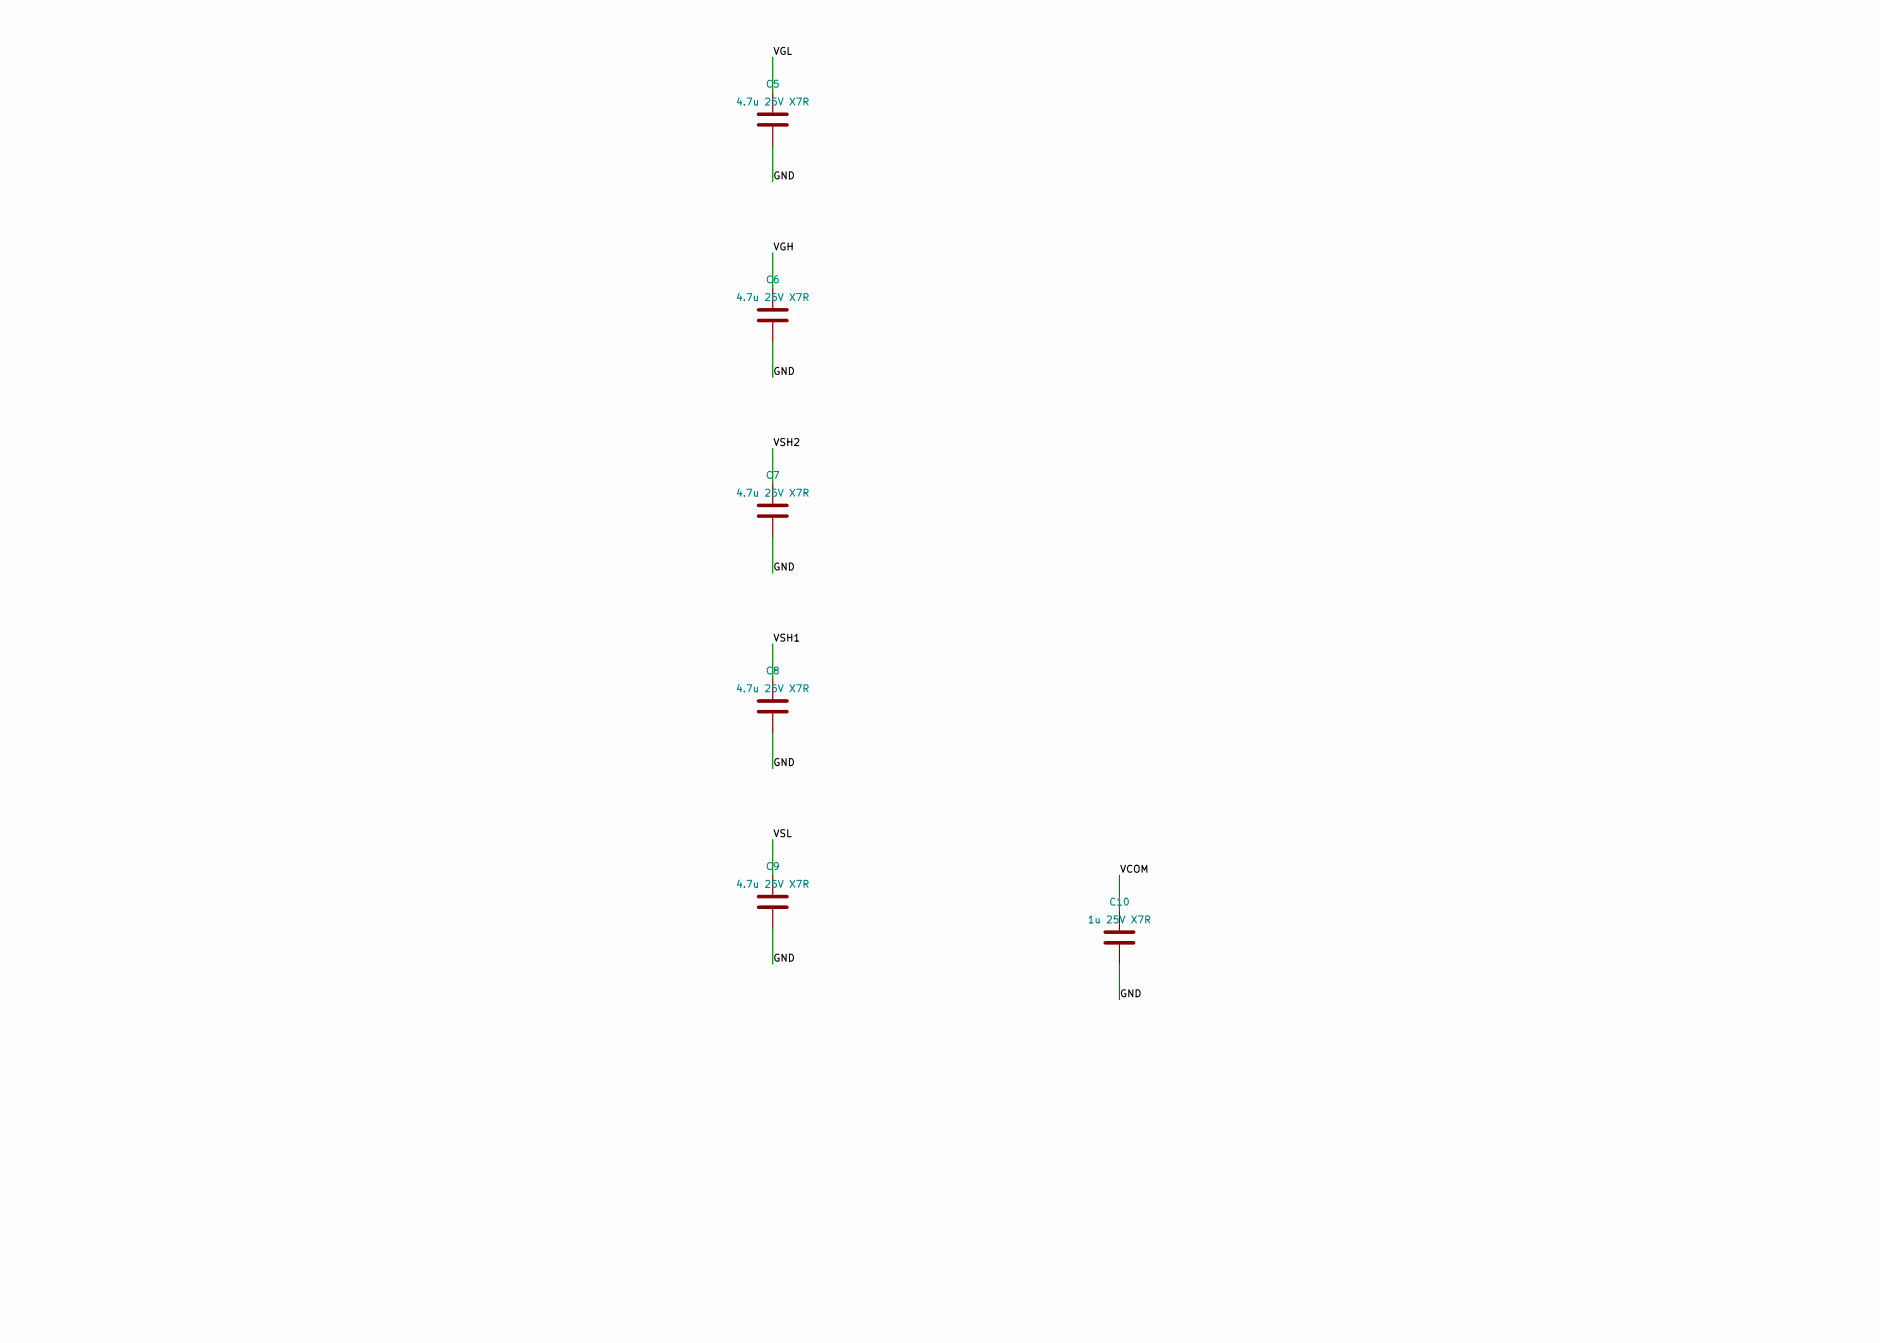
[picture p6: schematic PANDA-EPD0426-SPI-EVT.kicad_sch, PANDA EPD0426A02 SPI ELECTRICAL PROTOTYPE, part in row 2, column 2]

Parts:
C1, C2, C3: 1u 25V X5R; C_0603_1608Metric; MPN 0603B105K250NT; LCSC C59302
C4, C5, C6, C7, C8, C9: 4.7u 25V X7R; C_0805_2012Metric; MPN 0805B475K250NT; LCSC C37818
C10: 1u 25V X7R; C_0805_2012Metric; MPN 0805B105K250NT; LCSC C89190
C11, C12, C13: 100n 25V X7R; C_0603_1608Metric; MPN 0603B104K250NT; LCSC C694249
D1, D2, D3: MBR0530; MBR0530_JSCJ_SOD123; MPN MBR0530; LCSC C77336
J1: HC-PBB40C-60DP-0.4V-02; HCTL_PBB40C_60DP_04V; MPN HC-PBB40C-60DP-0.4V-02; LCSC C19089235
J2: X05A10L24G; XKB_X05A10L24G; MPN X05A10L24G; LCSC C2880917
L1: 47uH / Sunlord; Sunlord_SWPA3012_47u; MPN SWPA3012S470MT; LCSC C83420
Q1: NX3008NBK,215-JSM; JSM_NX3008NBK_SOT23; MPN NX3008NBK,215-JSM; LCSC C53113911
R1, R2, R3, R4, R5: 22; R_0402_1005Metric; MPN RC-02K22R0FT; LCSC C324769
R6: 100; R_0402_1005Metric; MPN RC-02K1000FT; LCSC C140217
R7, R8, R9, R10, R11, R12: 100k; R_0402_1005Metric; MPN RC-02K1003FT; LCSC C140219
R13: 2.2 1%; R_0603_1608Metric; MPN RS-03L2R20FT; LCSC C322118
R14: 10k; R_0402_1005Metric; MPN RC-02K1002FT; LCSC C140215
U1, U2, U3: AIP74LVC2G17GC363.TR; SOT-363_SC-70-6; MPN AIP74LVC2G17GC363.TR; LCSC C3294722

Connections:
/BOOST_CP: C4.2, D1.1 (K), D2.2 (A)
/BOOST_SW: C4.1, D3.2 (A), L1.2, Q1.2 (D)
/BUF_CS: R3.1, U2.6 (1Y)
/BUF_DC: R4.1, U2.4 (2Y)
/BUF_MOSI: R2.1, U1.4 (2Y)
/BUF_RESET: R5.1, U3.6 (1Y)
/BUF_SCLK: R1.1, U1.6 (1Y)
/BUSY: J2.9, R6.1
/CS: J2.12, R3.2
/DC: J2.11, R4.2
/EPD_3V3: C1.1, C2.1, C11.1, C12.1, C13.1, J1.35, J1.36, J2.15, J2.16, L1.1, R9.2, U1.5 (VCC), U2.5 (VCC), U3.5 (VCC)
/GDR: J2.2, Q1.1 (G), R14.1
/GND: C1.2, C2.2, C3.2, C5.2, C6.2, C7.2, C8.2, C9.2, C10.2, C11.2, C12.2, C13.2, D2.1 (K), J1.2, J1.4, J1.6, J1.8, J1.10, J1.12, J1.14, J1.16, J1.18, J1.20, J1.22, J1.24, J1.26, J1.28, J1.30, J1.32, J1.34, J1.55, J1.56, J1.57, J1.58, J1.59, J1.60, J2.6, J2.7, J2.8, J2.17, R7.2, R8.2, R10.2, R11.2, R12.2, R13.2, R14.2, U1.2 (GND), U2.2 (GND), U3.2 (GND), U3.3 (2A)
/HOST_BUSY: J1.11, R6.2, R12.1
/HOST_CS: J1.5, R9.1, U2.1 (1A)
/HOST_DC: J1.7, R10.1, U2.3 (2A)
/HOST_MOSI: J1.3, R8.1, U1.3 (2A)
/HOST_RESET: J1.9, R11.1, U3.1 (1A)
/HOST_SCLK: J1.1, R7.1, U1.1 (1A)
/MOSI: J2.14, R2.2
/RESE: J2.3, Q1.3 (S), R13.1
/RESET: J2.10, R5.2
/SCLK: J2.13, R1.2
/VCOM: C10.1, J2.24
/VDD1V5: C3.1, J2.18
/VGH: C6.1, D3.1 (K), J2.21
/VGL: C5.1, D1.2 (A), J2.23
/VSH1: C8.1, J2.20
/VSH2: C7.1, J2.5
/VSL: C9.1, J2.22

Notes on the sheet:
Osptek EPD0426A02 A0 pp7-10: SSD1677 SPI; no TPS65185 connection.
J1 uses ONLY switched3V3 pins35/36; VSYS pins39-54 intentionally open.
J2 pin6/7=GND per Note6-6; pin18=internal1V5 cap only; pin19=OTP VPP open.
BUSY_N: HIGH means BUSY per Note6-4. BS=0 selects4-wire SPI.
Initial firmware: SPI4MHz GPIO38CLK/39MOSI/40CS/41DC/42RST/47BUSY; park host GPIOs before power-off.
EVT electrical circuit, not full7mm assembly qualification. Native gates and visual review required.

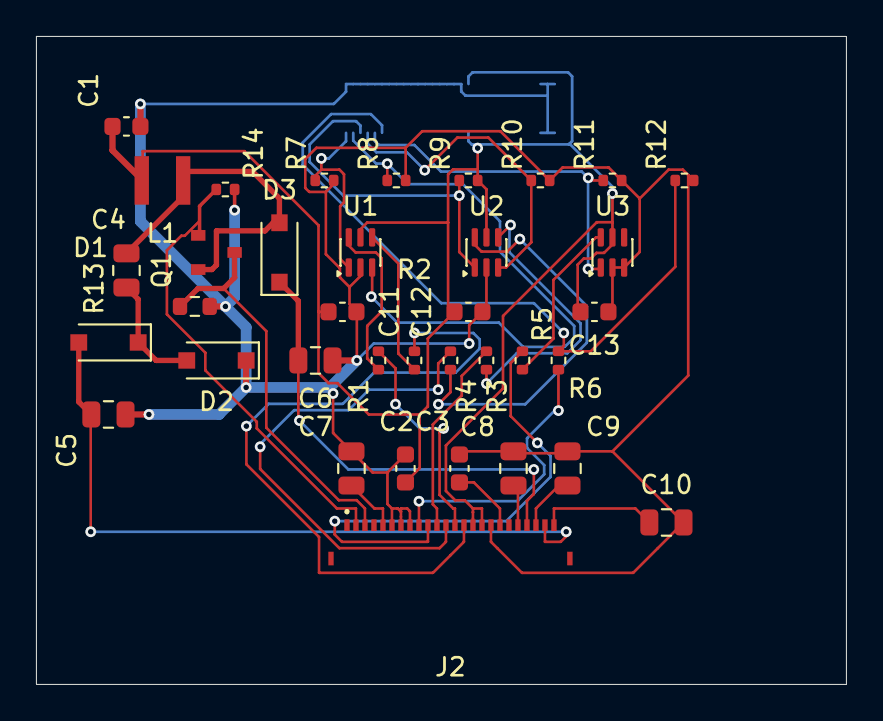
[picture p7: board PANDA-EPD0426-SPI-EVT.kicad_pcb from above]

Board: 2 copper layers, 45.0 x 36.0 mm, 37 parts (1 on the bottom side), 30 nets.

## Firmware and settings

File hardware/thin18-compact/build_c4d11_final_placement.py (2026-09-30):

#!/usr/bin/env python3
"""Freeze C4D-10B as the final 96x68 placement checkpoint for routing.

This stage changes no reference, pose, net or footprint geometry. It locks every
footprint, re-runs native KiCad checks, exports the placement CSV and records the
mechanical invariants required before DSN routing.
"""
from pathlib import Path
import hashlib
import json
import re
import shutil
import subprocess
import sys
import xml.etree.ElementTree as ET

ROOT = Path(__file__).resolve().parent
SRC = ROOT / "c4d10b-96x68-frontlight"
DST = ROOT / "c4d11-96x68-final-placement"
REL = Path("eda/core/PANDA-STD-CORE-EVT/PANDA-THIN16")
STEM = "PANDA-STD-CORE-EVT-quilter-j501-merged"
PCB = DST / REL / f"{STEM}.kicad_pcb"
SCH = DST / REL / f"{STEM}.kicad_sch"
KICAD = "/Applications/KiCad/KiCad.app/Contents/MacOS/kicad-cli"
KICAD_PY = "/Applications/KiCad/KiCad.app/Contents/Frameworks/Python.framework/Versions/Current/bin/python3"


def balanced(text: str, start: int) -> int:
    depth = 0
    quote = False
    escape = False
    for index in range(start, len(text)):
        char = text[index]
        if quote:
            if escape:
                escape = False
            elif char == "\\":
                escape = True
            elif char == '"':
                quote = False
        else:
            if char == '"':
                quote = True
            elif char == "(":
                depth += 1
            elif char == ")":
                depth -= 1
                if depth == 0:
                    return index + 1
    raise RuntimeError("unterminated s-expression")


def semantic_netlist(path: Path):
    root = ET.parse(path).getroot()
    refs = sorted(component.get("ref") for component in root.findall("components/comp"))
    tuples = sorted(
        (node.get("ref"), node.get("pin"), net.get("name", ""))
        for net in root.findall("nets/net")
        for node in net.findall("node")
    )
    return refs, tuples


if DST.exists():
    shutil.rmtree(DST)
shutil.copytree(SRC, DST, ignore=shutil.ignore_patterns("verification", "__pycache__", "*.pyc", "*.kicad_prl", "*.lck"))
(DST / "verification").mkdir()

# Lock each top-level footprint by preserving the exact source text and inserting
# only the native KiCad footprint lock flag where absent.
text = PCB.read_text()
position = 0
footprint_count = 0
newly_locked = []
while True:
    start = text.find("(footprint ", position)
    if start < 0:
        break
    end = balanced(text, start)
    block = text[start:end]
    # Skip cached/non-board forms if any; board footprint blocks always have a layer.
    layer_position = block.find("(layer ")
    if layer_position < 0:
        position = end
        continue
    footprint_count += 1
    ref_match = re.search(r'\(property "Reference" "([^"]+)"', block)
    ref = ref_match.group(1) if ref_match else f"#{footprint_count}"
    header = block[:layer_position]
    if "(locked yes)" not in header:
        block = block[:layer_position] + "(locked yes) " + block[layer_position:]
        text = text[:start] + block + text[end:]
        end = start + len(block)
        newly_locked.append(ref)
    position = end
PCB.write_text(text)

# Native checks and machine-readable placement export.
subprocess.run(
    [KICAD, "sch", "erc", "--format", "json", "--severity-all", "--output", str(DST / "verification/erc.json"), str(SCH)],
    check=True,
)
subprocess.run(
    [KICAD, "sch", "export", "netlist", "--format", "kicadxml", "--output", str(DST / "verification/netlist.xml"), str(SCH)],
    check=True,
)
subprocess.run(
    [KICAD, "pcb", "drc", "--format", "json", "--severity-all", "--schematic-parity", "--output", str(DST / "verification/drc.json"), str(PCB)],
    check=True,
)
subprocess.run(
    [KICAD, "pcb", "export", "pos", "--format", "csv", "--units", "mm", "--side", "both", "--output", str(DST / "verification/placement.csv"), str(PCB)],
    check=True,
)

# Public evidence must not expose the local checkout path.
netlist_path = DST / "verification/netlist.xml"
netlist_text = netlist_path.read_text()
netlist_text = re.sub(
    r"<source>.*?</source>",
    "<source>eda/core/PANDA-STD-CORE-EVT/PANDA-THIN16/PANDA-STD-CORE-EVT-quilter-j501-merged.kicad_sch</source>",
    netlist_text,
    count=1,
)
netlist_path.write_text(netlist_text)

drc = json.loads((DST / "verification/drc.json").read_text())
erc = json.loads((DST / "verification/erc.json").read_text())
counts = {
    "erc": sum(len(sheet.get("violations", [])) for sheet in erc.get("sheets", [])),
    "drc": len(drc.get("violations", [])),
    "parity": len(drc.get("schematic_parity", [])),
    "open": len(drc.get("unconnected_items", [])),
}
if counts != {"erc": 0, "drc": 0, "parity": 0, "open": 436}:
    raise SystemExit(f"unexpected native checks: {counts}")

source_refs, source_tuples = semantic_netlist(SRC / "verification/netlist.xml")
target_refs, target_tuples = semantic_netlist(netlist_path)
if source_refs != target_refs or source_tuples != target_tuples:
    raise SystemExit("placement freeze changed schematic topology")

# Inspect board geometry/poses with KiCad's native API in an isolated subprocess.
audit_script = f'''import json, pcbnew\nboard=pcbnew.LoadBoard(r"{PCB}")\nbox=board.GetBoardEdgesBoundingBox()\npositions={{}}\nfor ref in ["J201","J301","J501","J502","J802","J803","J804","U501","U905","SW201","SW202","H801","H802","H803","H804"]:\n    fp=board.FindFootprintByReference(ref)\n    if fp is not None:\n        p=fp.GetPosition()\n        positions[ref]={{"x_mm":round(pcbnew.ToMM(p.x),3),"y_mm":round(pcbnew.ToMM(p.y),3),"rotation_deg":round(fp.GetOrientationDegrees(),1),"side":board.GetLayerName(fp.GetLayer()),"locked":bool(fp.IsLocked())}}\nresult={{\n "board_bbox_mm":[round(pcbnew.ToMM(box.GetX()),3),round(pcbnew.ToMM(box.GetY()),3),round(pcbnew.ToMM(box.GetWidth()),3),round(pcbnew.ToMM(box.GetHeight()),3)],\n "copper_layers":board.GetCopperLayerCount(),\n "footprints":len(list(board.GetFootprints())),\n "locked_footprints":sum(1 for fp in board.GetFootprints() if fp.IsLocked()),\n "tracks":len(list(board.GetTracks())),\n "zones":len(list(board.Zones())),\n "positions":positions,\n}}\nprint(json.dumps(result))\n'''
completed = subprocess.run([KICAD_PY, "-c", audit_script], check=True, capture_output=True, text=True)
geometry = json.loads(completed.stdout.strip().splitlines()[-1])
if geometry["copper_layers"] != 4 or geometry["footprints"] != 189 or geometry["locked_footprints"] != 189:
    raise SystemExit(f"placement-lock invariant failed: {geometry}")
if geometry["tracks"] != 0 or geometry["zones"] != 0:
    raise SystemExit("C4D11 must remain an unrouted placement checkpoint")
# The 0.025-mm Edge.Cuts stroke expands the native 0..96 x 0..68 rectangle.
if geometry["board_bbox_mm"] != [-0.025, -0.025, 96.05, 68.065]:
    raise SystemExit(f"board boundary changed: {geometry['board_bbox_mm']}")

expected_positions = {
    "J201": (39.0, 68.0, 0.0),
    "J501": (88.8, 18.75, -90.0),
    "J802": (61.0, 52.5, 0.0),
    "J803": (6.35, 39.37, 0.0),
    "J804": (6.35, 45.5, 0.0),
    "U905": (4.0, 52.5, 0.0),
    "H801": (15.0, 2.0, 0.0),
    "H802": (81.0, 2.0, 0.0),
    "H803": (93.0, 34.0, 0.0),
    "H804": (3.0, 34.0, 0.0),
}
for ref, expected in expected_positions.items():
    actual = geometry["positions"].get(ref)
    if actual is None or (actual["x_mm"], actual["y_mm"], actual["rotation_deg"]) != expected:
        raise SystemExit(f"key placement changed for {ref}: {actual} != {expected}")

report = {
    "date": "2026-09-30",
    "kind": "C4D-11 final compact placement checkpoint",
    "source": "c4d10b-96x68-frontlight",
    "target_board_mm": [96.0, 68.0],
    "coupon_hard_max_mm": [100.0, 100.0],
    "battery_rear_envelope_mm": [64.0, 60.0],
    "battery_rect_xyxy_mm": [21.0, 4.0, 85.0, 64.0],
    "footprints": geometry["footprints"],
    "locked_footprints": geometry["locked_footprints"],
    "newly_locked_refs": newly_locked,
    "tracks": geometry["tracks"],
    "zones": geometry["zones"],
    "native_checks": counts,
    "refs": len(target_refs),
    "pin_net_tuples": len(target_tuples),
    "key_positions": geometry["positions"],
    "placement_csv": "verification/placement.csv",
    "placement_gates": {
        "board_under_100x100": True,
        "all_footprints_locked": True,
        "native_drc_zero": True,
        "schematic_parity_zero": True,
        "erc_zero": True,
        "battery_envelope_inherited_from_c1": True,
        "physical_fpc_fit": False,
        "battery_thickness_swelling_harness": False,
        "enclosure_z_stack": False,
    },
    "routing_authority": False,
    "manufacturing_release": False,
    "physical_qualification_complete": False,
    "pcb_sha256": hashlib.sha256(PCB.read_bytes()).hexdigest(),
}
(DST / "c4d11-placement-report.json").write_text(json.dumps(report, ensure_ascii=False, indent=2) + "\n")
# Native KiCad checks may create per-user session files; never publish them.
for session_file in DST.rglob("*.kicad_prl"):
    session_file.unlink()
for lock_file in DST.rglob("*.lck"):
    lock_file.unlink()

(DST / "README.md").write_text(
    "# Thin18 Compact C4D-11 — final placement checkpoint\n\n"
    "All 189 footprints are locked on the 96 × 68 mm compact board. No reference, pose, net or footprint geometry changed from C4D-10B.\n\n"
    f"Fresh checks: ERC={counts['erc']}, DRC={counts['drc']}, parity={counts['parity']}, open={counts['open']}. "
    "The checkpoint is intentionally unrouted and is the input to controlled DSN/SES routing.\n\n"
    "Physical battery/FPC/enclosure qualification remains open. Not a manufacturing release.\n"
)
print(json.dumps(report, ensure_ascii=False, indent=2))

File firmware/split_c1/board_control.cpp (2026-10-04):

#include "board_control.hpp"

namespace panda::split_c1 {
using namespace binding;
namespace {
constexpr std::uint8_t kChargerOffMask = 0x70; // WD_RST, OTG_CONFIG, CHG_CONFIG
constexpr std::uint8_t kStableChargerOffMask = 0x30;
constexpr std::uint8_t kWatchdogAndTimerMask = 0x38;
constexpr std::uint8_t kWatchdogAndTimer = 0x18; // 40s watchdog; charge safety timer ON
constexpr std::uint8_t kInputMask = 0x9F;
}

bool BoardControl::read(std::uint8_t a, std::uint8_t r, std::uint8_t& v) noexcept {
    if (!bus_.read8(a, r, v, kTransferTimeoutMs)) {
        io_error_ = Result::BusError;
        return false;
    }
    return true;
}

bool BoardControl::expect(std::uint8_t a, std::uint8_t r, std::uint8_t mask,
                          std::uint8_t bits) noexcept {
    std::uint8_t actual = 0;
    if (!read(a, r, actual)) return false;
    if ((actual & mask) != (bits & mask)) {
        io_error_ = Result::ReadbackMismatch;
        return false;
    }
    return true;
}

bool BoardControl::write_checked(std::uint8_t a, std::uint8_t r, std::uint8_t v,
                                 std::uint8_t mask) noexcept {
    if (!bus_.write8(a, r, v, kTransferTimeoutMs)) {
        // A failed transaction MAY have reached silicon. Do not assume no write.
        io_error_ = Result::BusError;
        return false;
    }
    return expect(a, r, mask, v);
}

bool BoardControl::update(std::uint8_t a, std::uint8_t r, std::uint8_t mask,
                          std::uint8_t bits) noexcept {
    std::uint8_t v = 0;
    if (!read(a, r, v)) return false;
    return write_checked(a, r, static_cast<std::uint8_t>((v & ~mask) | (bits & mask)), mask);
}

bool BoardControl::quiesce_expander() noexcept {
    // First release P14 (including an MCU-only restart with retained XL state).
    // P15 remains unused/input. PWM falls low while Port1 is input.
    bool ok = write_checked(kExpander, 0x07, 0xFF);
    const bool out0 = write_checked(kExpander, 0x02, kQuiescent0);
    const bool out1 = write_checked(kExpander, 0x03, kQuiescent1);
    ok = write_checked(kExpander, 0x04, 0) && ok;
    ok = write_checked(kExpander, 0x05, 0) && ok;
    // Never enable output directions after an unverified output-latch write.
    if (out0) ok = write_checked(kExpander, 0x06, kDirection0) && ok;
    if (out1) ok = write_checked(kExpander, 0x07, kDirection1) && ok;
    output1_ = kQuiescent1;
    return ok && out0 && out1;
}

bool BoardControl::permit(bool high) noexcept {
    const bool written = bus_.set_hardware_permit(high);
    bool actual = true;
    const bool sampled = bus_.read_hardware_permit(actual);
    diagnostics_.hardware_inhibit_confirmed = sampled && !actual;
    if (!written || !sampled) { io_error_ = Result::BusError; return false; }
    if (actual != high) { io_error_ = Result::ReadbackMismatch; return false; }
    return true;
}

bool BoardControl::light_off() noexcept {
    // First disable through native GPIO, even if every I2C transfer now fails.
    const bool direct = permit(false);
    const bool pwm = update(kExpander, 0x03, kFrontlightPwm, 0);
    output1_ = 0;
    light_ = diagnostics_.hardware_inhibit_confirmed ? LightState::Off : LightState::Unknown;
    return direct && pwm;
}

Result BoardControl::fail(Result reason) noexcept {
    initialized_ = false;
    diagnostics_.fault = reason;
    // GPIO hardware permit is first; attempt all remaining shutdown paths
    // even if a preceding path failed. Do not silently clear the original fault.
    light_off();
    const bool gpio_ok = quiesce_expander();
    bool charger_ok = false;
    if (charger_identified_) {
        const bool off = update(kCharger, 0x01, kChargerOffMask, 0);
        const bool zero = update(kCharger, 0x02, 0x3F, 0);
        const bool limit = update(kCharger, 0x00, 0x1F, 0);
        charger_ok = off && zero && limit;
    }
    diagnostics_.shutdown_registers_confirmed = gpio_ok && charger_ok;
    light_ = diagnostics_.hardware_inhibit_confirmed ? LightState::Off : LightState::Unknown;
    return reason;
}

bool BoardControl::capture_faults(bool allow_detection) noexcept {
    std::uint8_t history = 0, current = 0, flags = 0;
    if (!read(kCharger, 0x09, history)) return false;
    diagnostics_.charger_history = static_cast<std::uint8_t>(diagnostics_.charger_history | history);
    if (!read(kCharger, 0x09, current)) return false;
    diagnostics_.charger_current = current;
    if (!read(kCharger, 0x0E, flags)) return false;
    diagnostics_.charger_flags = static_cast<std::uint8_t>(diagnostics_.charger_flags | flags);
    if ((flags & 0x80) && !allow_detection) {
        // A new input detection revokes the previous source grant even if its
        // PSEL-selected current code happens to equal the old500mA grant.
        io_error_ = Result::SourceChanged;
        return false;
    }
    if ((history | current) != 0) {
        io_error_ = Result::ChargerFault;
        return false;
    }
    return true;
}
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

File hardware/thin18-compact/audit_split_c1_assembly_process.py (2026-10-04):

#!/usr/bin/env python3
"""Read-only native SMT/via process screen, distinct from electrical DRC.

Uses KiCad's saved copper polygons, not bounding-box overlap or library labels.
No CAD/plot/clearance edits; no inference of accepted CAM, stencil or assembly.
"""
import csv
import hashlib
import io
import json
import math
from collections import Counter, defaultdict
from pathlib import Path
from _split_c1_common import ROOT, REPO, REL, STEM, repo_entry, sha
from _split_c1_fabrication import require, load_contract

REPORT = ROOT / 'split-c1-assembly-process.json'
RENDER_ERROR_MM = 0.001
SMALL_LAND_MM = 0.25


def point_to_polygon(point, polygon):
    """Distance to a filled simple polygon, zero on its interior/boundary."""
    require(len(polygon) >= 3, 'Degenerate pad polygon')
    require(all(len(p) == 2 and all(math.isfinite(v) for v in p) for p in [point, *polygon]),
            'Invalid/nonfinite pad geometry')
    area2 = sum(a[0]*b[1]-b[0]*a[1] for a,b in zip(polygon,polygon[1:]+polygon[:1]))
    require(abs(area2) > 1e-12, 'Degenerate zero-area pad polygon')
    inside = False
    distance = math.inf
    for a, b in zip(polygon, polygon[1:] + polygon[:1]):
        dx, dy = b[0]-a[0], b[1]-a[1]
        length2 = dx*dx + dy*dy
        t = max(0., min(1., ((point[0]-a[0])*dx + (point[1]-a[1])*dy)/length2)) if length2 else 0.
        distance = min(distance, math.hypot(point[0]-a[0]-t*dx, point[1]-a[1]-t*dy))
        if (a[1] > point[1]) != (b[1] > point[1]):
            cross = (b[0]-a[0])*(point[1]-a[1])/(b[1]-a[1]) + a[0]
            if point[0] < cross:
                inside = not inside
    return 0. if inside else distance


def hole_overlap(center, diameter, polygons):
    require(math.isfinite(diameter) and diameter > 0 and polygons, 'Missing/invalid drill or pad')
    distance = min(point_to_polygon(center, polygon) for polygon in polygons)
    gap = distance - diameter/2
    if gap > RENDER_ERROR_MM:
        return None
    return {'classification': 'center_in_land' if distance < 1e-9 else
            'hole_crosses_land_edge' if gap <= 0 else 'within_polygon_render_tolerance',
            'nominal_hole_to_land_gap_mm': round(gap, 6)}


def polygon_identity(polygons):
    """Stable shape identity; old pads lacking stored UUIDs get random load UUIDs."""
    rings = []
    for points in polygons:
        ring = tuple(tuple(p) for p in points)
        if ring and ring[0] == ring[-1]:
            ring = ring[:-1]
        require(len(ring) >= 3, 'Missing pad identity geometry')
        candidates = []
        for direction in [ring, tuple(reversed(ring))]:
            start = min(range(len(direction)), key=lambda i: direction[i])
            candidates.append(direction[start:] + direction[:start])
        rings.append(min(candidates))
    require(rings, 'Missing pad polygons')
    return hashlib.sha256(json.dumps(sorted(rings),separators=(',',':')).encode()).hexdigest()


def inspect_board(path):
    import pcbnew as P
    before = sha(path)
    board = P.LoadBoard(str(path))
    xy = lambda p: [round(P.ToMM(p.x), 6), round(P.ToMM(p.y), 6)]
    vias = sorted((t for t in board.GetTracks() if isinstance(t, P.PCB_VIA)),
                  key=lambda v: str(v.m_Uuid.AsString()))
    inventory = []
    for via in vias:
        require(via.TopLayer() == P.F_Cu and via.BottomLayer() == P.B_Cu,
                'Blind/buried vias require a separate process audit')
        diameter = [round(P.ToMM(via.GetWidth(layer)), 6) for layer in [P.F_Cu, P.B_Cu]]
        hole = round(P.ToMM(via.GetDrill()), 6)
        require(hole > 0 and min(diameter) > hole, 'Invalid native via land/drill')
        inventory.append({'uuid': str(via.m_Uuid.AsString()), 'center_mm': xy(via.GetPosition()),
                          'net': str(via.GetNetname()), 'drill_mm': hole,
                          'front_copper_diameter_mm': diameter[0], 'back_copper_diameter_mm': diameter[1]})
    require(len({v['uuid'] for v in inventory}) == len(inventory), 'Duplicate native via UUID')
    hits, small = [], defaultdict(list)
    all_positions = defaultdict(set)
    identities = {}
    for footprint in board.GetFootprints():
        if footprint.IsDNP() or footprint.IsExcludedFromBOM():
            continue
        ref = footprint.GetReference()
        fields = {f.GetName(): f.GetText() for f in footprint.GetFields()}
        identities[ref] = {'mpn': fields.get('MPN', ''), 'value': str(footprint.GetValue())}
        for pad in footprint.Pads():
            if pad.GetAttribute() != P.PAD_ATTRIB_SMD:
                continue
            for layer, mask, paste, side in [(P.F_Cu,P.F_Mask,P.F_Paste,'F.Cu'),
                                             (P.B_Cu,P.B_Mask,P.B_Paste,'B.Cu')]:
                if not pad.IsOnLayer(layer):
                    continue
                shapes = P.SHAPE_POLY_SET()
                pad.TransformShapeToPolygon(shapes, layer, 0, P.FromMM(RENDER_ERROR_MM), P.ERROR_OUTSIDE)
                require(all(shapes.HoleCount(i) == 0 for i in range(shapes.OutlineCount())),
                        'Custom pad voids need explicit polygon-hole support')
                polygons = [[xy(shapes.Outline(i).CPoint(j))
                             for j in range(shapes.Outline(i).PointCount())]
                            for i in range(shapes.OutlineCount())]
                require(polygons, 'Empty native SMT copper shape')
                size = xy(pad.GetSize())
                if pad.GetShape() == P.PAD_SHAPE_CUSTOM:
                    # A custom pad's nominal anchor is not its solderable extent.
                    pts = [p for polygon in polygons for p in polygon]
                    size = [round(max(p[i] for p in pts)-min(p[i] for p in pts),6) for i in range(2)]
                all_positions[(ref, side)].add(tuple(xy(pad.GetPosition())))
                if min(size) <= SMALL_LAND_MM + 1e-6 and pad.IsOnLayer(mask):
                    small[(ref, side)].append({'pad': pad.GetNumber(), 'size_mm': size})
                if not pad.IsOnLayer(mask):
                    continue
                for via, entry in zip(vias, inventory):
                    if not via.IsOnLayer(layer):
                        continue
                    overlap = hole_overlap(entry['center_mm'], entry['drill_mm'], polygons)
                    if overlap is None:
                        continue
                    require(entry['net'] == str(pad.GetNetname()), 'Different-net via overlaps an SMT land')
                    hits.append({'via_uuid': entry['uuid'], 'ref': ref, 'pad': pad.GetNumber(),
                                 'pad_shape_sha256': polygon_identity(polygons), 'side': side, 'net': entry['net'],
                                 'center_mm': entry['center_mm'], 'drill_mm': entry['drill_mm'],
                                 'via_copper_diameter_mm': entry['front_copper_diameter_mm' if side == 'F.Cu' else 'back_copper_diameter_mm'],
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

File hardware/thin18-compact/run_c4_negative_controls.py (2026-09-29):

#!/usr/bin/env python3
import csv,json,shutil,subprocess,tempfile
from pathlib import Path

ROOT=Path(__file__).resolve().parent
VERIFY=ROOT/'verify_c4.py'
tests=[]

def run_expect_fail(name, mutator, paths):
    backups={}
    try:
        for p in paths:
            p=ROOT/p
            backups[p]=p.read_bytes()
        mutator()
        cp=subprocess.run(['python3',str(VERIFY)],stdout=subprocess.DEVNULL,stderr=subprocess.DEVNULL)
        ok=cp.returncode==2
        tests.append({'name':name,'exit':cp.returncode,'passed':ok})
        if not ok: raise SystemExit(f'negative control did not fail: {name}, exit={cp.returncode}')
    finally:
        for p,b in backups.items(): p.write_bytes(b)

def mut_mpn():
    base=ROOT/'c4c-96x68-domestic-passives/eda/core/PANDA-STD-CORE-EVT/PANDA-THIN16'
    # C302 is in the root schematic. Mutate source metadata, not generated verification evidence.
    p=base/'PANDA-STD-CORE-EVT-quilter-j501-merged.kicad_sch'
    s=p.read_text()
    marker='(property "Reference" "C302"'
    i=s.index(marker)
    j=s.find('(property "MPN" "0402B104K250NT"',i)
    if j < 0: raise SystemExit('C302 selected MPN source field not found')
    s=s[:j]+s[j:].replace('0402B104K250NT','BROKEN_MPN',1)
    p.write_text(s)
run_expect_fail('selected schematic MPN mutation rejected',mut_mpn,['c4c-96x68-domestic-passives/eda/core/PANDA-STD-CORE-EVT/PANDA-THIN16/PANDA-STD-CORE-EVT-quilter-j501-merged.kicad_sch'])

def mut_ref():
    p=ROOT/'c4-domestic-ref-status.csv'
    rows=list(csv.reader(p.open(encoding='utf-8-sig')))
    rows=rows[:-1]
    with p.open('w',newline='',encoding='utf-8') as f: csv.writer(f,lineterminator='\n').writerows(rows)
run_expect_fail('missing ref status rejected',mut_ref,['c4-domestic-ref-status.csv'])

def mut_phy():
    p=ROOT/'c4-qualification-gates.json'; d=json.load(open(p)); d['gates'][0][2]='PASS'; d['physical_tests_completed']=1; p.write_text(json.dumps(d,indent=2)+'\n')
run_expect_fail('physical PASS without raw measurements rejected',mut_phy,['c4-qualification-gates.json'])

def mut_switch():
    p=ROOT/'c4-power-architecture.json'; d=json.load(open(p)); d['load_switch_policy']['domesticization_status']='SELECTED'; p.write_text(json.dumps(d,indent=2)+'\n')
run_expect_fail('unsafe load-switch selection rejected',mut_switch,['c4-power-architecture.json'])

cp=subprocess.run(['python3',str(VERIFY),'--release'],stdout=subprocess.DEVNULL,stderr=subprocess.DEVNULL)
tests.append({'name':'release gate blocked','exit':cp.returncode,'passed':cp.returncode==2})
if cp.returncode!=2: raise SystemExit('release gate negative control failed')

report={'date':'2026-09-29','tests':tests,'passed':all(t['passed'] for t in tests)}
(ROOT/'c4-negative-controls.json').write_text(json.dumps(report,indent=2)+'\n')
print(json.dumps(report,indent=2))

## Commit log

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2026-09-29 Publish initial Panda Standard Board hardware design
    Publish curated Thin18 routing142 KiCad design sources, board design documentation, verification evidence, and open-hardware licensing.
    [PANDA-EPD0426-SPI-EVT.kicad_pcb, PANDA-EPD0426-SPI-EVT.kicad_sch, PANDA-STD-CORE-EVT-quilter-j501-merged.kicad_pcb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]
2026-09-29 feat(hw): start Thin18 compact EVT architecture
    [PANDA-EPD0426-SPI-EVT.kicad_pcb, PANDA-EPD0426-SPI-EVT.kicad_sch, PANDA-STD-CORE-EVT-quilter-j501-merged.kicad_pcb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]
2026-09-29 feat(hw): add Thin18 compact C1 battery-ring placement
    [PANDA-EPD0426-SPI-EVT.kicad_pcb, PANDA-EPD0426-SPI-EVT.kicad_sch, PANDA-STD-CORE-EVT-quilter-j501-merged.kicad_pcb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]
2026-09-29 feat(hw): freeze compact FT01C display contract
    [PANDA-EPD0426-SPI-EVT.kicad_pcb, PANDA-EPD0426-SPI-EVT.kicad_sch, PANDA-STD-CORE-EVT-quilter-j501-merged.kicad_pcb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]
2026-09-29 feat(hw): reserve compact touch and frontlight integration
    [PANDA-EPD0426-SPI-EVT.kicad_pcb, PANDA-EPD0426-SPI-EVT.kicad_sch, PANDA-STD-CORE-EVT-quilter-j501-merged.kicad_pcb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]
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2026-09-29 feat(hw): start comprehensive Thin18 domesticization
    [PANDA-EPD0426-SPI-EVT.kicad_pcb, PANDA-EPD0426-SPI-EVT.kicad_sch, PANDA-STD-CORE-EVT-quilter-j501-merged.kicad_pcb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]
2026-09-29 docs(hw): track C4 domesticization by reference
    [c4-domestic-ref-status.csv]
2026-09-29 feat(hw): close C4 domesticization checks
    [PANDA-EPD0426-SPI-EVT.kicad_pcb, PANDA-EPD0426-SPI-EVT.kicad_sch, PANDA-STD-CORE-EVT-quilter-j501-merged.kicad_pcb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]
2026-09-29 feat(hw): freeze C4D power pin-level migration
    [c4d-power-net-migration.csv]
2026-09-29 feat(hw): advance C4D domestic power integration
    [PANDA-EPD0426-SPI-EVT.kicad_pcb, PANDA-EPD0426-SPI-EVT.kicad_sch, PANDA-STD-CORE-EVT-quilter-j501-merged.kicad_pcb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]
2026-09-29 feat(hw): integrate domestic SGM41513 charger
    [PANDA-EPD0426-SPI-EVT.kicad_pcb, PANDA-EPD0426-SPI-EVT.kicad_sch, PANDA-STD-CORE-EVT-quilter-j501-merged.kicad_pcb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]
2026-09-29 feat(hw): integrate SGM62125 and passive USB-C
    [PANDA-EPD0426-SPI-EVT.kicad_pcb, PANDA-EPD0426-SPI-EVT.kicad_sch, PANDA-STD-CORE-EVT-quilter-j501-merged.kicad_pcb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]
2026-09-29 feat(hw): correct compact IMU to QMI8658A
    [PANDA-EPD0426-SPI-EVT.kicad_pcb, PANDA-EPD0426-SPI-EVT.kicad_sch, PANDA-STD-CORE-EVT-quilter-j501-merged.kicad_pcb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]
2026-09-29 feat(hw): integrate domestic CW2217 fuel gauge
    [PANDA-EPD0426-SPI-EVT.kicad_pcb, PANDA-EPD0426-SPI-EVT.kicad_sch, PANDA-STD-CORE-EVT-quilter-j501-merged.kicad_pcb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]
2026-09-29 feat(hw): integrate domestic NS4168 audio
    [PANDA-EPD0426-SPI-EVT.kicad_pcb, PANDA-EPD0426-SPI-EVT.kicad_sch, PANDA-STD-CORE-EVT-quilter-j501-merged.kicad_pcb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]
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2026-09-29 feat(hw): complete domestic EPD Schmitt buffers
    [PANDA-EPD0426-SPI-EVT.kicad_pcb, PANDA-EPD0426-SPI-EVT.kicad_sch, PANDA-STD-CORE-EVT-quilter-j501-merged.kicad_pcb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]
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2026-10-01 feat(hw): close split Core-C1 and Display-C1 production candidates
    [BOM_JLCPCB.csv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]
2026-10-01 feat(hw): audit split stack and verify exact-part sourcing
    [BOM_JLCPCB.csv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]
2026-10-01 chore(hw): trim PR artifacts and make split release reproducible
    [BOM_JLCPCB.csv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]
2026-10-01 hw: prepare split-board sourcing, mechanical envelope and EVT plan
    [PANDA-STD-CORE-EVT-quilter-j501-merged.kicad_pcb, evt-interfaces.kicad_sch, fixture-bom.csv]
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2026-10-01 hw: correct prototype footprints and prepare Split-C1 JLC CAM handoff
    [PANDA-EPD0426-SPI-EVT.kicad_pcb, PANDA-STD-CORE-EVT-quilter-j501-merged.kicad_pcb, PANDA-STD-CORE-EVT-quilter-j501-merged.kicad_sch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]
2026-10-01 hw: apply reviewed domestic ECOs and gate incomplete Split-C1 orders
    [PANDA-EPD0426-SPI-EVT.kicad_pcb, PANDA-EPD0426-SPI-EVT.kicad_sch, PANDA-STD-CORE-EVT-quilter-j501-merged.kicad_pcb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]
2026-10-02 hw: apply domestic wire, FPC and inductor ECOs with replay guards
    [PANDA-EPD0426-SPI-EVT.kicad_pcb, PANDA-EPD0426-SPI-EVT.kicad_sch, PANDA-STD-CORE-EVT-quilter-j501-merged.kicad_pcb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]
2026-10-02 hw: replace USB-C with MUP and clear standard board-edge DFM
    [PANDA-STD-CORE-EVT-quilter-j501-merged.kicad_pcb, usb-interface.kicad_sch]
2026-10-02 hw: replace side buttons with XKB A1 no-post switches
    [PANDA-STD-CORE-EVT-quilter-j501-merged.kicad_pcb, PANDA-STD-CORE-EVT-quilter-j501-merged.kicad_sch]
2026-10-02 hw: replace Split-C1 VBUS TVS with polarized SGMICRO protection
    [PANDA-STD-CORE-EVT-quilter-j501-merged.kicad_pcb, usb-interface.kicad_sch]
2026-10-02 hardware: close three imported Split-C1 refs and two SMT maps
    [PANDA-EPD0426-SPI-EVT.kicad_pcb, PANDA-EPD0426-SPI-EVT.kicad_sch, PANDA-STD-CORE-EVT-quilter-j501-merged.kicad_pcb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]
2026-10-02 hw: apply XUNPU microSD and reviewed Sunlord MT inductor ECOs
    [PANDA-STD-CORE-EVT-quilter-j501-merged.kicad_pcb, PANDA-STD-CORE-EVT-quilter-j501-merged.kicad_sch]
2026-10-02 hw: complete Split-C1 domestic RTC backup and EPD MOS ECO
    [PANDA-EPD0426-SPI-EVT.kicad_pcb, PANDA-EPD0426-SPI-EVT.kicad_sch, PANDA-STD-CORE-EVT-quilter-j501-merged.kicad_pcb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]
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2026-10-02 fix(hardware): use exact H3C capacitor with 20mm leads
    [PANDA-STD-CORE-EVT-quilter-j501-merged.kicad_pcb, SPLIT-C1-ENCLOSURE-STUDY.scad, evt-interfaces.kicad_sch]
2026-10-02 Define 7mm two-board mechanical redesign and gate incompatible PCB release
    [Core-Thin7-OUTLINE-ONLY.kicad_pcb, Display-Thin7-OUTLINE-ONLY.kicad_pcb, SPLIT-C1-ENCLOSURE-STUDY.scad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]
2026-10-04 hw: implement Split-C1 PG monitor and pre-AON PSEL bias
    [PANDA-STD-CORE-EVT-quilter-j501-merged.kicad_pcb, PANDA-STD-CORE-EVT-quilter-j501-merged.kicad_sch]
2026-10-04 hw: finish Split-C1 default-off charging and direct GPIO inhibit
    [PANDA-STD-CORE-EVT-quilter-j501-merged.kicad_pcb, PANDA-STD-CORE-EVT-quilter-j501-merged.kicad_sch]
2026-10-04 hw: close C301 drill manufacturability and verify Split-C1 fabrication packets
    [PANDA-STD-CORE-EVT-quilter-j501-merged.kicad_pcb, evt-interfaces.kicad_sch]
2026-10-04 fix: make Split-C1 process reports stable across native reloads
    [audit_split_c1_assembly_process.py]
2026-10-04 hw: close reviewed via escapes and supervisor sourcing on develop
    [PANDA-STD-CORE-EVT-quilter-j501-merged.kicad_pcb, PANDA-STD-CORE-EVT-quilter-j501-merged.kicad_sch]
2026-10-04 fix: keep full-product camera movement continuous across labels
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2026-10-13 fix(pico47): target original pad groups and record verified EN closure
    Add exact original-group repair selection with 18 new regression cases, including all 2,704 five-pad partition pairs. The 165-test Pico47 suite passed on the connected Mac. Record five natively verified signal closures and explicit offline recovery boundaries. Generated CAD stays external; no combined final PCB release or physical qualification is claimed.
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2026-10-14 wip(pico47): preserve CKV native progress and tested panel-control report
    Draft recovery after remote command/file reads stopped responding. Native combined candidate: Core33/Display9 opens, errors/warnings/parity/ERC0, all ground pads retained. CKV passes; supply detour shortened without added power vias. Final clean-source replay result and working-delivery publication remain unconfirmed. Inspector integration remains an uncommitted local change and is explicitly documented; this commit adds helper, tests and progress handoff only.
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2026-10-26 feat(pico47): add r25 Core routing tools and handoff
    Grid router (PathFinder, vertex-cover legalisation, pin-swap groups) and the
    geometry/KiCad helper scripts used to reroute the Core MCU/mux region, plus
    the r25 handoff. Best legal state is 77/81 on the E26 working geometry; the
    board is not complete and not for fabrication. Generated geometry, states
    and trial boards stay in the ignored .work directory.
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2026-10-27 docs(pico47): record UART SD source swap scan
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2026-10-27 docs(pico47): record corrected J601 materialization
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2026-10-28 fix(pico47): preserve mux names after channel swaps
    Keep the common-side net name when finalizing R25 routes so remapped UART channels do not share a mux net.
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2026-10-28 docs(pico47): record fixed topology ground search
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2026-10-30 feat(pico47): resolve r25 sample-readiness review findings for v0.1.1 (r26)
    - Retract Single.kicad_pcb upper-left step from X=30.0mm to X=38.0mm (Y=32.0..83.5mm) for 0.0 mm^2 overlap with 323576 (35x76x3.2mm) battery and reroute with 0 opens / 0 DRC / 0 parity / 0 ERC
    - Move C804.2 ground return via to external dog-bone at (17.40, 104.80) (0.45/0.20mm) and document U501.57 9x 0.50/0.25mm thermal vias as STANDARD_4L_TENTED_THERMAL_VIAS
    - Unify J201 USB-C receptacle MPN as MUP U22401-17 across docs and preserve PENDING-SUPPLY.csv (21 SMT items) and REQUIRED-POST-SMT.csv (BT301)
    - Add single_board.json, build_pico47_single.py, and test_pico47_single.py for Single PCB verification and orderpack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
2026-10-30 fix(pico47): replay full R25->R26 ECO without crash, enforce 0.0mm2 full battery assembly clearance & U501.57 VIP gate
2026-10-30 fix(pico47): restore full 35x76x3.2mm battery assembly with 0.0mm2 overlap and enforce SHA256/UUID checks in R26 ECO
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2026-11-02 fix(pico47): preserve native geometry and through-via routing constraints
    Keep native zone holes and priorities, account for copper on every through-via layer, and retain branch connectivity through new via junctions. Cover rounded-pad and nanometre boundary cases with local native regressions.
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2026-11-02 fix(pico47): move the PMIC reference filter close to VREF
    Retain the existing single 100 nF C815 and all part/pad identities. Move it to the back near U810 and replace the old internal via junction with an explicit guarded copper connection.
    Add a unique reference-filter contract and native regressions, bind the complete R26-to-R36 replay, and preserve engineering qualification limits. Local source tests, independent native audits and full rebuilds pass; manufacturing release remains disabled.
2026-11-02 fix(pico47): reroute PMIC feedback and switch branches
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2026-11-02 fix(pico47): close R41 C807 VGH_BASE positive charge-pump storage layout and dual-side native guard
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2026-11-03 fix(pico47): match TH801 thermistor identity to its 0402 land
2026-11-03 fix(pico47): add partial rear clock reference ground and corridor checks
2026-11-03 fix(pico47): route XSTL inner bridge around ground gap
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2026-11-06 docs(pico47): correct project description and EVT protocol to the actual design
    The LCEDA project description and the EVT protocol described parts and
    results that do not exist in the schematic or the repository status.
    Project description: mark the board as an unbuilt E0.2 R48 engineering
    candidate (manufacturing_release = false) and drop measured-thickness,
    photo, assembly-photo and video claims. Use the real parts: ESP32-S3R8 +
    GD25Q128, E0470A01 1216x684, SGM41513 / SGM62125 / CW2217 / XB7608A,
    SD3078 RTC, SGM37601 front light with PWM from U601, C808/C811 47 nF,
    J301 solder landing. Describe the SD / panel-data SGM330A multiplexing,
    list the unpowered VSYS_FL_IN front-light input as a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
2026-11-06 fix(pico47): R49 feed the front-light boost input from VSYS_RAW
    After the board merge VSYS_FL_IN (L905.1 / R920.1 / C920.1) had no
    source, so the SGM37601 front-light boost had no input in R48 and
    earlier. R49 joins it to VSYS_RAW: three schematic global labels renamed,
    three pads re-netted, the 18 existing VSYS_FL_IN segments relabelled and
    a 0.40 mm, 29 mm link (14 tracks, 4 vias, never on In1) added. All other
    parts, copper, zones and rules equal R48.
    build_pico47_single_r49.py replays R26 -> R48, checks the R48 semantic
    and copper fingerprints, applies the bound delta, checks the target
    fingerprints, runs native DRC (all track errors, schematic parity) and
    ERC, the Single inspection and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
2026-11-08 feat(pico47): R50 v0.1.3 with an all-JLC-stock BOM, TPS651851 PMIC and AW99703 front light
    - U810 SY7636ARMC (no stock) -> TI TPS651851RSLR on the same 6x6 QFN-48 land:
    thermal pad on VN, WAKEUP from U811 P04, DGND/VCOM_PWR/PBKG/VEE_IN/VDDH_IN/VPOS_IN
    wired, R804 to GND (39.2k), TI typical pump/VREF caps, R805 DNP, R806 43k.
    - U905 SGM37601 (no stock) -> AWINIC AW99703CSR WLCSP-12 (LM3697-compatible),
    B2 SCL 0.25/0.15 via-in-pad under a footprint-scoped rule, C922 DNP.
    - Same-land stock swaps and thinner inductors (L401/L402 1.2 mm, L802 1.5 mm).
    - build_pico47_single_r50.py replays R26 -> R49 -> R50; copper is stored as
    geometric rules produced by router2/power_connect.
    - Mainland B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
2026-11-08 fix(pico47): R50 D201 LRC8804FDT1G (11 pcs) -> LRC8804DT1G on the same land
    Same LRC DFN2510-10 family; the datasheet pin diagram ties pins 3 and 8 to
    the ground rail, 1/2/4/5 are I/O and 6/7/9/10 are not connected, matching
    the existing D201 nets. I/O capacitance 0.6 pF max (vs 0.3 pF), fine for
    USB full speed and CC. 2383 pcs in stock. Gerbers, drill and CPL unchanged;
    native checks 0.
2026-11-10 feat(pico47): v0.2.0 Pico-class redesign, all-mainland ICs, single-sided 4-layer board
    New board, not an R-series delta. Architecture follows Read Pico: EPD D0-D15
    straight to GPIO, 1-bit microSD, one XL9535QF24, SY7636ARMC (consigned) on the
    R49 circuit, SY8089 3V3 buck, SGM3732 front light with warm/cool/mixed string
    select, SC7A20H, BM8563; NS4168 speaker kept. TI TPS651851 and Richtek RT6160
    are gone; PMIC passives move to 0603 / SOD-323 at the same ratings.
    Board: 63 x 111 mm L outline (about 2960 mm2 against about 5100 for R50) for a
    117.5 x 66.2 x 7.3 mm device, 4 layers 0.8 mm, top-side SMT only (153
    placements), 410 vias all 0.3 mm drill, 17 via-in-pad in exposed pads.
    Placed parts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
2026-11-11 fix(pico47): v0.2.0 JLC DFM fixes (U907 CPC5 land, switch post holes, J820 hold-downs, pin-1 marks)
    JLC reported these on the previous board (order Y4, v0.1.3); the footprints are shared with v0.2.0.
    - U907 XB7608AJ: CPC5 land per the XySemi drawing (e1 0.53 / e 1.06, pin 1 not mirrored); VDD and
    cell-negative stubs re-routed.
    - SW201/SW202 TS-1186E: two 0.75 mm NPTH for the locating posts; 3V3_AON and FL_C_N pass between them.
    - J820 X05A10L40G: hold-down pads 1.91 mm behind the housing edge per the XKB layout.
    - Pin-1 silk dots on U501, U810, U904, U907, Q901/Q902, J803, J804, J820.
    - Order pack: separate NPTH drill file, assembly notes in README-ORDER.
    DRC 0 / 0 unconnected / 0 parity,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
2026-11-11 feat(pico47): v0.2.1 rectangular 63 x 42 mm board (E04)
    v0.2.0 (E03) moved onto a rectangular board below a 3.2 x 50 x 70 mm cell.
    The netlist, BOM, DFM-fixed footprints and rules are the same as v0.2.0, and
    v0.2.0 is kept as the reference.
    - Board 63 x 42 mm with the mid-mount USB-C notch kept; billed area about -62 %.
    - The lower strip keeps the v0.2.0 part poses. The side-tab parts (RTC, IMU,
    3V3 buck, front-light boost and switches, fuel gauge, cell protection,
    cell pads) move to a new band along the cell edge. Buttons move to y 76.4 / 84.6.
    - Routing: Freerouting 40 passes, then local grid-router fixes on 3 signal nets
    and dangling-end trim. KiCad 10.0.7: ERC 0, DRC 0 / 0 unconne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
2026-11-11 chore(pico47): remove competitor product names from the project
    Competitor products are reference only. Their names are replaced with neutral
    wording ("the reference device", "reference-class") in docs, design.json,
    contract keys and tests, builder text, footprint/board Description fields and
    the v0.2.0 / v0.2.1 schematic title blocks (now "Panda Standard 4.7 E-reader").
    Competitor source URLs are dropped from design.json and the README.
    E03-V020-PICO-CLASS-REDESIGN-20261110.md is renamed E03-V020-REDESIGN-20261110.md.
    AGENTS.md records the rule. The internal codename pico47 is unchanged.
    Text-only change: v0.2.0 and v0.2.1 KiCad 10.0.7 ERC 0, DRC 0 / 0 unconnected /
    0 parity; regenerated G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
2026-11-12 fix(pico47): v0.2.2 order pack: drop via in C505 pad, v022 order notes
    - Remove a GND stitch via inside C505 pad 2 (0402). The pad stays on GND through its F.Cu
    tracks and the pour, so via-in-pad is back to 17. ERC 0; DRC 0 / 0 unconnected / 0 parity.
    - export_orderpack_v020.py describes the v022 outline (R4 corners) and back silkscreen,
    and adds assembly notes for the side-view LED D203, the WSON flash and the rotated microSD.
    - E05 note: order pack results (155 placements, 73 BOM lines, all stocked except the
    consigned U810).
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
